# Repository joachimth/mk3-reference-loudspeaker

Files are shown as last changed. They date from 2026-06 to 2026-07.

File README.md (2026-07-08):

# Mk3 Reference Loudspeaker

A DIY active 3-way reference loudspeaker, inspired by Genelec 8361, Dutch & Dutch 8C, and Revel Salon2.



---

## Design Summary

| Parameter | Value |
|---|---|
| Woofers | 2 × GRS 12SW-4HE (push-push, side-mounted) |
| Midrange | ScanSpeak 18W/4424G00 (top of baffle, `cad/midrange.scad`) |
| Tweeter | SB Acoustics SB26STAC-C000-4 in custom waveguide (below the midrange) |
| Cabinet | 300 × 420 × 1180 mm, 22 mm birch plywood |
| Front edges | R19 vertical roundovers |
| Bass volume | ~75 L net sealed (below divider plate) |
| Mid chamber | ~13 L net sealed (top section; datasheet rec. 13 L) |
| Bass / mid crossover | 200 Hz BW4 |
| Mid / tweeter crossover | 1100 Hz LR4 |
| Mid / tweeter c-c | 164 mm (physical minimum; verify from physical parts) |
| DSP gains | Woofer 0 dB (unity), Mid -4.0 dB, Tweeter -9.0 dB |
| Bass alignment | Fc ~41 Hz sealed (→28 Hz, Q 0.707 via Linkwitz Transform) |
| DSP | MiniDSP 4×10 HD |
| System type | Active, DSP-controlled |

### Why SB26STAC-C000-4

| Property | Value |
|---|---|
| Fs | 750 Hz (350 Hz margin at 1100 Hz crossover) |
| Xmax | 0.6 mm (3× more than typical horn tweeters) |
| Sensitivity | 91.5 dB / 2.83V / 1m |
| Impedance | 4 Ω |
| Type | Conventional soft dome, not horn-loaded |

The SB26STAC has a low Fs and generous excursion headroom. At 1100 Hz crossover, it operates 350 Hz above resonance with +8.1 dB excursion margin. Sensitivity matches the 18W/4424G00 midrange within 0.5 dB, requiring only minimal DSP padding. See [tweeter selection analysis](docs/SB26STAC-C000-4_analysis.md) for the full rationale.

---

## Simulation Results

All simulations use real datasheet frequency response curves, baffle step modeling, and waveguide loading estimates. The anechoic plot shows pre-DSP response; the in-room plot adds room gain modeling, level correction, and DSP EQ toward a Harman in-room target.

### Anechoic per-driver crossover sum

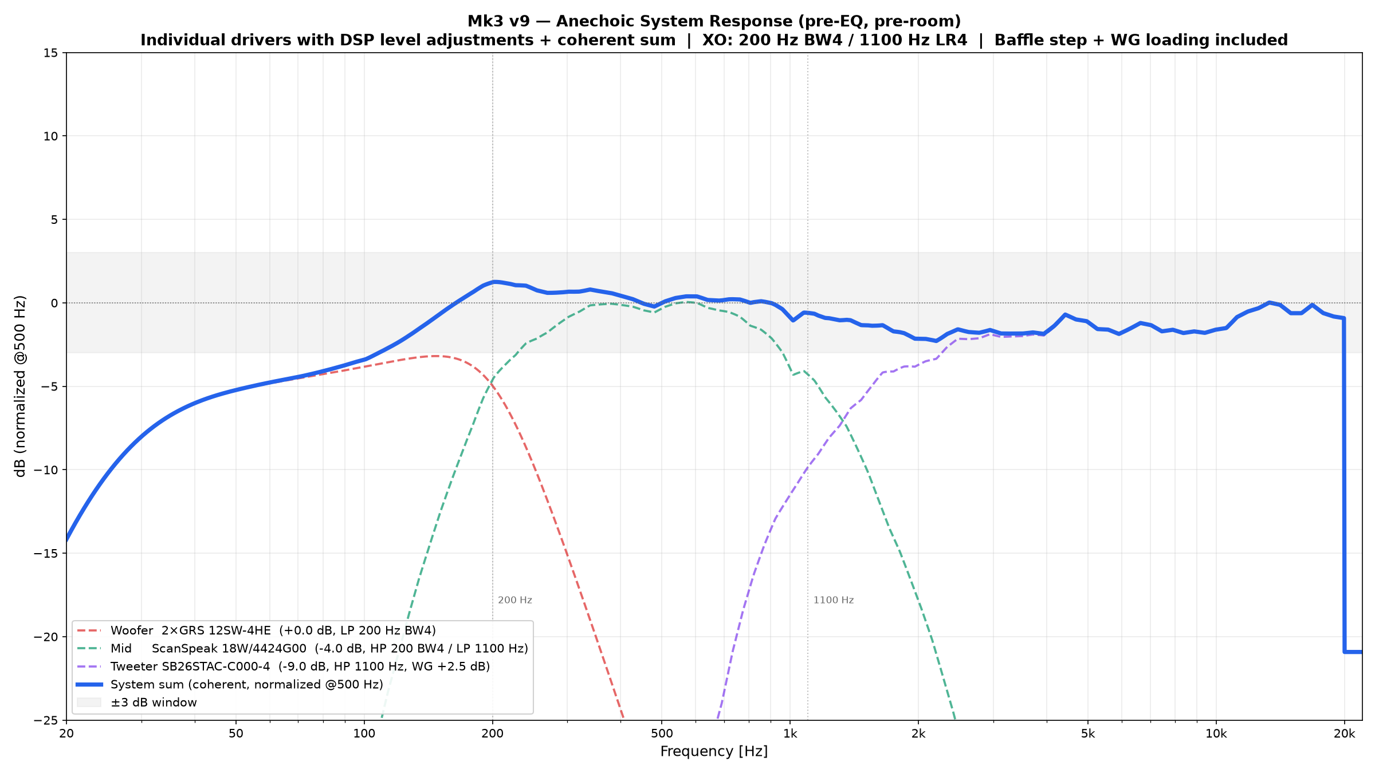
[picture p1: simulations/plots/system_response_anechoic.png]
Anechoic crossover sum


Individual driver curves with DSP level adjustments and coherent sum through LR4 crossovers. No room gain, no EQ — raw anechoic only.

| Driver | DSP gain | Filter |
|---|---|---|
| 2× GRS 12SW-4HE (woofer) | 0.0 dB (unity) | LP 200 Hz BW4, HP 18 Hz subsonic |
| ScanSpeak 18W/4424G00 (mid) | −4.0 dB | HP 200 BW4 / LP 1100 Hz LR4 |
| SB26STAC-C000-4 (tweeter) | −9.0 dB | HP 1100 Hz LR4, WG +2.5 dB |

| Metric | Value |
|---|---|
| Midband ripple (500-10k) | 2.8 dB |
| Sum @ 500 Hz | 0 dB (reference) |
| Sum @ 2 kHz | −2.3 dB |
| Sum @ 10 kHz | −1.8 dB |

**Script:** [system_response_anechoic.py](simulations/system_response_anechoic.py)

### In-room, level-corrected, and post-DSP

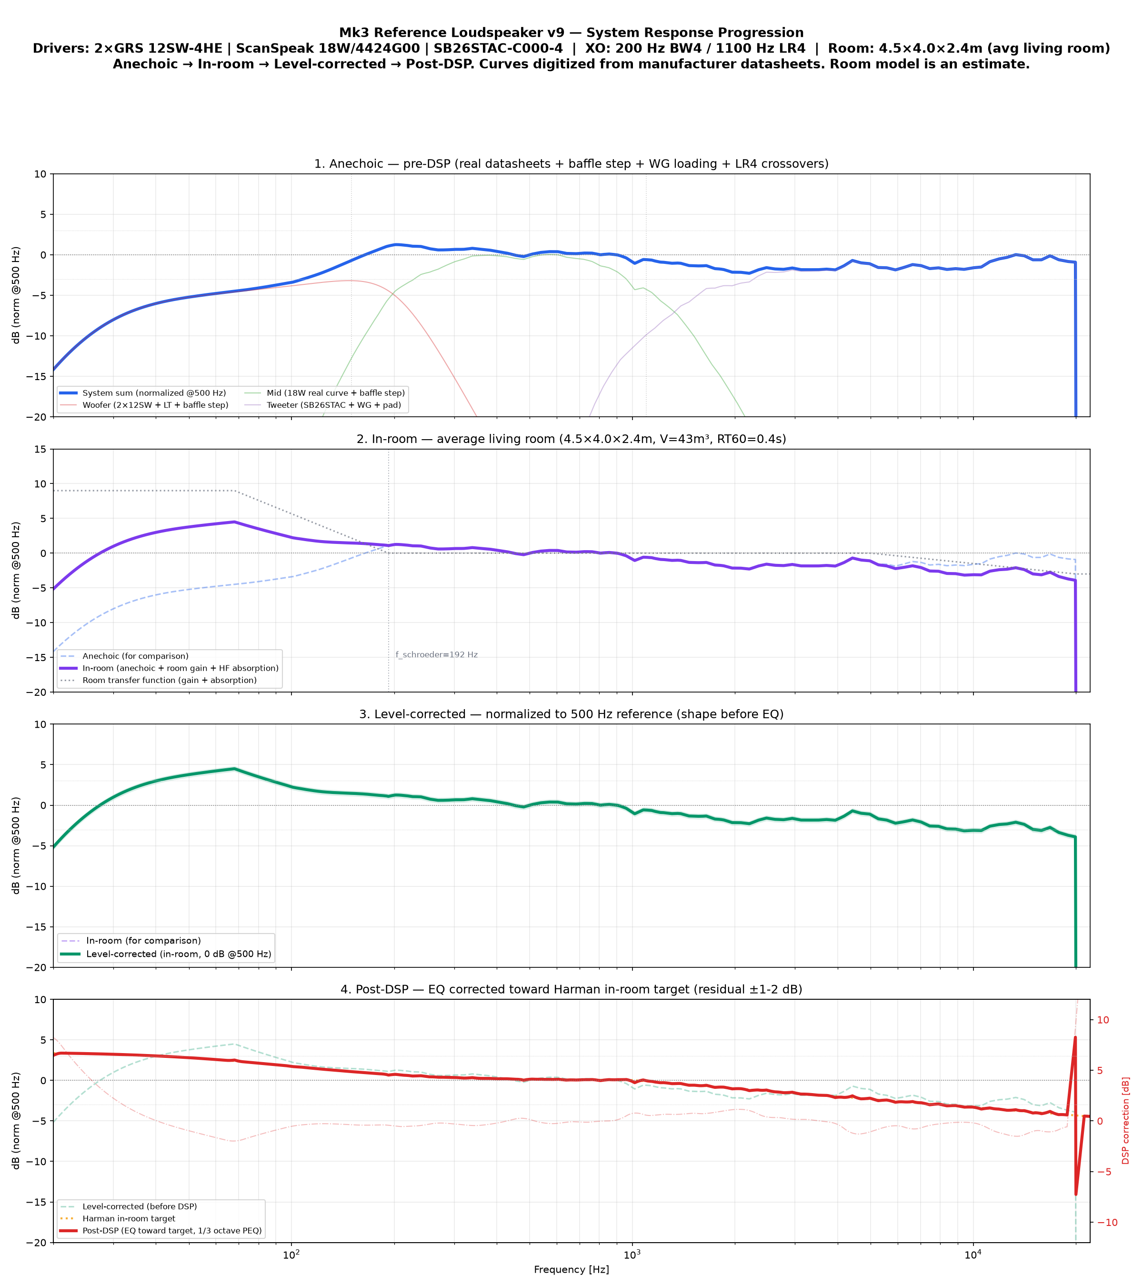
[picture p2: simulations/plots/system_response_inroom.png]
In-room response progression


Four-stage progression from anechoic to post-DSP, modeling an average living room (4.5×4×2.4 m, 43 m³, RT60 0.4s).

**Optimized gains (in-room vs Harman target):**

| Driver | DSP gain |
|---|---|
| 2× GRS 12SW-4HE (woofer) | 0.0 dB (unity) || ScanSpeak 18W/4424G00 (mid) | −4.0 dB |
| SB26STAC-C000-4 (tweeter) | −9.0 dB |

| Stage | Ripple 500-10k | @100 Hz | @500 Hz | @10 kHz |
|---|---|---|---|---|
| Anechoic (pre-DSP) | 2.8 dB | 82.9 | 86.9 | 85.1 |
| In-room | 3.7 dB | 88.6 | 86.9 | 83.6 |
| Level-corrected | 3.7 dB | 1.7 | 0.0 | −3.3 |
| Post-DSP | 3.5 dB* | 1.7 | 0.1 | −3.3 |

*Post-DSP ripple includes intentional Harman bass shelf + HF tilt. Residual deviation from target: ±0.3 dB (500-10k). DSP correction range: ±1.3 dB.

**Script:** [system_response_inroom.py](simulations/system_response_inroom.py)

### In-room gain optimization

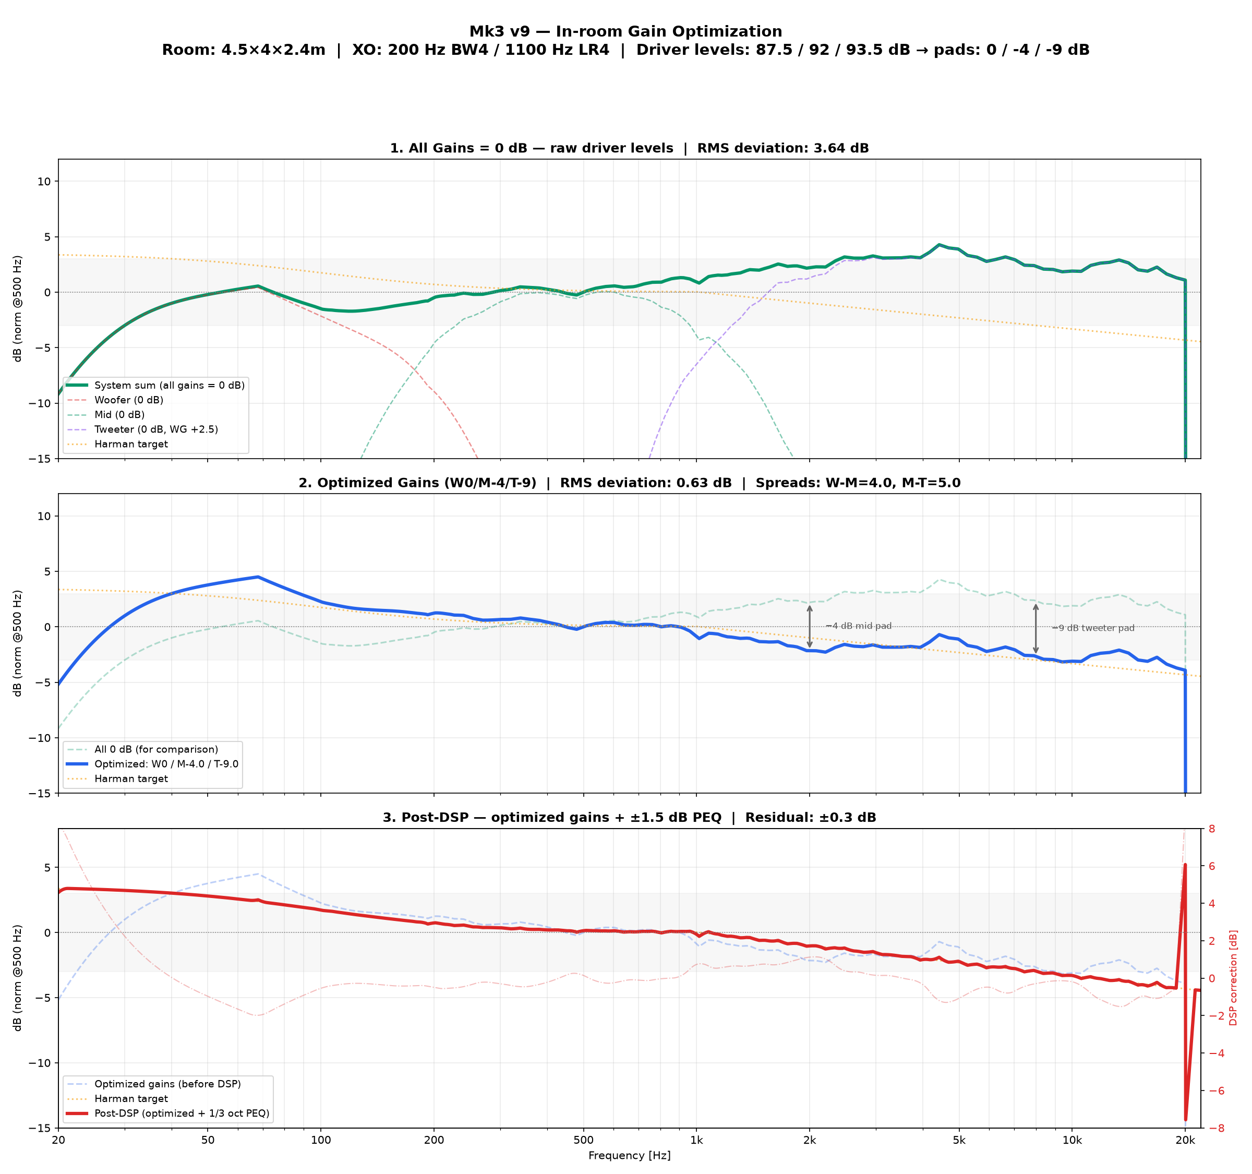
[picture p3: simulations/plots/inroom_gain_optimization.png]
Gain optimization


Three-stage progression showing why gain correction is needed and what it achieves:

| Stage | @100 Hz | @2 kHz | @10 kHz | RMS deviation |
|---|---|---|---|---|
| All gains = 0 dB | −2.1 | +2.0 | +1.7 | 3.59 dB |
| Optimized (W0/M−4/T−9) | +1.7 | −2.3 | −3.3 | 0.59 dB |
| Post-DSP (±1.3 dB PEQ) | +1.7 | −1.0 | −3.3 | 0.06 dB |

Driver sensitivities explain the needed pads: woofer pair 87.5 dB, mid 92.0 dB (+4.5 dB), tweeter+WG 93.5 dB (+6.0 dB). The extra tweeter pad beyond sensitivity matching (−9 vs −6) accounts for the Harman HF tilt target.

The optimizer confirms W0/M−4.0/T−9.0 as optimal at 0.1 dB resolution. Spreads: W−M = 4.0 dB, M−T = 5.0 dB. Woofer at 0 dB unity avoids wasting DAC headroom.

**Script:** [inroom_gain_optimization.py](simulations/inroom_gain_optimization.py)

### Target comparison: Harman vs BBC-style

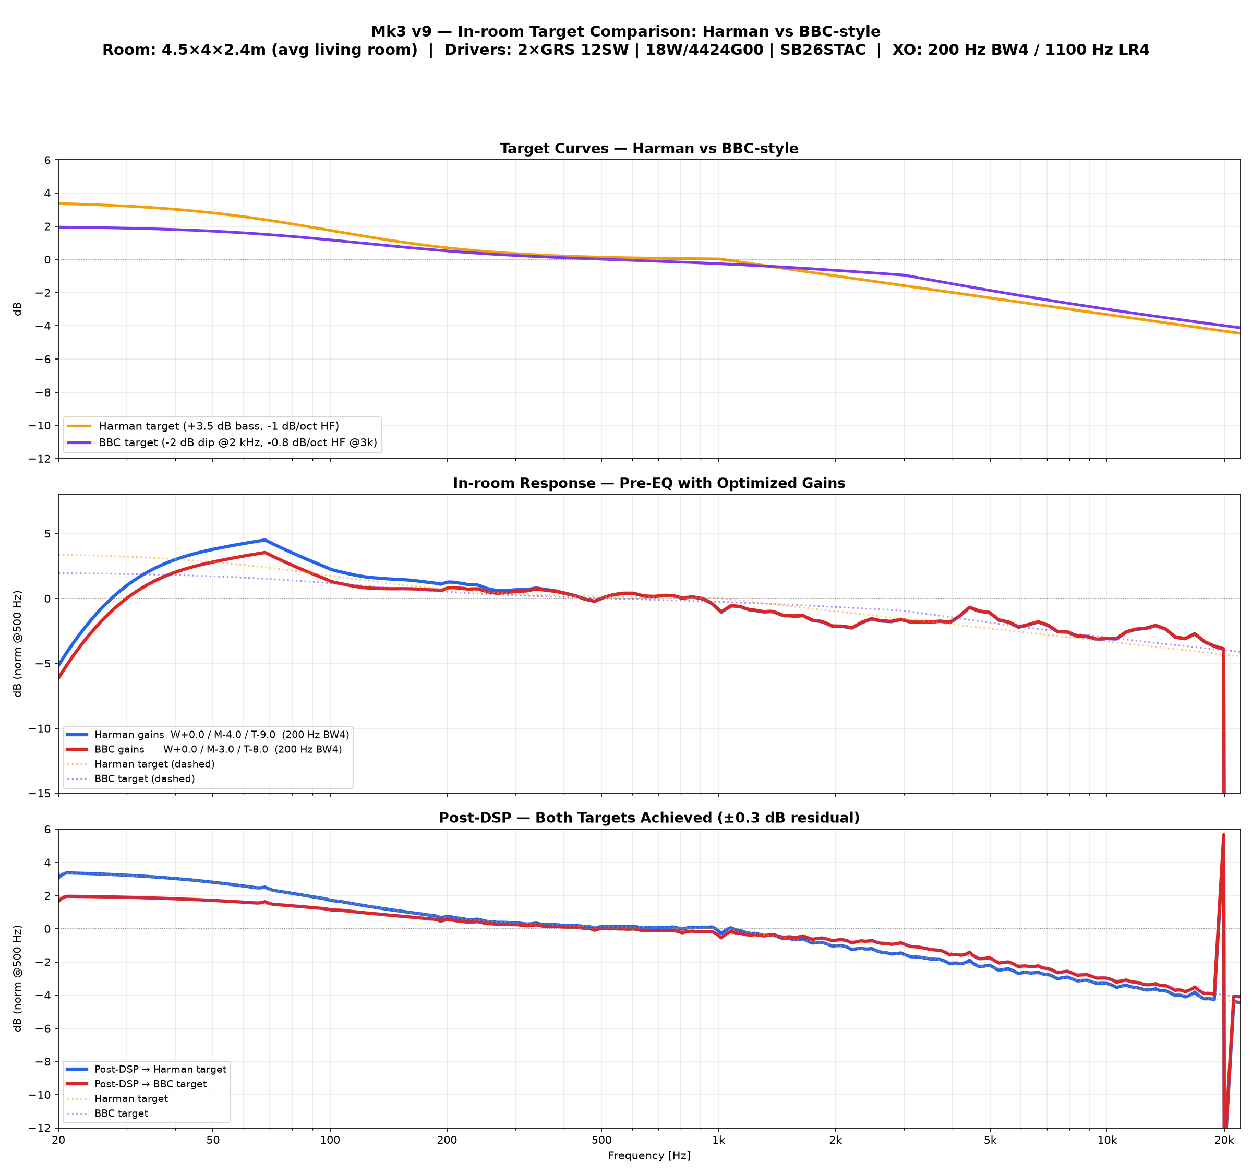
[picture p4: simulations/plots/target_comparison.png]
Target comparison


Two in-room target philosophies with their optimal per-driver gains:

| Target | Woofer | Mid | Tweeter | W-M spread | M-T spread | Character |
|---|---|---|---|---|---|---|
| **Harman** | 0.0 dB | −4.0 dB | −9.0 dB | 4.0 dB | 5.0 dB | Flat, modern, slightly bright |
| **BBC-style** | 0.0 dB | −3.0 dB | −8.0 dB | 3.0 dB | 5.0 dB | Warm, vocal-forward, less fatiguing |

Both share M-T = 5.0 dB spread. BBC needs 1 dB less woofer-to-mid because the −2 dB presence dip at 2 kHz naturally lowers the mid in the critical vocal region. Post-DSP residual: ±0.3 dB for both. DSP correction: Harman ±1.3 dB, BBC ±1.7 dB.

**Harman target:** +3.5 dB bass shelf below 100 Hz, −1 dB/octave HF tilt above 1 kHz (Olive et al. research).
**BBC target:** −2 dB presence dip at 2 kHz, +2 dB bass shelf below 120 Hz, −0.8 dB/octave HF tilt above 3 kHz (LS3/5a school).

**Script:** [target_comparison.py](simulations/target_comparison.py)

### System frequency response

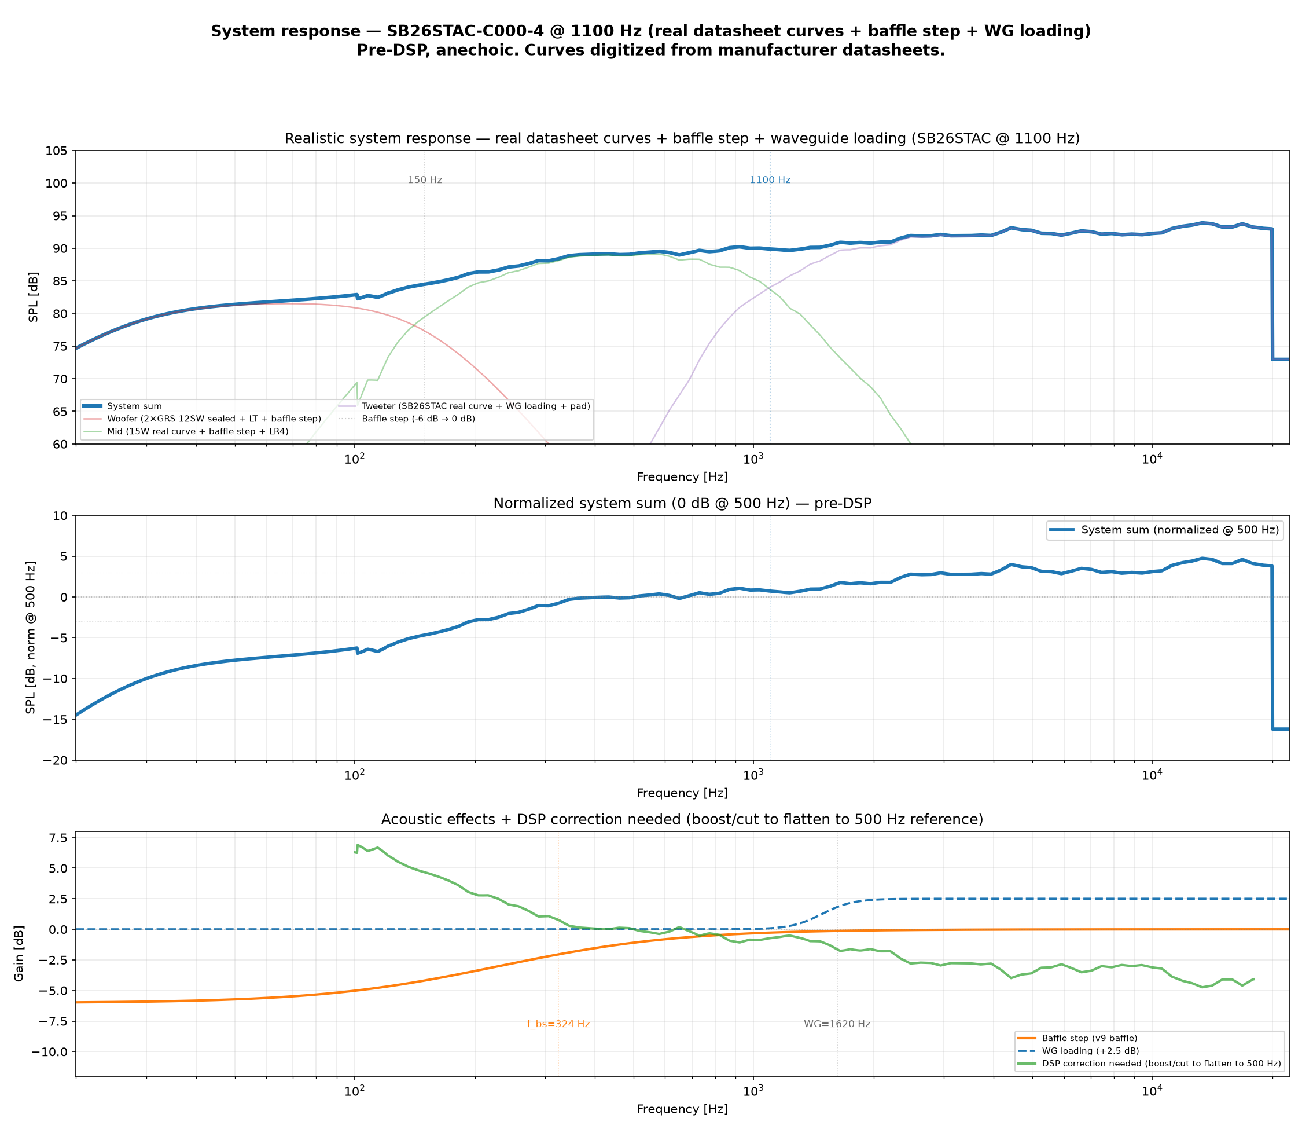
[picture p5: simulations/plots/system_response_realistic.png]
System response


| Metric | Value |
|---|---|
| ±3 dB bandwidth | 623 - 9710 Hz |
| Midband ripple (500-10k) | 4.2 dB |
| DSP correction needed (midband) | ±4.0 dB |
| Sum @ 1100 Hz (crossover) | 89.9 dB |

**Script:** [system_response_realistic.py](simulations/system_response_realistic.py)

### Crossover optimization

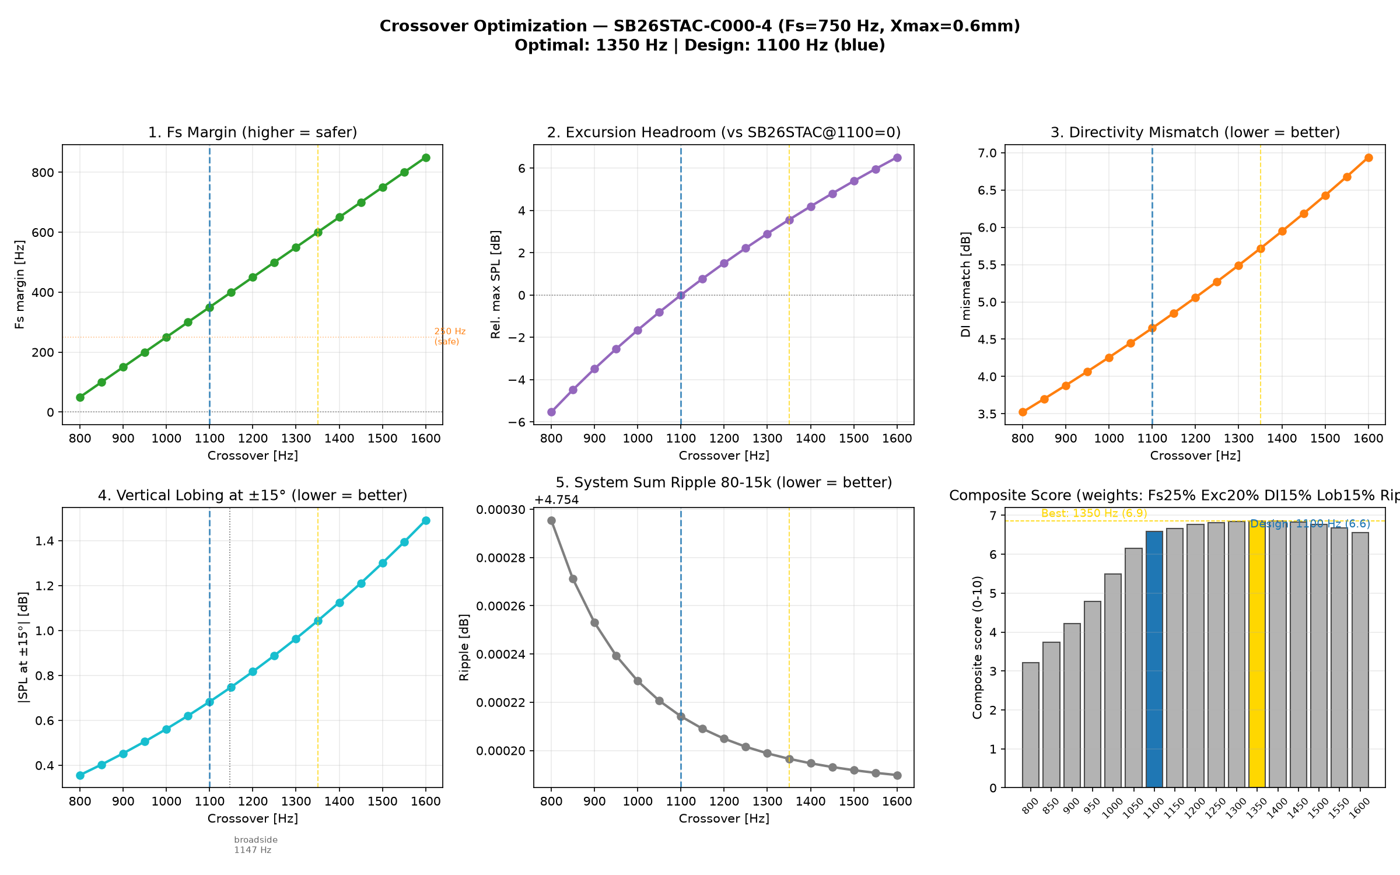
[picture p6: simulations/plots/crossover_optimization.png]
Crossover optimization


Sweep confirms 1100 Hz as optimal crossover frequency for the SB26STAC.

**Script:** [crossover_optimization.py](simulations/crossover_optimization.py)

### Optimal response vs baseline

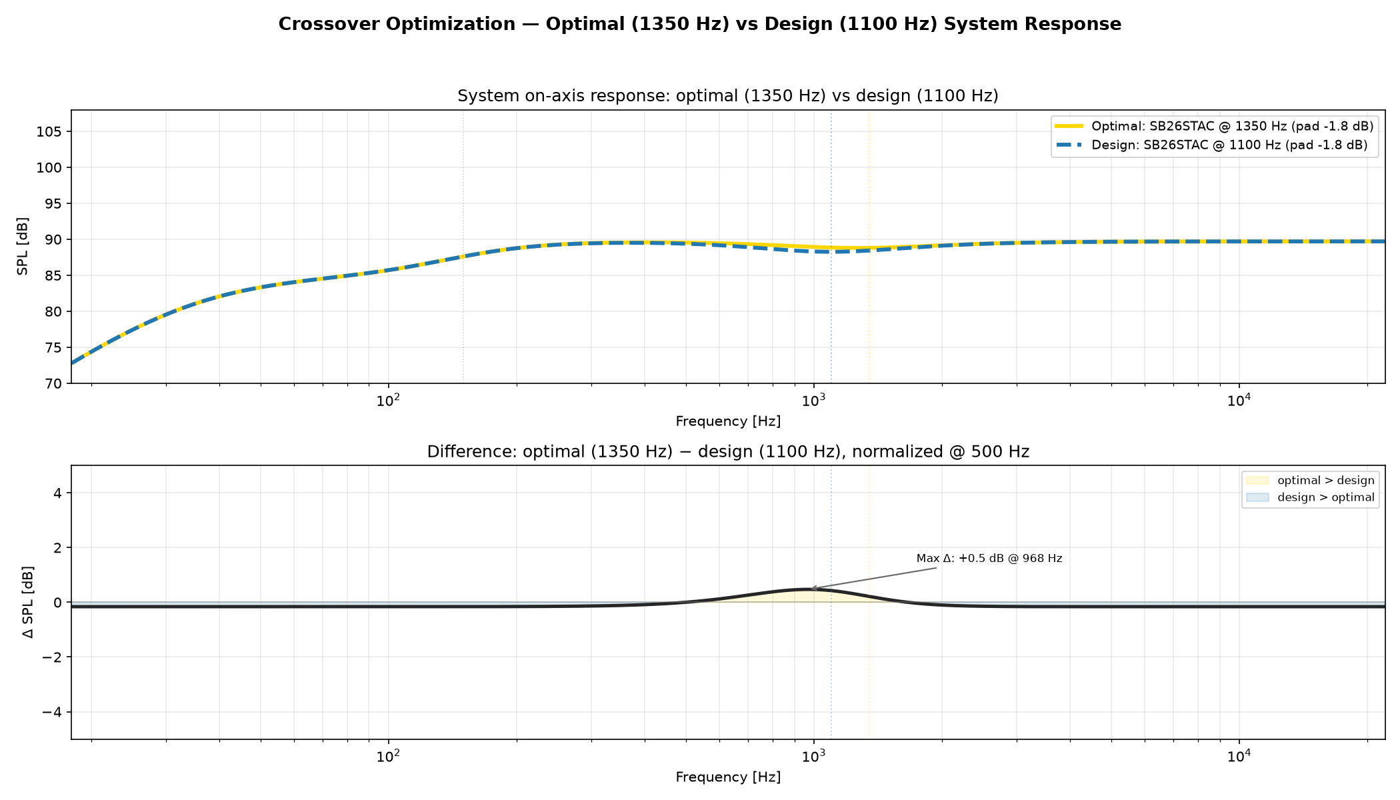
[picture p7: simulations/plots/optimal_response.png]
Optimal response


**Script:** [crossover_optimization.py](simulations/crossover_optimization.py)

### Spinorama estimate

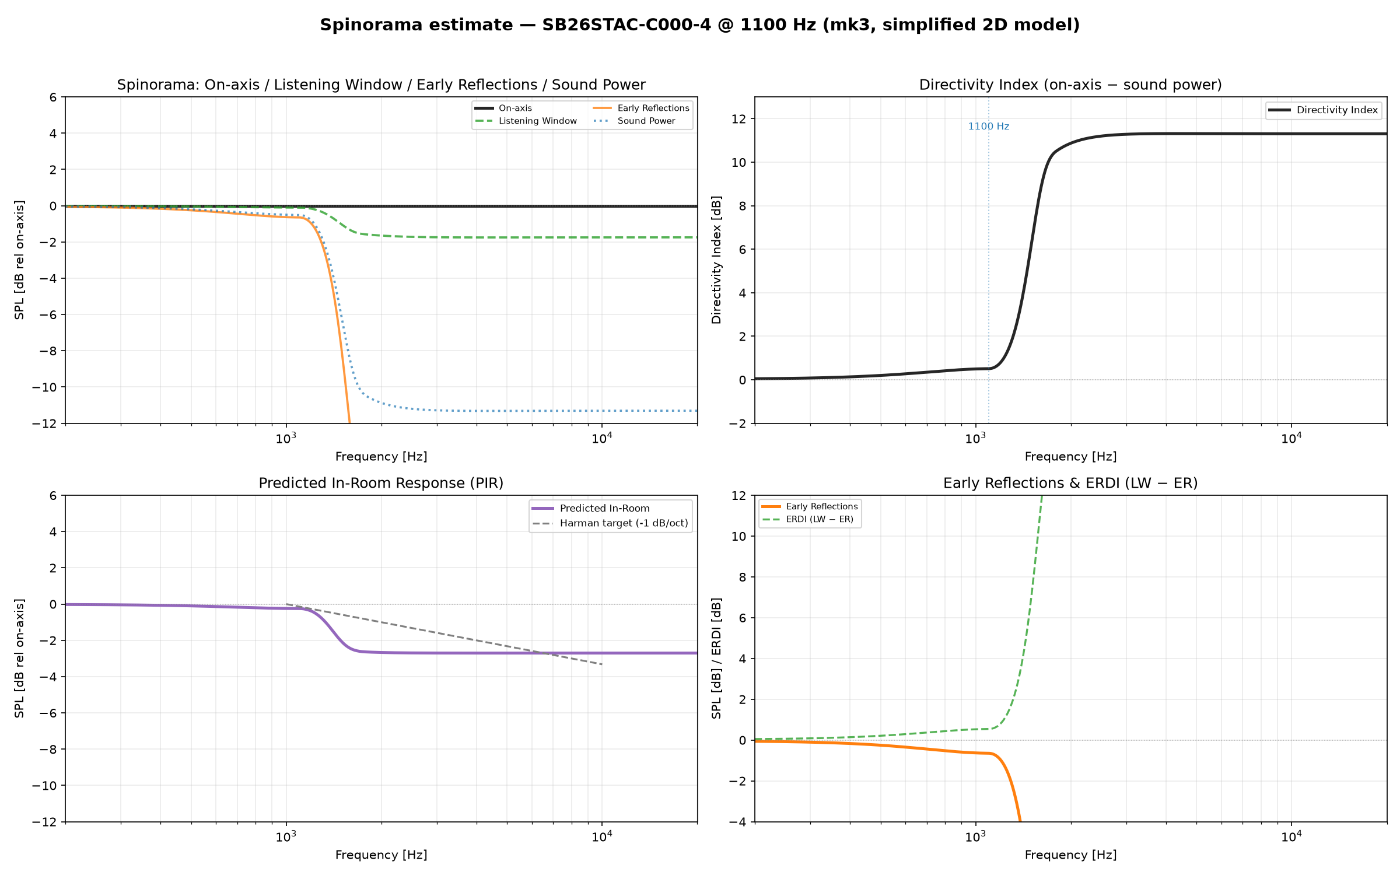
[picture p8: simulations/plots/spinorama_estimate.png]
Spinorama


**Script:** [spinorama_estimate.py](simulations/spinorama_estimate.py)

### System response comparison

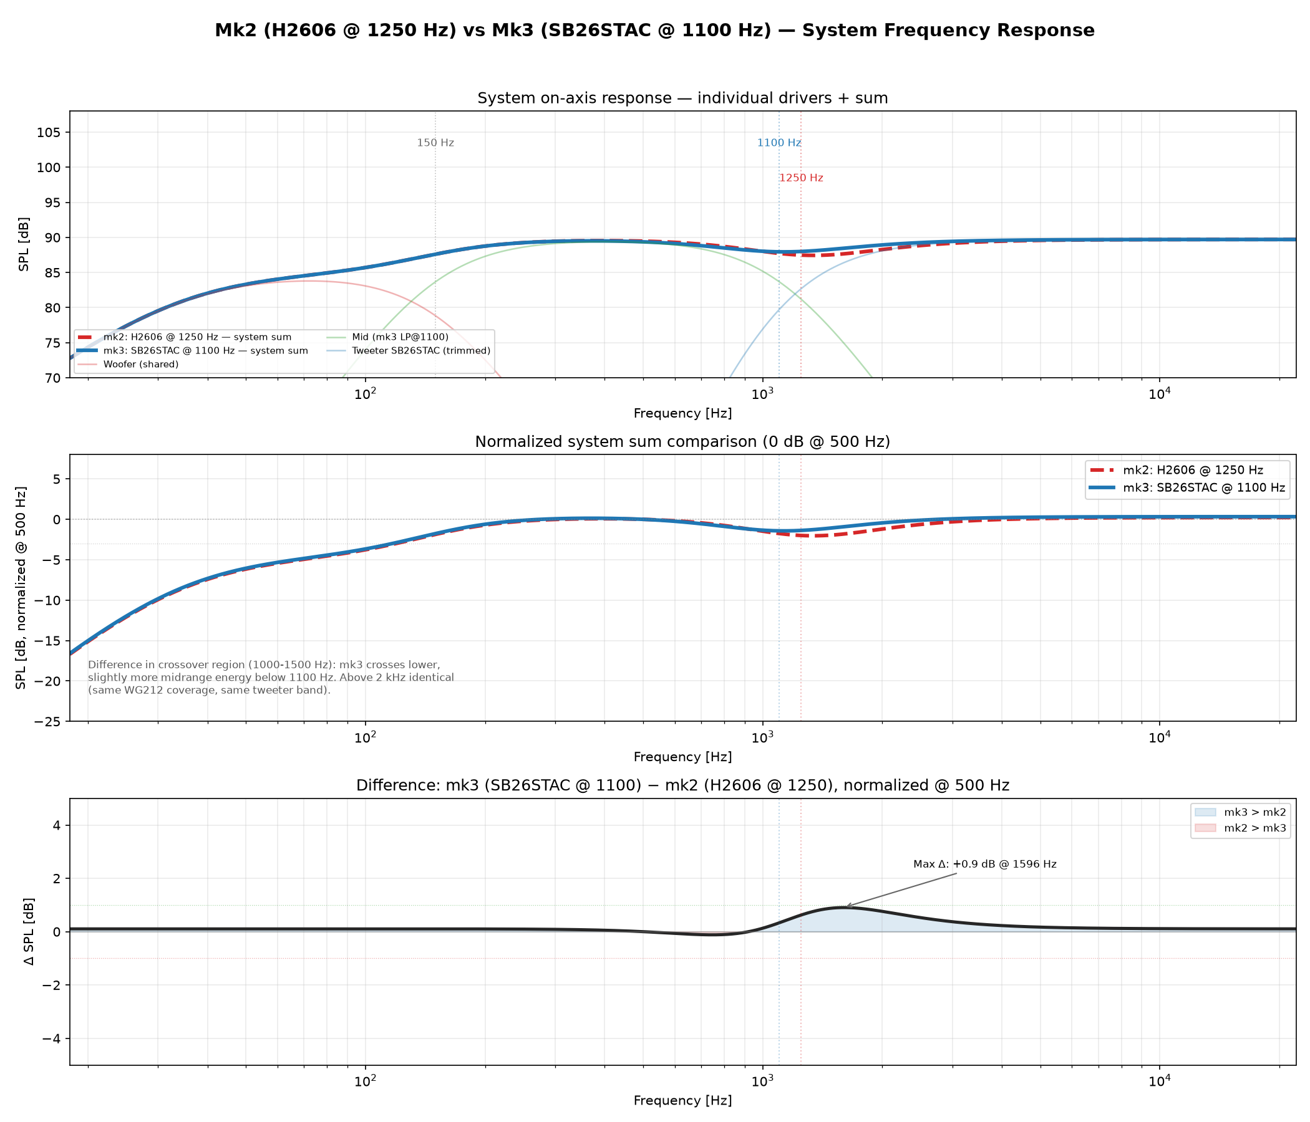
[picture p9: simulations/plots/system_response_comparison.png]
System response comparison


### Tweeter selection analysis

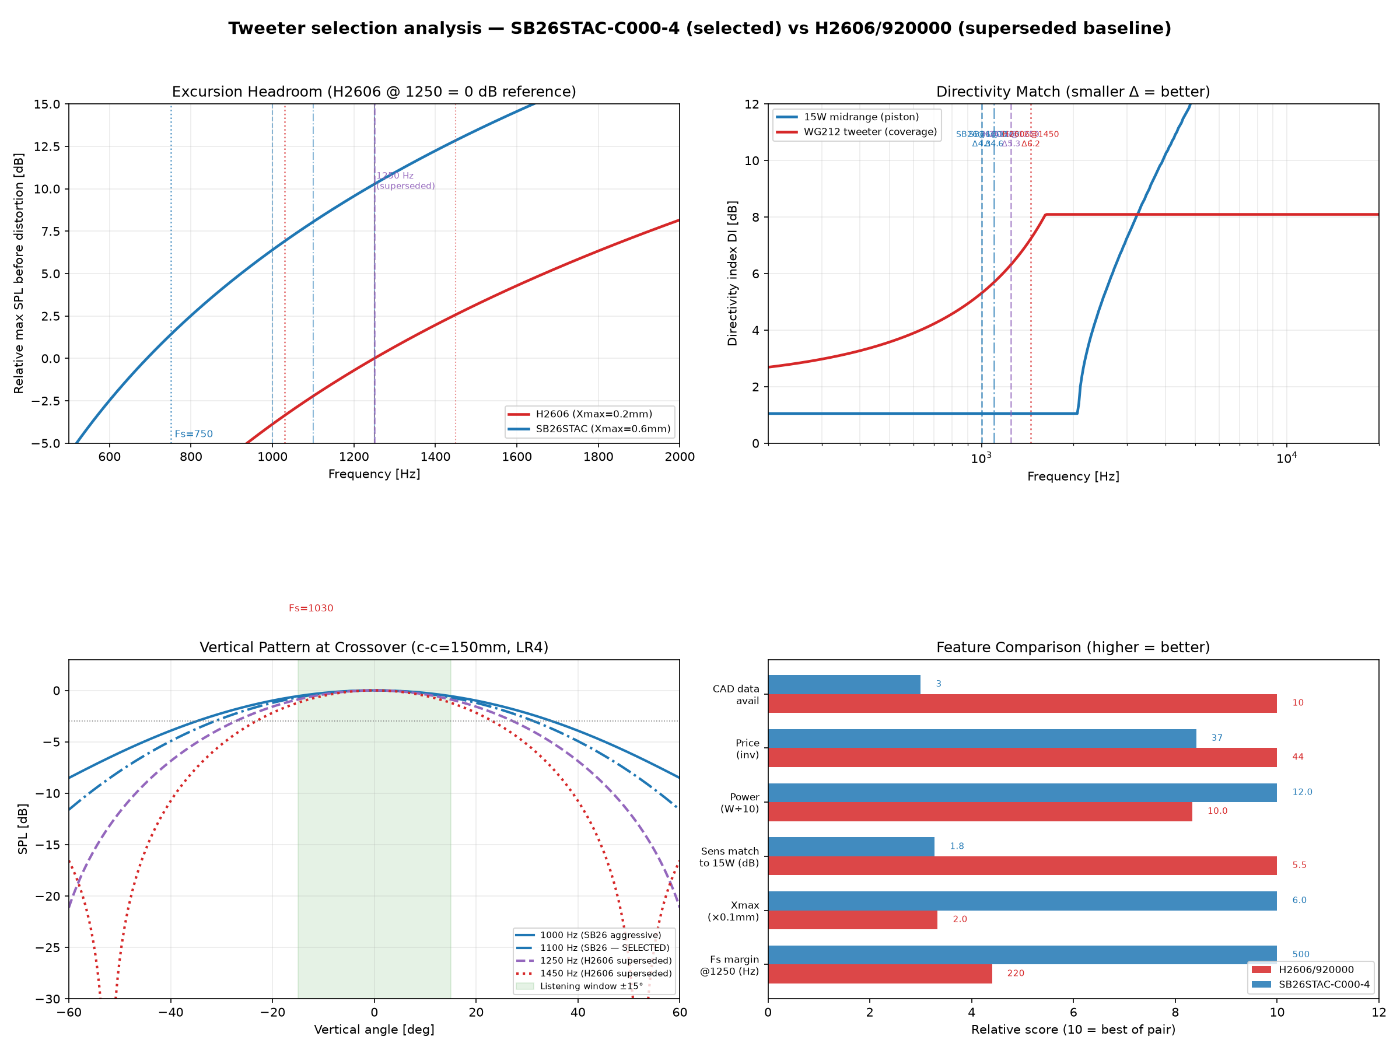
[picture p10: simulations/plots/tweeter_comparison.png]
Tweeter comparison


Historical analysis of why SB26STAC-C000-4 was selected. The H2606/920000 is shown as the evaluated baseline, not a current option.

**Script:** [tweeter_comparison.py](simulations/tweeter_comparison.py)

### Directivity

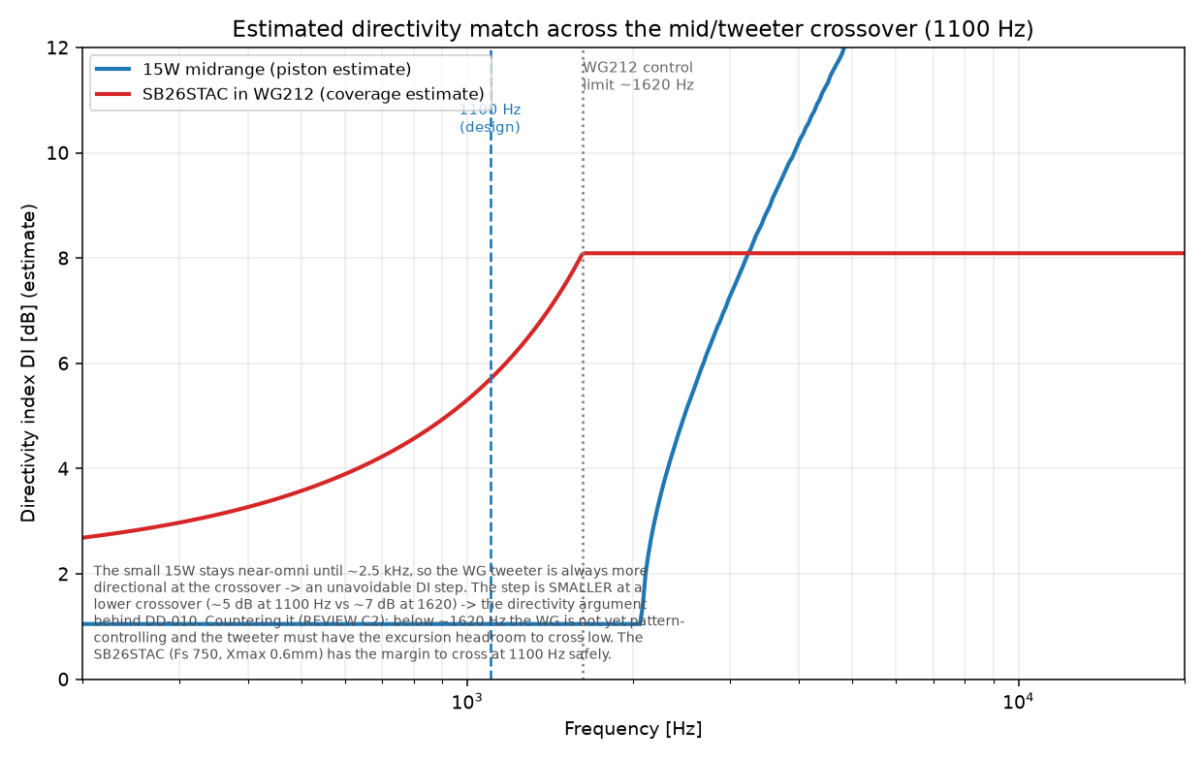
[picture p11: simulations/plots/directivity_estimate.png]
Directivity


**Script:** [directivity_estimate.py](simulations/directivity_estimate.py)

### Vertical polar map

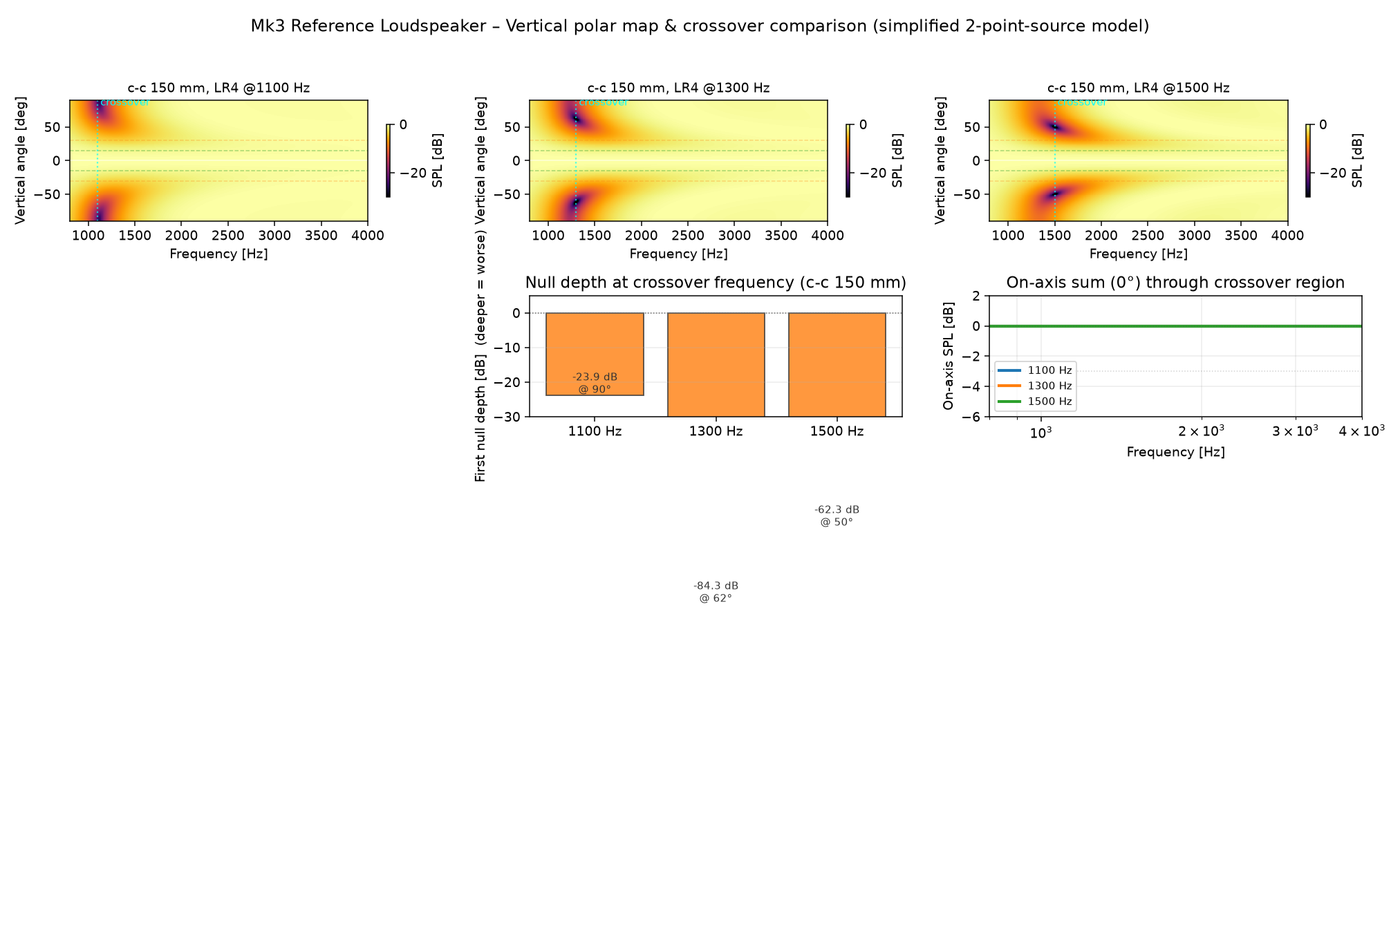
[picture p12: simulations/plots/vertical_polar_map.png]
Vertical polar map


**Script:** [vertical_polar_map.py](simulations/vertical_polar_map.py)

### Vertical lobing

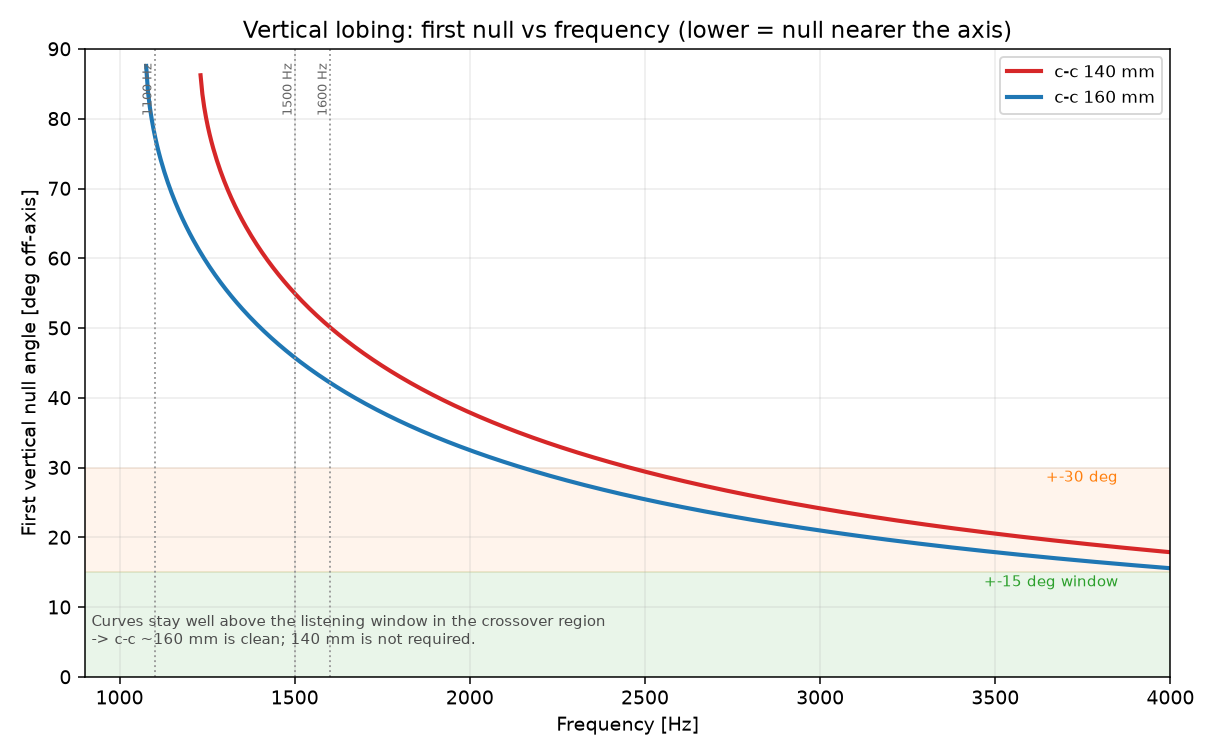
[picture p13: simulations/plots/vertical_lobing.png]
Vertical lobing


**Script:** [vertical_lobing.py](simulations/vertical_lobing.py)

### Polar response

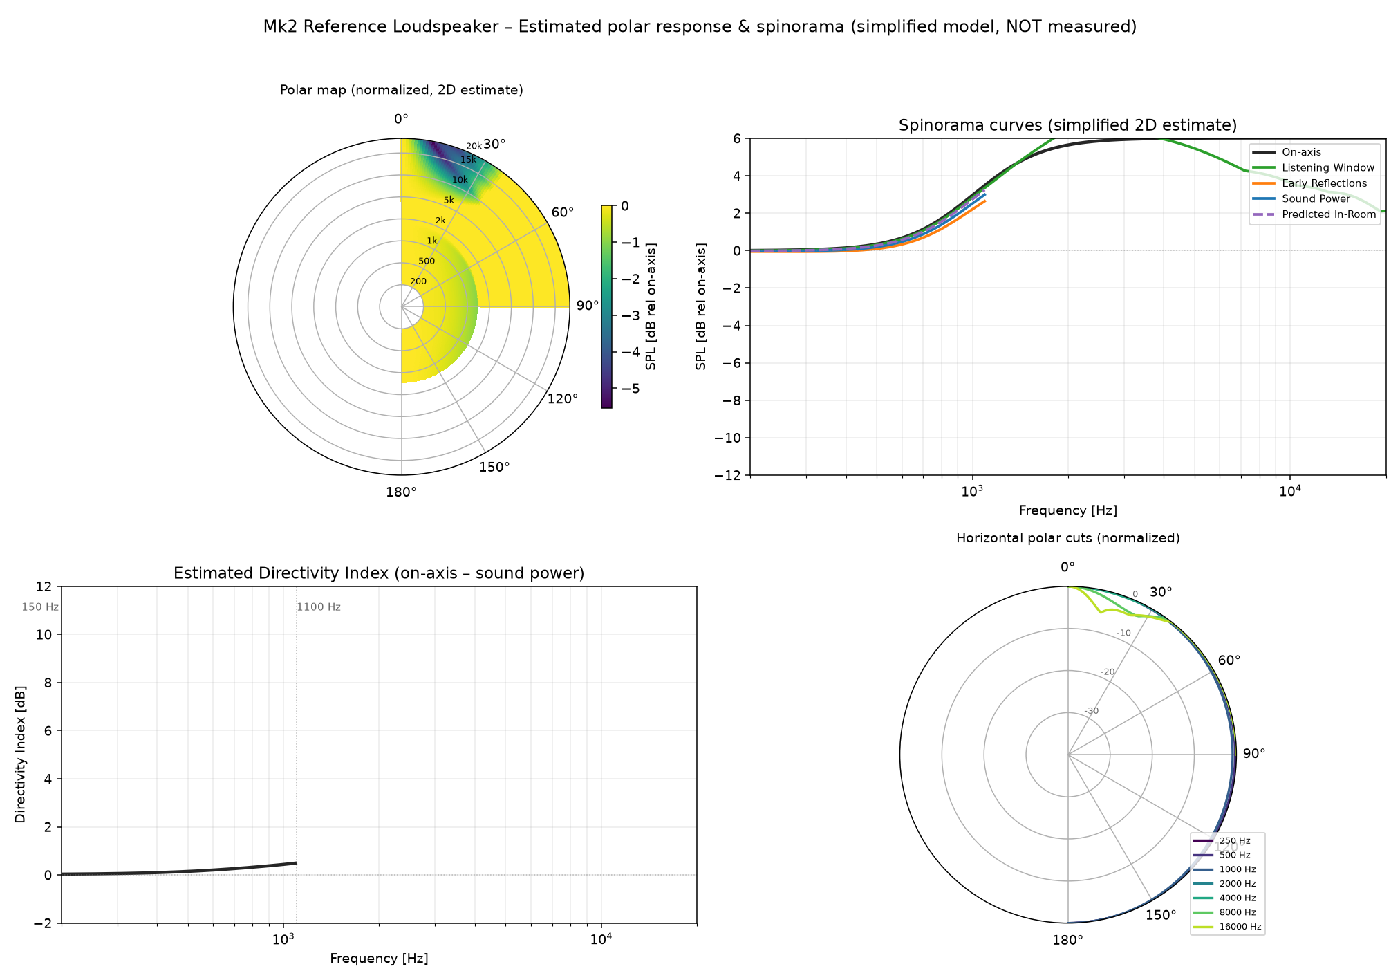
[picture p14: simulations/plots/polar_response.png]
Polar response


**Script:** [polar_response.py](simulations/polar_response.py)

### Bass alignment

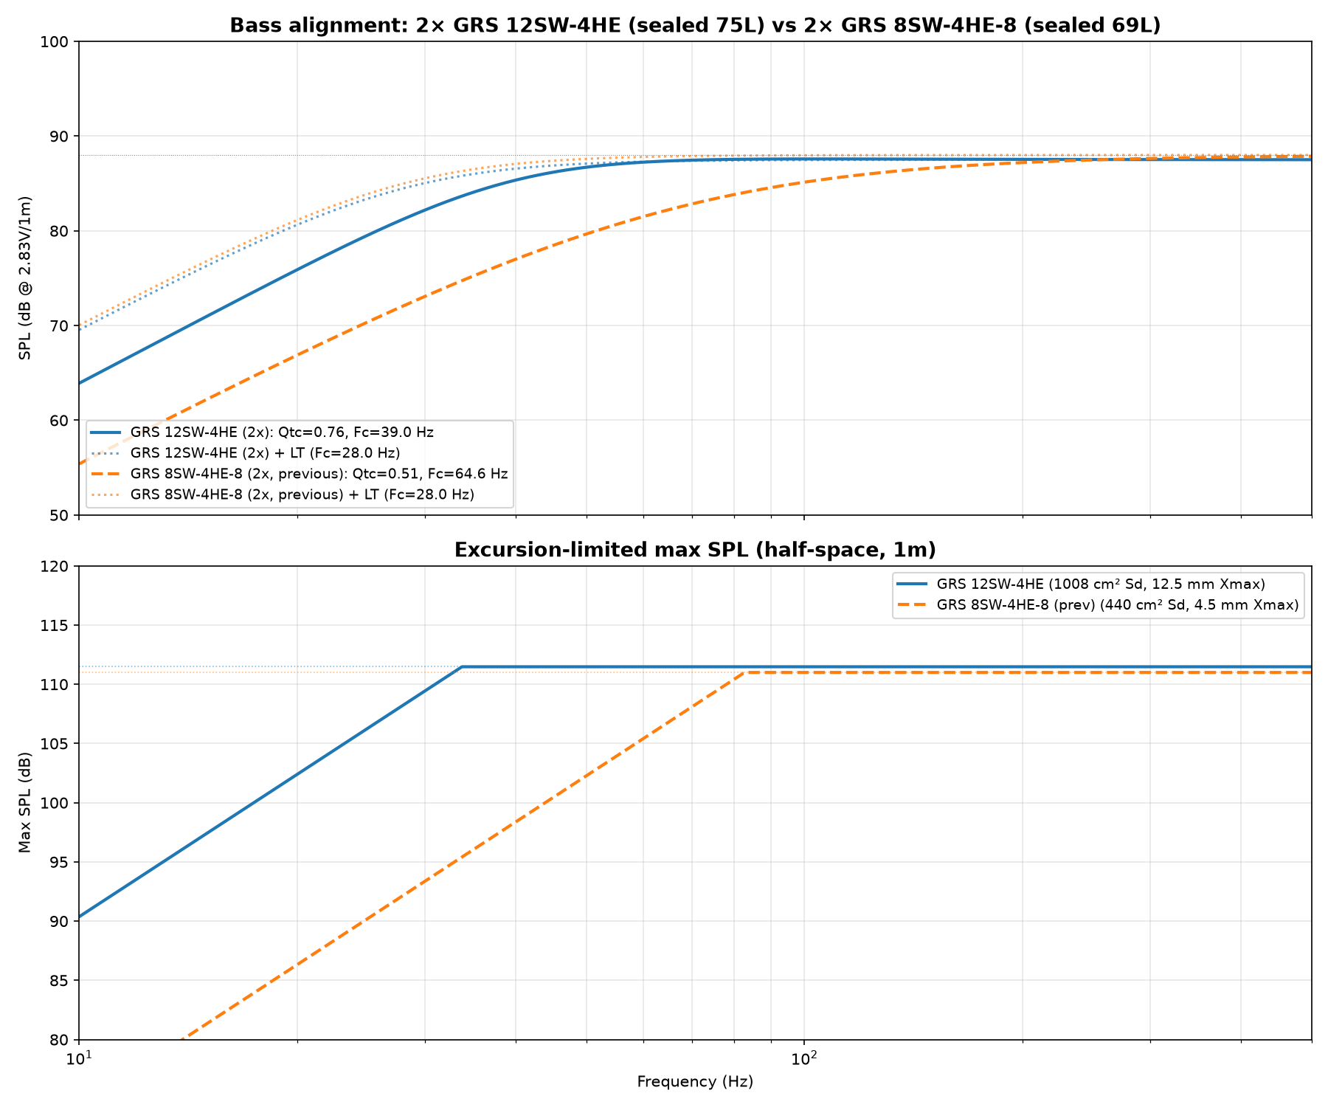
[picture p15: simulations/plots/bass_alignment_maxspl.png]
Bass alignment


**Script:** [bass_alignment_maxspl.py](simulations/bass_alignment_maxspl.py)

### Bass volume comparison

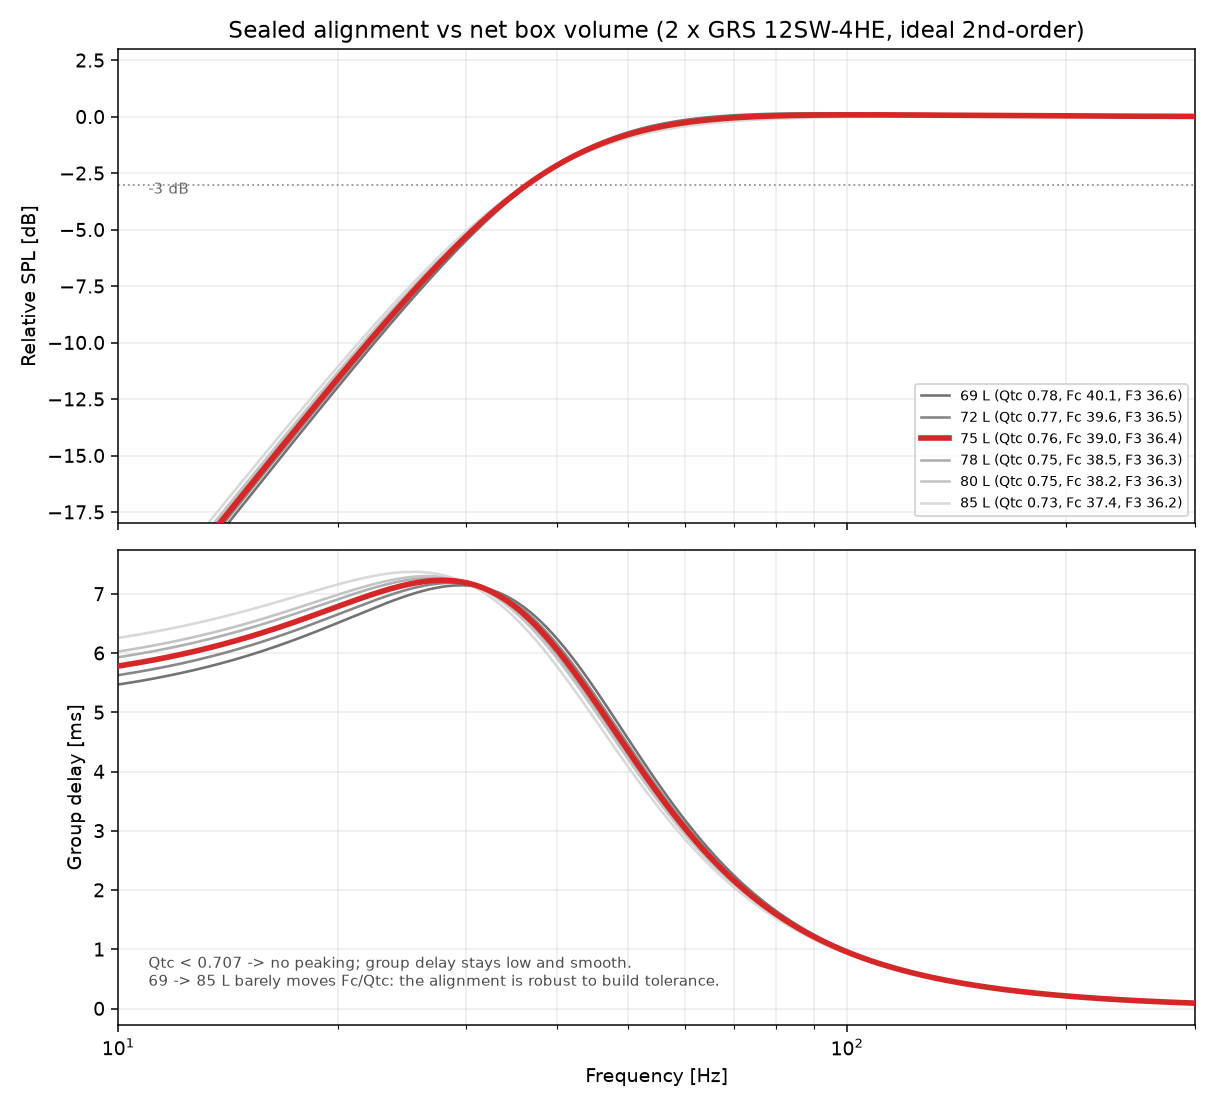
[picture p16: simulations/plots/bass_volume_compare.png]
Bass volume


**Script:** [bass_volume_compare.py](simulations/bass_volume_compare.py)

### Baffle step

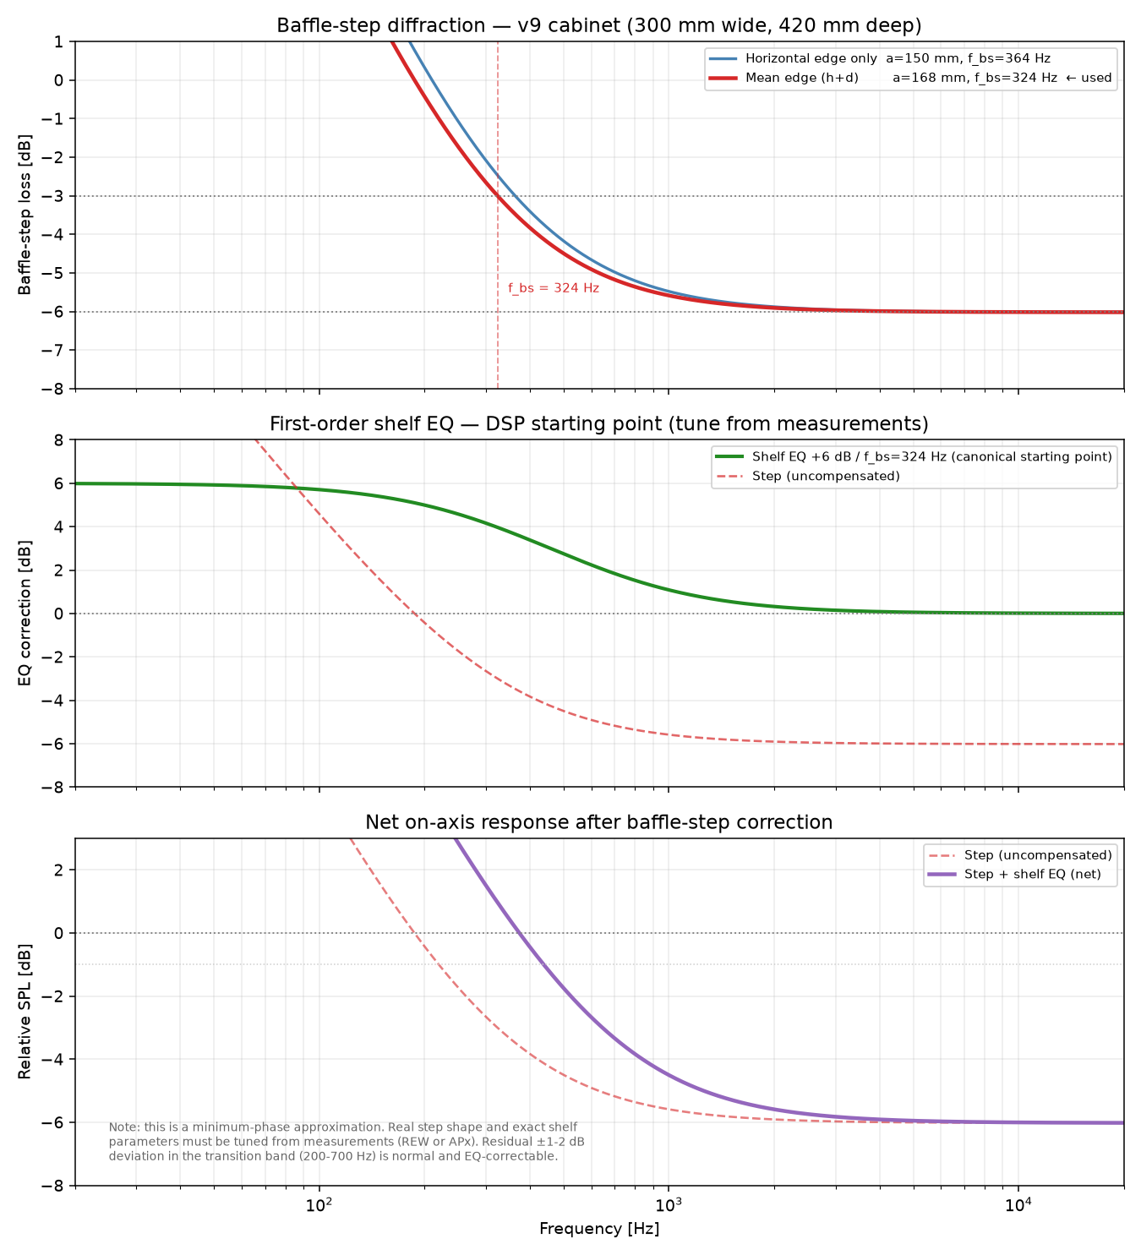
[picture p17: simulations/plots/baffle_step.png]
Baffle step


Baffle step is modeled with separate effective radii for side-mounted woofers vs front-mounted mid/tweeter, parsed from [cabinet.scad](cad/cabinet.scad) via [cabinet_params.py](simulations/cabinet_params.py):

| Driver | Mount | Baffle dimension | Effective radius | f_bs |
|---|---|---|---|---|
| 2× GRS 12SW-4HE | Side panel | D = 420 mm | 210 mm | 259 Hz |
| 18W/4424G00 | Front baffle | W = 320 mm | 160 mm | 341 Hz |
| SB26STAC-C000-4 | Front baffle | W = 320 mm | 160 mm | 341 Hz |

All simulation scripts import from `cabinet_params.py` which parses `cad/cabinet.scad` at runtime. CI validates consistency on every push.

**Scripts:** [baffle_step.py](simulations/baffle_step.py), [cabinet_params.py](simulations/cabinet_params.py)

### Waveguide profile

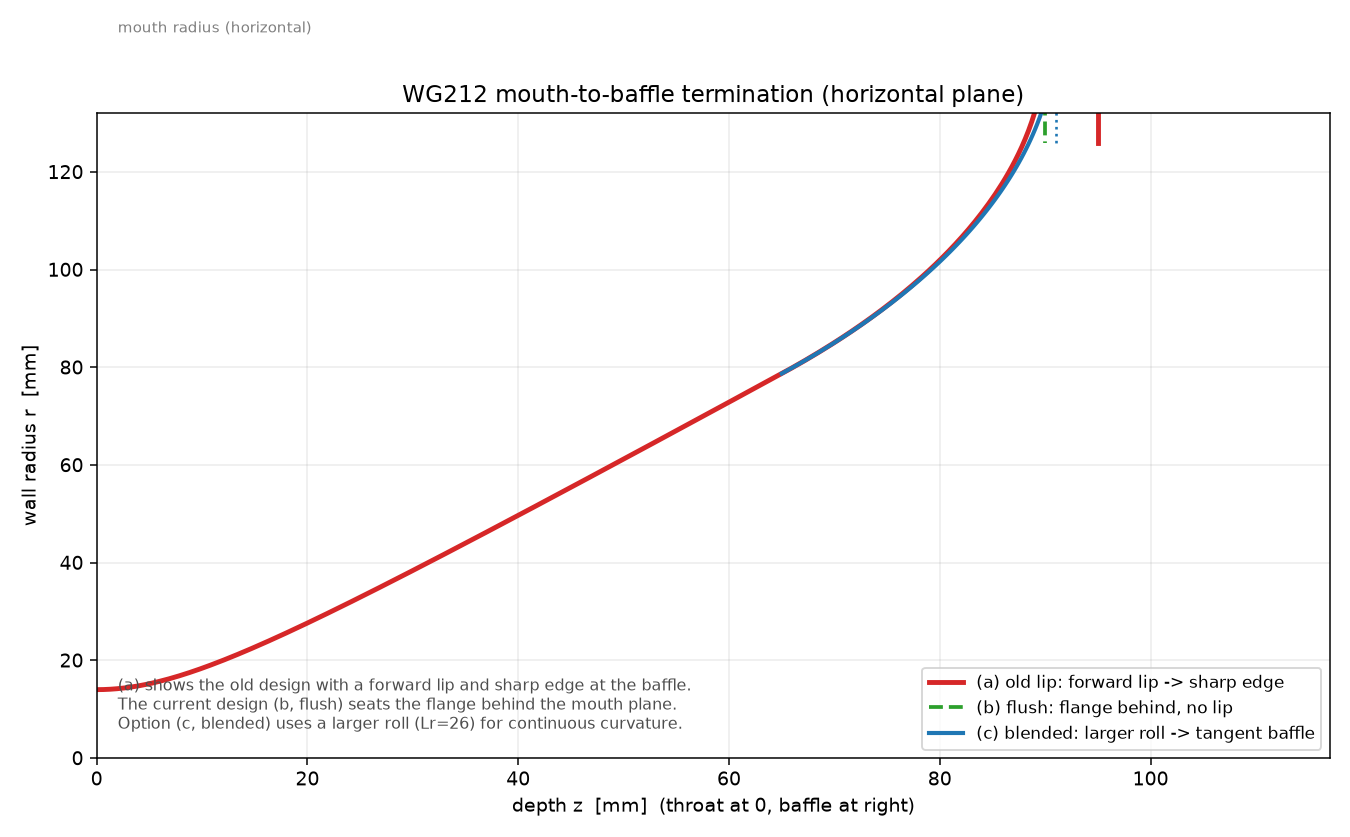
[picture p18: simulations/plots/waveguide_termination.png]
Waveguide profile


**Script:** [waveguide_profile.py](simulations/waveguide_profile.py)

### All simulation scripts

| Script | What it computes | Output |
|---|---|---|
| `bass_alignment_maxspl.py` | Sealed alignment + excursion-limited max-SPL + Linkwitz Transform | `bass_alignment_maxspl.png` |
| `bass_volume_compare.py` | Sealed alignment sensitivity to box volume (64-72 L) | `bass_volume_compare.png` |
| `baffle_step.py` | Baffle step diffraction model (standalone visualization) | `baffle_step.png` |
| `cabinet_params.py` | Parses cabinet.scad for dimensions; provides side/front baffle step functions | — (module) |
| `waveguide_profile.py` | Waveguide mouth-to-baffle termination cross-section | `waveguide_termination.png` |
| `directivity_estimate.py` | Directivity index across crossover | `directivity_estimate.png` |
| `vertical_lobing.py` | Vertical interference-null angle vs frequency | `vertical_lobing.png` |
| `vertical_polar_map.py` | Vertical 2D heat-map vs frequency | `vertical_polar_map.png` |
| `polar_response.py` | 2D polar map + spinorama curves + horizontal polar cuts | `polar_response.png` |
| `system_response_realistic.py` | Full system response with real datasheet curves | `system_response_realistic.png` |
| `system_response_anechoic.py` | Per-driver crossover sum, anechoic, pre-EQ, pre-room | `system_response_anechoic.png` |
| `system_response_inroom.py` | 4-stage: anechoic → in-room → level-corrected → post-DSP | `system_response_inroom.png` |
| `target_comparison.py` | Harman vs BBC-style in-room targets with optimal gains | `target_comparison.png` |
| `inroom_gain_optimization.py` | In-room response: all-zero vs optimized gains vs post-DSP, with sensitivity analysis | `inroom_gain_optimization.png` |
| `spinorama_estimate.py` | Spinorama estimate (on-axis, LW, ER, SP, DI) | `spinorama_estimate.png` |
| `crossover_optimization.py` | Crossover frequency sweep (800-1600 Hz) | `crossover_optimization.png` |
| `tweeter_comparison.py` | SB26STAC selection analysis (excursion, sensitivity, directivity) | `tweeter_comparison.png` |

See [SIMULATIONS.md](SIMULATIONS.md) for assumptions and methodology. See [simulations/README.md](simulations/README.md) for running instructions.

---

## CAD

### Waveguide (SB26STAC-C000-4)

| | |
|:---:|:---:|
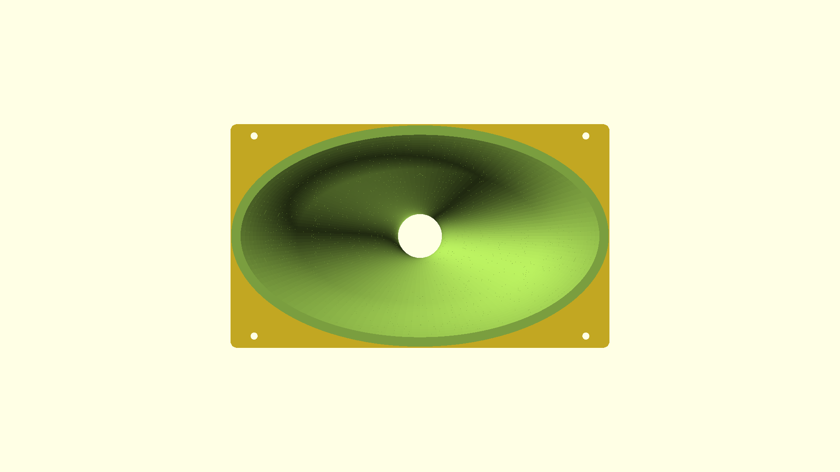
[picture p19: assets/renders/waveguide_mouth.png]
Mouth
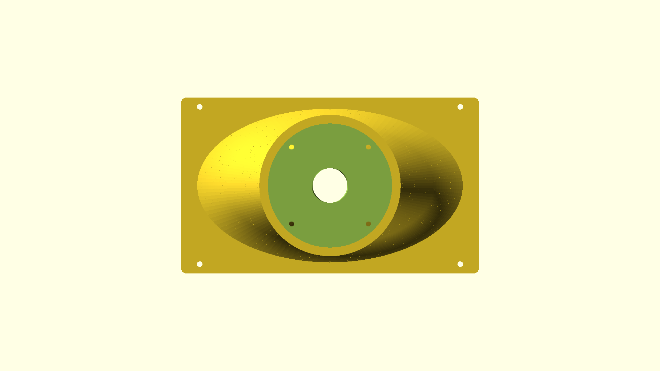
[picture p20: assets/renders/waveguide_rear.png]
Rear
|  |  |
| Mouth (front) | Rear / back plate |
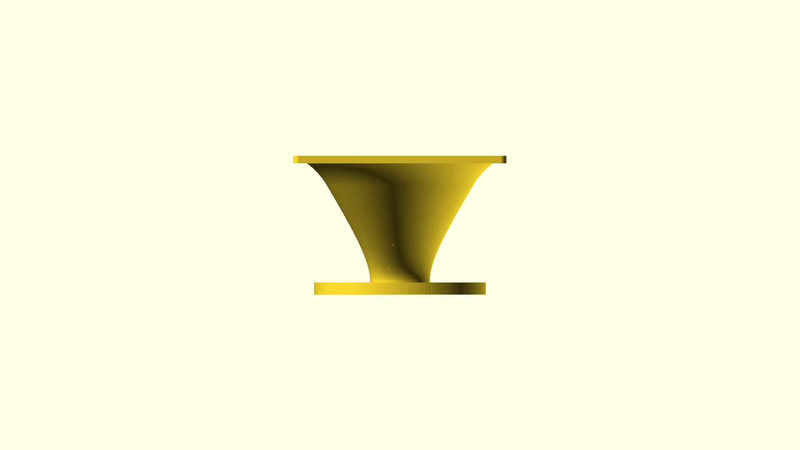
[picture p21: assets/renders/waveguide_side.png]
Side
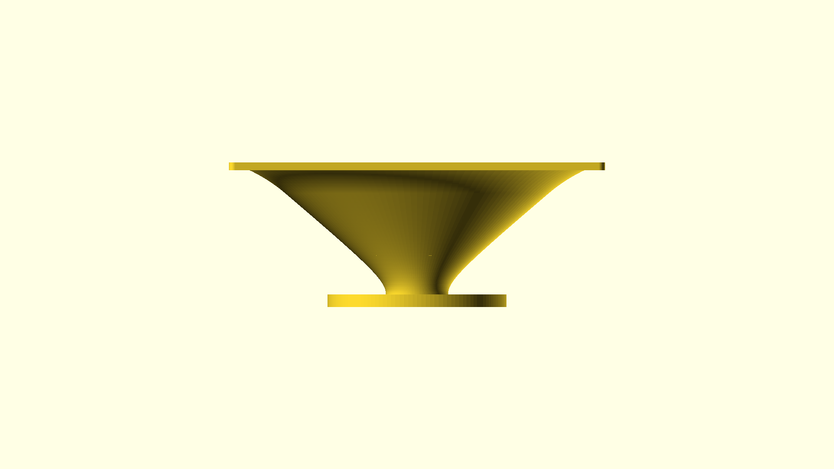
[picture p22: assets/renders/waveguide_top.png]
|  |  |
| Side profile | Top (throat view) |
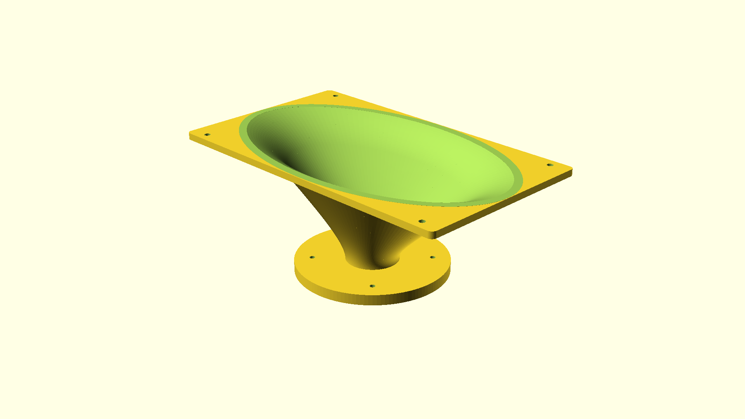
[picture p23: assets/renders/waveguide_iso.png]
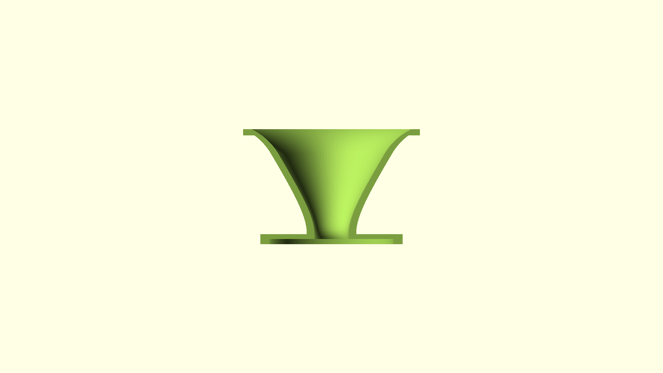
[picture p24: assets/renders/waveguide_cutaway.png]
Cutaway
|  |  |
| Isometric | Half-section cutaway |

**CAD:** `cad/waveguide.scad` | **STL:** `cad/exports/waveguide.stl`

Key dimensions (verify with calipers before printing):

| Dimension | Value |
|---|---|
| Throat diameter | 28 mm (dome + surround) |
| BCD (screw circle) | 88.5 mm |
| Faceplate OD | ~100 mm |
| Waveguide type | Oblate spheroid, non-horn-loaded |

### Cabinet

| | |
|:---:|:---:|
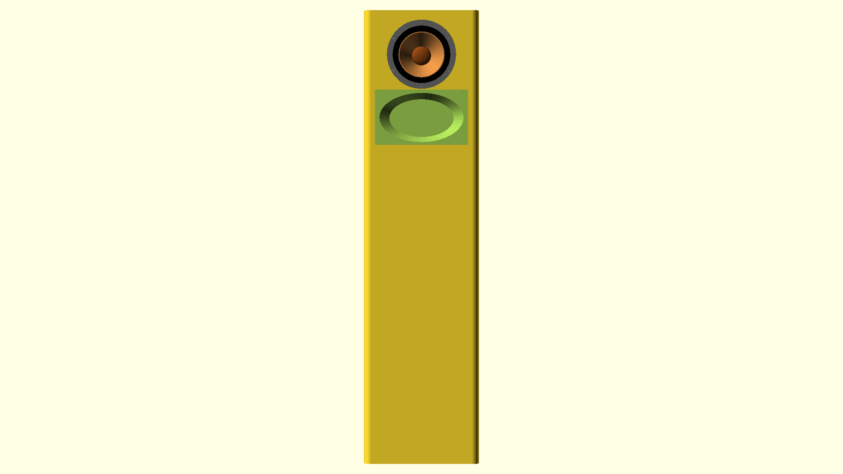
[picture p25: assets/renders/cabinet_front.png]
Front
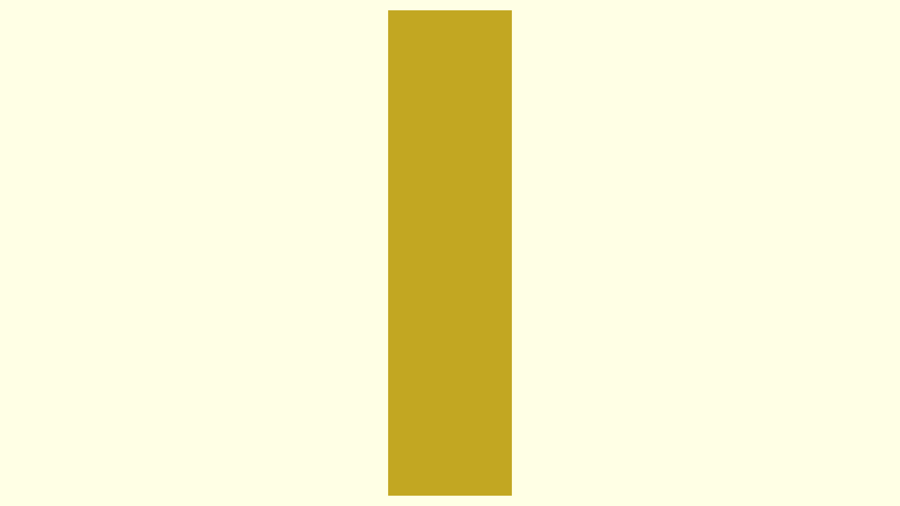
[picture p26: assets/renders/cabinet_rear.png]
Rear
|  |  |
| Front (baffle with drivers) | Rear panel |
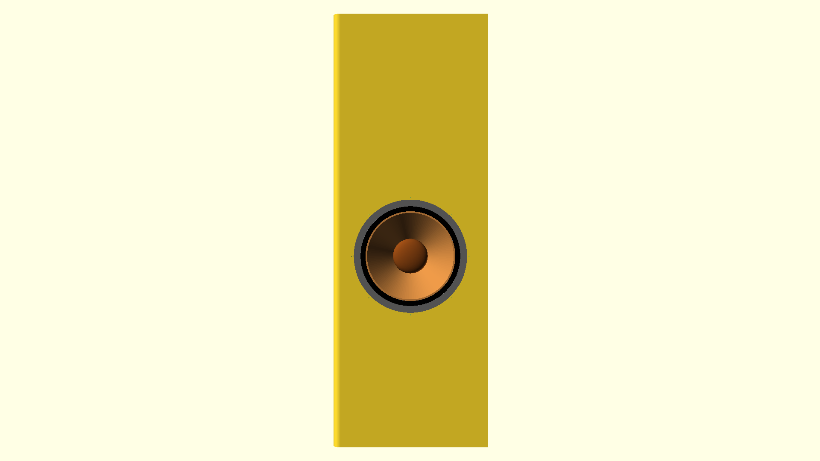
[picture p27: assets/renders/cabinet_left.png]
Left
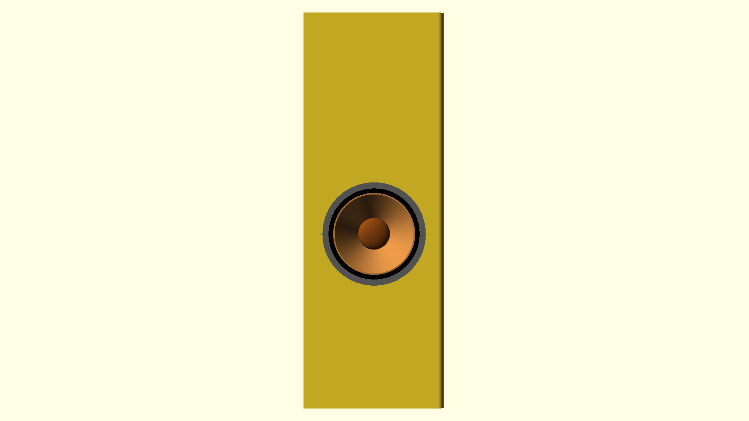
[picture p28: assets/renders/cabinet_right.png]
Right
|  |  |
| Left side (woofer) | Right side (woofer) |
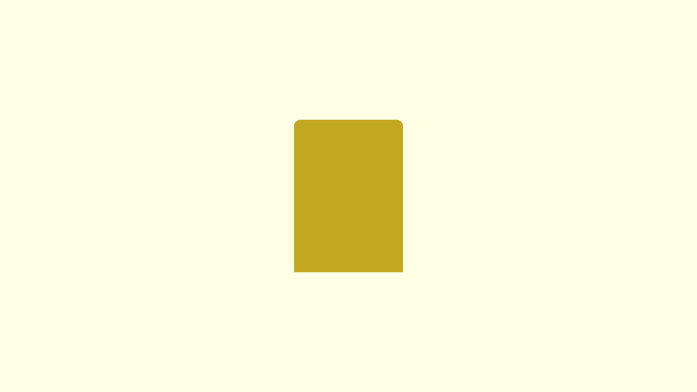
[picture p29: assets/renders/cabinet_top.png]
|  | Bottom |
| Top | Bottom |
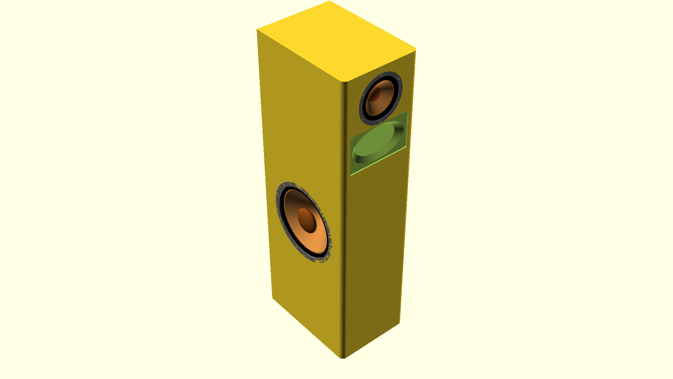
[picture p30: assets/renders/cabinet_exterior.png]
Exterior
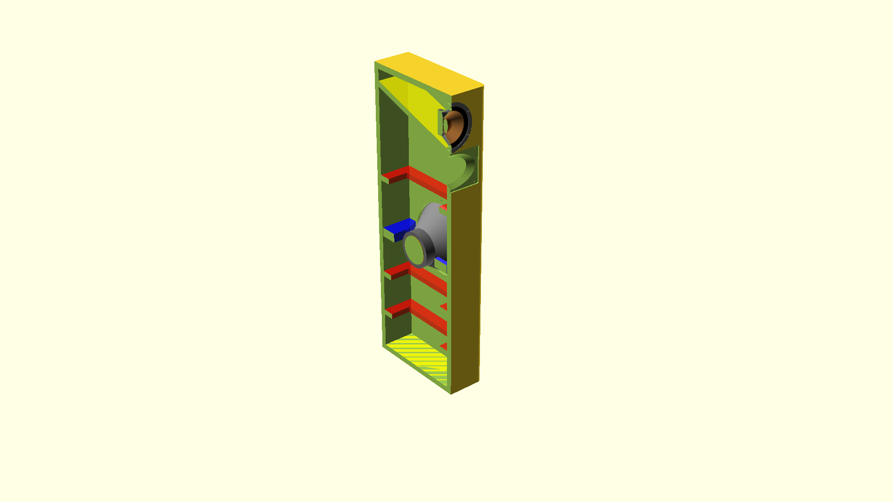
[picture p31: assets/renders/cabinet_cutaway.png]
Cutaway
|  |  |
| 3/4 exterior | Half-section cutaway |
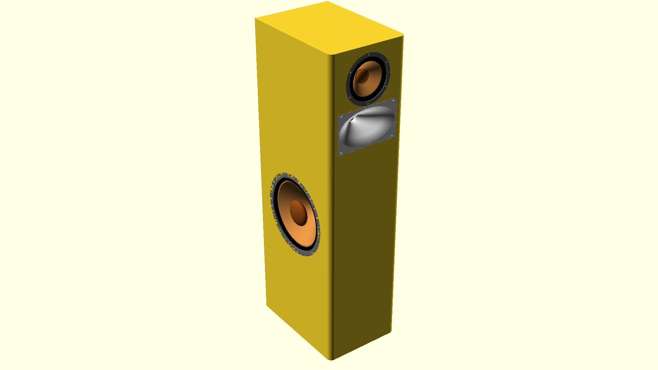
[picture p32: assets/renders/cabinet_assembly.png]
Assembly
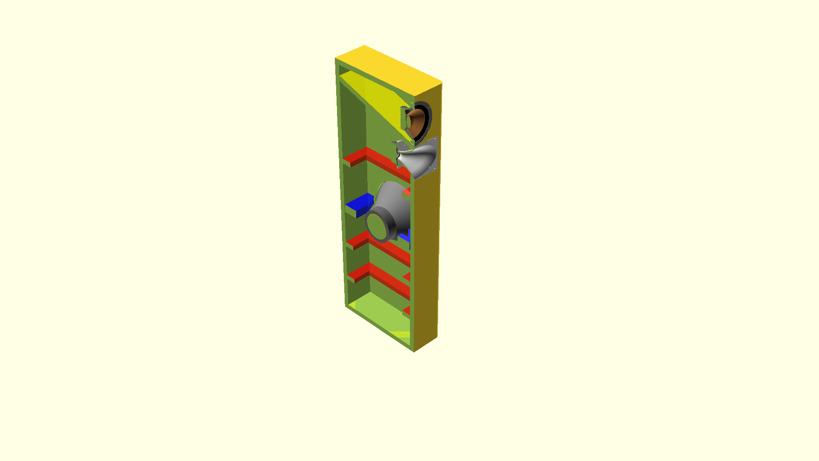
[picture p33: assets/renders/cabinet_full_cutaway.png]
Full
|  |  |
| With waveguide mounted | Full assembly cutaway |

**CAD:** `cad/cabinet.scad` | **STL:** `cad/exports/cabinet.stl`

Renders auto-generated by CI on every CAD change. See [cad/README.md](cad/README.md) for details.

### Cabinet Drawings & Cut List

Dimensioned 2D drawings auto-generated from `cabinet.scad` + driver SCAD files. Updated by CI on every push.

**[→ Open interactive drawing viewer](assets/drawings/index.html)** — all 12 drawings with navigation, per-drawing download, and combined PDF.

**[→ Download all drawings (PDF, 13 pages)](assets/drawings/mk3-cabinet-drawings.pdf)**

Overview drawings:

| Drawing | SVG | PDF | Description |
|---|---|---|---|
| Assembly dims | [SVG](assets/drawings/assembly_dims.svg) | [PDF](assets/drawings/assembly_dims.pdf) | Front + side elevation, driver heights, internal dims |
| Cut list | [SVG](assets/drawings/cut_list.svg) | [PDF](assets/drawings/cut_list.pdf) | All panels with dimensions, quantities, notes |
| Front baffle | [SVG](assets/drawings/front_baffle.svg) | [PDF](assets/drawings/front_baffle.pdf) | Midrange + waveguide cutouts, rebates, pilot holes |
| Side panel | [SVG](assets/drawings/side_panel.svg) | [PDF](assets/drawings/side_panel.pdf) | Woofer cutout, 8 pilot holes on BCD, shelf positions |

Per-panel cut drawings:

| Panel | SVG | PDF |
|---|---|---|
| Front baffle | [SVG](assets/drawings/panel_front_baffle.svg) | [PDF](assets/drawings/panel_front_baffle.pdf) |
| Back panel | [SVG](assets/drawings/panel_back.svg) | [PDF](assets/drawings/panel_back.pdf) |
| Side panel L | [SVG](assets/drawings/panel_side_left.svg) | [PDF](assets/drawings/panel_side_left.pdf) |
| Side panel R | [SVG](assets/drawings/panel_side_right.svg) | [PDF](assets/drawings/panel_side_right.pdf) |
| Top panel | [SVG](assets/drawings/panel_top.svg) | [PDF](assets/drawings/panel_top.pdf) |
| Bottom panel | [SVG](assets/drawings/panel_bottom.svg) | [PDF](assets/drawings/panel_bottom.pdf) |
| Divider plate | [SVG](assets/drawings/panel_divider.svg) | [PDF](assets/drawings/panel_divider.pdf) |
| Shelf brace ×3 | [SVG](assets/drawings/panel_shelf_brace.svg) | [PDF](assets/drawings/panel_shelf_brace.pdf) |

Alternative material cut plan:

| Drawing | SVG | PDF | Description |
|---|---|---|---|
| Pine board cut plan | [SVG](assets/drawings/pine_cutplan.svg) | [PDF](assets/drawings/pine_cutplan.pdf) | 5× 25×620×2420 mm massiv fyr (Jem & Fix) — ET PAR (venstre + højre højttaler) |

Generator: `scripts/generate_drawings.py` (parses SCAD source files, no hardcoded dimensions).

### Cabinet v2 (baffel_insert variant)

Alternative cabinet design with a 3D-printed baffel insert. Same enclosure,
bracing, and woofer placement, but the front baffle has a single pocket for
a precision-printed insert instead of individual driver cutouts in plywood.
The insert provides flush rebate for the midrange, pocket + elliptical hole
for the waveguide, and precise screw patterns.

| | | |
|:---:|:---:|:---:|
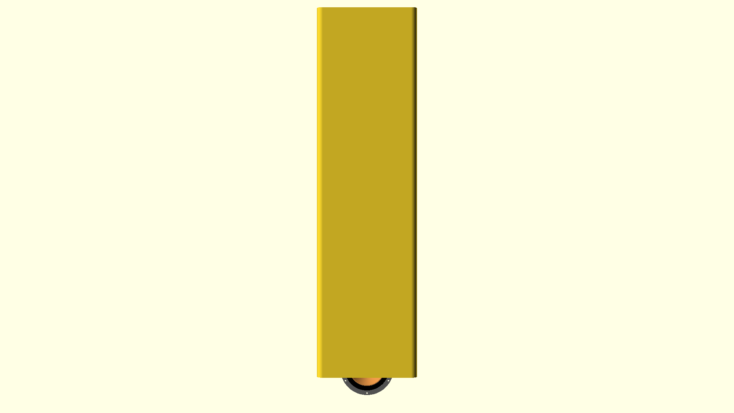
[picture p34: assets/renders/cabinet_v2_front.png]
Front
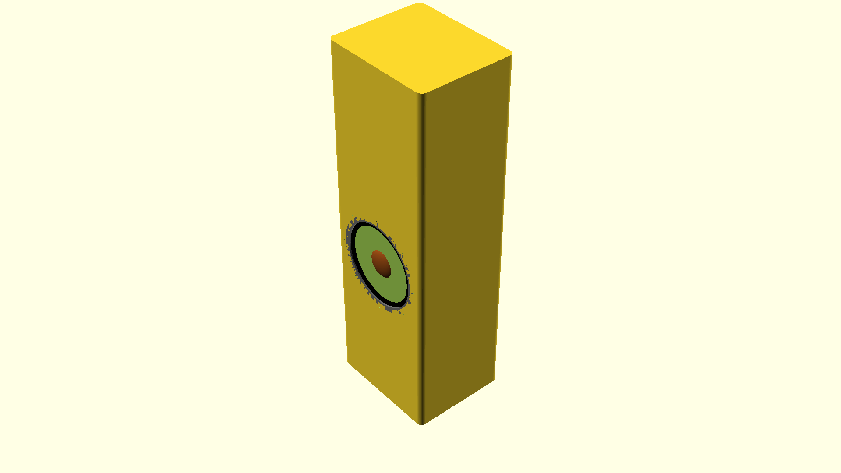
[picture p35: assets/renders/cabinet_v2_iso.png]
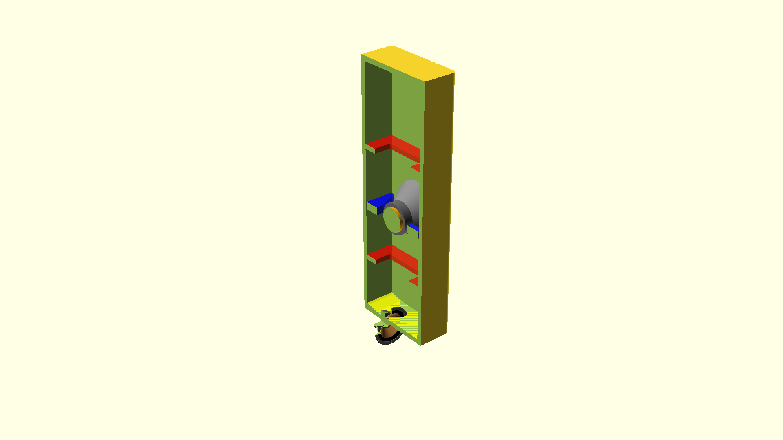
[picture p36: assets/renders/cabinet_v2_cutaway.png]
Cutaway
|  |  |  |
| Front (with insert + drivers) | Isometric | Half-section cutaway |

**CAD:** `cad/cabinet_v2.scad` | **STL:** `cad/exports/cabinet_v2.stl` | **Insert:** `cad/baffel_insert_1.scad`

#### Baffel insert (3D-print)

| | | |
|:---:|:---:|:---:|
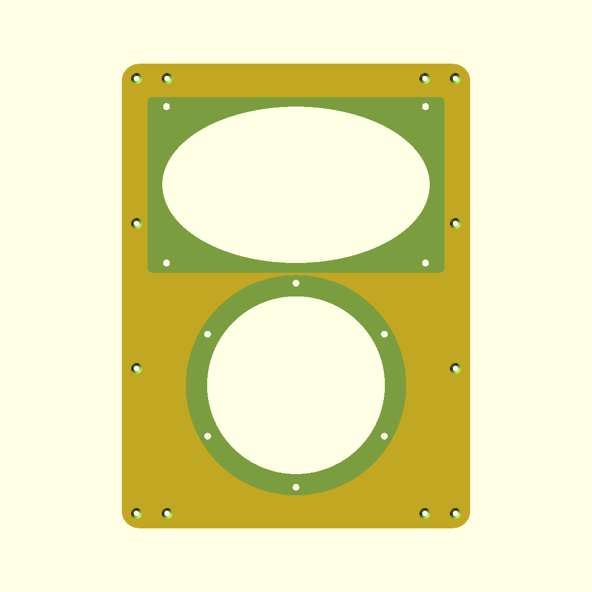
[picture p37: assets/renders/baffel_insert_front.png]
Front
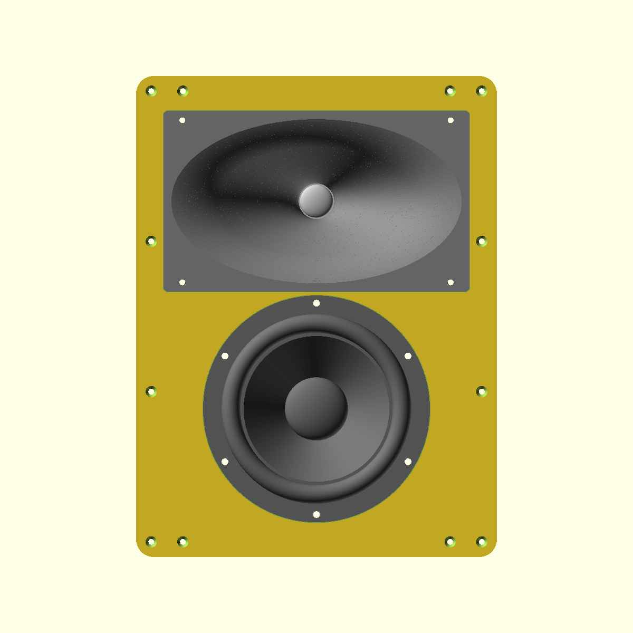
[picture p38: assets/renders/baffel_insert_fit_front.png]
Fit front
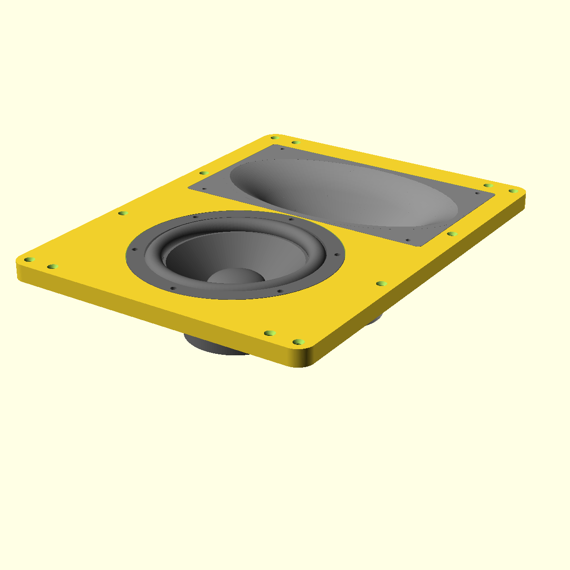
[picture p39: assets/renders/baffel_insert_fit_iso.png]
Fit iso
|  |  |  |
| Print-ready (front) | With all drivers fitted | Fitted isometric |
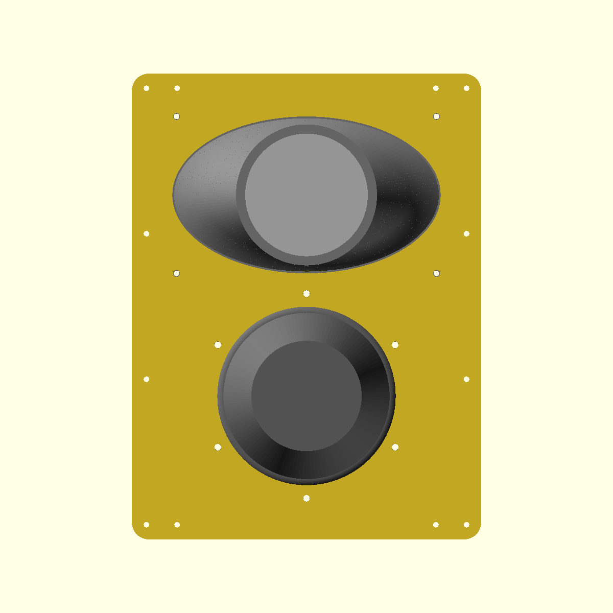
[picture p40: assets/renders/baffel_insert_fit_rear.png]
Fit rear
|  | Section | |
| Fitted rear view | Half-section | |

The insert is 285 x 420 x 15 mm with backside ribbing for stiffness. Print
flat (backside down). `vis="fit"` shows the insert with the 18W/4424G00
midrange and SB26STAC tweeter in place for visual verification.

Parametric OpenSCAD models for each driver, plus manufacturer/reference 3D geometry.

#### GRS 12SW-4HE (woofer)

| | | |
|:---:|:---:|:---:|
| Front | Iso | Section |
| Front | Isometric | Half-section |

**SCAD:** `cad/GRS-12SW-4HE.scad` | **3D:** — (datasheet only) | **Template:** `vis="skabelon"` for drill template

#### ScanSpeak 18W/4424G00 (midrange)

| | | |
|:---:|:---:|:---:|
| Front | Iso | Section |
| Front | Isometric | Half-section |

**SCAD:** `cad/midrange.scad` | **STEP:** [18W-4424G00.STEP](assets/cad/18W-4424G00.STEP) | **STL:** [reference](assets/cad/18W-4424G00_ref.stl)

#### SB26STAC-C000-4 (tweeter)

| | | |
|:---:|:---:|:---:|
| Front | Iso | Section |
| Front | Isometric | Half-section |

**SCAD:** `cad/SB26STAC-C000-4.scad` | **STEP:** [SB26STAC-C000-4.stp](assets/cad/SB26STAC-C000-4.stp) | **STL:** [reference](assets/cad/SB26STAC-C000-4_ref.stl)

See [assets/cad/README.md](assets/cad/README.md) for file provenance and notes.

---

## DSP

MiniDSP 4×10 HD with pre-built XML config.

| Driver path | Filters |
|---|---|
| Woofer (×2) | Subsonic HP ~18 Hz LR2, Linkwitz Transform (39.0→28 Hz, Q 0.76→0.707), LP 200 Hz BW4, gain 0 dB |
| Midrange | HP 200 Hz BW4, LP 1100 Hz LR4, gain -4.0 dB |
| Tweeter | HP 1100 Hz LR4, gain -9.0 dB |

**Pre-built config:** [dsp-configs/](dsp-configs/) — import `mk3-v9-200-1100-bw4-lr4.xml` via File → Import in MiniDSP plugin. See [dsp-configs/README.md](dsp-configs/README.md) for the full filter specification and biquad coefficients.

---

## Documentation

The full design bible lives in the `docs/` folder:

| Chapter | File |
|---|---|
| Master index | [00_design_bible.md](docs/00_design_bible.md) |
| 1. Project goals | [01_project_goals.md](docs/01_project_goals.md) |
| 2. Theory | [02_theory.md](docs/02_theory.md) |
| 3. Woofer selection | [03_woofer_selection.md](docs/03_woofer_selection.md) |
| 4. Midrange selection | [04_midrange_selection.md](docs/04_midrange_selection.md) |
| 5. Tweeter selection | [05_tweeter_selection.md](docs/05_tweeter_selection.md) |
| 6. Waveguide development | [06_waveguide_development.md](docs/06_waveguide_development.md) |
| 7. Cabinet development | [07_cabinet_development.md](docs/07_cabinet_development.md) |
| 8. Push-push bass | [08_push_push_bass.md](docs/08_push_push_bass.md) |
| 9. Volume calculations | [09_volume_calculations.md](docs/09_volume_calculations.md) |
| 10. Bracing | [10_bracing.md](docs/10_bracing.md) |
| 11. Crossovers | [11_crossovers.md](docs/11_crossovers.md) |
| 12. Directivity | [12_directivity.md](docs/12_directivity.md) |
| 13. Spinorama | [13_spinorama.md](docs/13_spinorama.md) |
| 14. DSP | [14_dsp.md](docs/14_dsp.md) |
| 15. Measurements | [15_measurements.md](docs/15_measurements.md) |
| 16. Build guide | [16_build_guide.md](docs/16_build_guide.md) |
| 17. Future versions | [17_future_versions.md](docs/17_future_versions.md) |
| Tweeter analysis | [SB26STAC-C000-4_analysis.md](docs/SB26STAC-C000-4_analysis.md) |
| Drawings guide | [DRAWINGS_GUIDE.md](docs/DRAWINGS_GUIDE.md) |

### Reference files

| File | Contents |
|---|---|
| [DESIGN_REQUIREMENTS.md](DESIGN_REQUIREMENTS.md) | Acoustic and mechanical targets |
| [DESIGN_DECISIONS.md](DESIGN_DECISIONS.md) | Rationale for all key design decisions |
| [PARTS.md](PARTS.md) | Driver and materials list with pricing |
| [PROJECT_TODO.md](PROJECT_TODO.md) | Task list and dependency graph |
| [PROTOTYPE_CHECKLIST.md](PROTOTYPE_CHECKLIST.md) | 3-step pre-build verification guide |
| [SIMULATIONS.md](SIMULATIONS.md) | Simulation assumptions and methodology |
| [MEASUREMENTS.md](MEASUREMENTS.md) | Post-build measurement plan |
| [BUILD_LOG.md](BUILD_LOG.md) | Physical build log |
| [ROADMAP.md](ROADMAP.md) | Version history and future plans |
| [CHANGELOG.md](CHANGELOG.md) | Design change log |
| [REFERENCES.md](REFERENCES.md) | Books, papers, tools |
| [CLAUDE.md](CLAUDE.md) | AI assistant context (design spec, edit rules) |

### Datasheets

| Driver | Datasheet | Extracted data |
|---|---|---|
| GRS 12SW-4HE (woofer) | [PDF](assets/datasheets/GRS-12SW-4HE.pdf) | [Full reference](assets/datasheets/GRS-12SW-4HE.md) — Fs 22 Hz, Qts 0.43, Vas 80.4 L, Xmax 12.5 mm (Klippel), Sd 504 cm², Bl 16.2 Tm, 250 W, 84.5 dB |
| GRS 8SW-4HE-8 (woofer, historical — superseded) | [PDF](assets/datasheets/GRS-8SW-4HE-8-spec-sheet.pdf) | [freq response](assets/datasheets/GRS-8SW-4HE-8_freq_response.csv), [impedance](assets/datasheets/GRS-8SW-4HE-8_impedance.csv), [T/S params](assets/datasheets/GRS-8SW-4HE-8_params.csv) |
| ScanSpeak 18W/4424G00 (mid) | [PDF](assets/datasheets/18W-4424G00.pdf) | [Full reference](assets/datasheets/18W-4424G00.md) — Fs 49 Hz, Qts 0.38, Vas 24.1 L, Sd 137 cm², 91 dB; parametric model `cad/midrange.scad` |
| ScanSpeak 15W/4434G00 (mid, historical — superseded in v9) | [PDF](assets/datasheets/15W-4434G00.pdf) | [freq response](assets/datasheets/15W-4434G00_freq_response.csv), [impedance](assets/datasheets/15W-4434G00_impedance.csv), [T/S params](assets/datasheets/15W-4434G00_params.csv) |
| SB Acoustics SB26STAC-C000-4 (tweeter) | [PDF](assets/datasheets/SB26STAC-C000-4.pdf) | [freq response](assets/datasheets/SB26STAC-C000-4_freq_response.csv), [T/S params](assets/datasheets/SB26STAC-C000-4_params.csv) |

See [assets/datasheets/README.md](assets/datasheets/README.md) for extraction details.

---

## Project Status

**Current gate:** Purchase SB26STAC-C000-4 → caliper verify dimensions → print waveguide → measure distortion at 1100 Hz → build prototype.

See [PROJECT_TODO.md](PROJECT_TODO.md) for the full task list and dependency graph. See [PROTOTYPE_CHECKLIST.md](PROTOTYPE_CHECKLIST.md) for the 3-step pre-build guide.

---

## License

MIT

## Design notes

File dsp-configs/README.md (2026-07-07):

# MiniDSP 4×10 HD Configurations for Mk3 Reference Loudspeaker

This directory holds MiniDSP 4×10 HD XML configuration files for active DSP
crossover / EQ on the Mk3 loudspeaker. Each XML file is a complete plugin
configuration that can be loaded via MiniDSP's plugin software (File → Import).

## Current Configs

| File | Crossover | Drivers | Status |
|---|---|---|---|
| `mk3-v9-200-1100-bw4-lr4.xml` | 200 Hz BW4 + 1100 Hz LR4 | 2×GRS 12SW-4HE → 18W/4424G00 → SB26STAC-C000-4 | ✅ **v9 design target** |
| `mk2-mk3-transition-150-1100-lr4.xml` | 150 Hz LR4 + 1100 Hz LR4 | 2×GRS 12SW-4HE → 15W/4434G00 → SB26STAC-C000-4 | 🗄️ Transition config (pre-v9) |
| *(add more as measurements refine)* | | | |

## Generator

`generate_minidsp_xml.py` is a reusable generator supporting:

- **3-way + push-push woofer** (mk3 v9 default)
- **2-way** configs (--two-way)
- Subsonic HP, Linkwitz Transform, variable sample rate
- Per-channel gain/delay
- Full MiniDSP 4×10 HD XML output (File → Import ready)

Usage:
```bash
# Mk3 v9 (default)
python generate_minidsp_xml.py > mk3-v9-custom.xml

# Custom 3-way
python generate_minidsp_xml.py \
  --woofer-lp 200 --mid-hp 200 --mid-lp 1100 \
  --tweeter-hp 1100 --tweeter-trim -9.0 \
  --woofer-trim 0.0 --mid-trim -4.0

# All options
python generate_minidsp_xml.py --help
```

Biquad coefficients can also be generated stand-alone with `generate_biquads.py`.

## v9 Sensitivity Balance

| Driver | Sensitivity | DSP Trim | Net SPL |
|---|---|---|---|
| 2×GRS 12SW-4HE (push-push) | ~95 dB | 0.0 dB | **95 dB** |
| ScanSpeak 18W/4424G00 | 91 dB | -4.0 dB | **87 dB** |
| SB26STAC-C000-4 (waveguide) | 91.5 dB | -9.0 dB | **82.5 dB** |

Gains are W0/M-4/T-9 (woofer at unity, mid and tweeter padded down). Net SPL
values are pre-measurement estimates; final trims set from in-cabinet measurement.
DSP correction is approximately ±1.3 dB.

## Input → Output Mapping

MiniDSP 4×10 HD has 2 input channels and 10 outputs. The config maps
Input L → Out 0-4 (left speaker) and Input R → Out 5-9 (right speaker).

### Left Speaker

| Input | Output | Driver | Filters |
|---|---|---|---|
| CH1 (Left) | Out 0 → Woofer Top | GRS 12SW-4HE (series, 8Ω pair) | Sub HP 18 Hz LR4, LT 39→28 Hz Q0.76→0.707, LP 200 Hz BW4 |
| CH1 (Left) | Out 1 → Woofer Bot | GRS 12SW-4HE (series, 8Ω pair) | Same as Out 0 |
| CH1 (Left) | Out 2 → Mid | ScanSpeak 18W/4424G00 | HP 200 Hz BW4, LP 1100 Hz LR4 |
| CH1 (Left) | Out 3 → Tweeter | SB26STAC-C000-4 (waveguide WG212) | HP 1100 Hz LR4, delay 120 µs |
| CH1 (Left) | Out 4 | Spare | — |

### Right Speaker

| Input | Output | Driver | Filters |
|---|---|---|---|
| CH2 (Right) | Out 5 → Woofer Top | GRS 12SW-4HE | Same as Out 0 |
| CH2 (Right) | Out 6 → Woofer Bot | GRS 12SW-4HE | Same as Out 1 |
| CH2 (Right) | Out 7 → Mid | ScanSpeak 18W/4424G00 | Same as Out 2 |
| CH2 (Right) | Out 8 → Tweeter | SB26STAC-C000-4 (waveguide WG212) | Same as Out 3 |
| CH2 (Right) | Out 9 | Spare | — |

## Wiring Notes

- Two GRS 12SW-4HE woofers per speaker, wired in **series** → 8 Ω load.
- Each woofer gets its own output channel with identical filters.
  This allows DSP-based polarity flip or individual excursion limiting later.
- Mid and tweeter are single drivers per channel (4 Ω each).
- Delay on tweeter: 120 µs (~0.12 ms) to align acoustic centers with the
  deeper woofer/mid cone plane. The WG212 waveguide recesses the tweeter
  dome behind the baffle surface, requiring this delay for time alignment.

## To Load on MiniDSP

1. Open MiniDSP 4×10 HD plugin
2. Connect to device
3. File → Import → choose XML
4. Upload to device
5. Verify with pink noise + REW measurement
6. Fine-tune delay and gain based on measured response

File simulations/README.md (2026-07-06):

# Simulations

Version-controlled, assumption-headed simulation scripts for the Mk3 Reference
Loudspeaker. This starts closing the "recreate simulations as version-controlled
scripts" task in [../SIMULATIONS.md](../SIMULATIONS.md).

**All outputs are simplified physics estimates, not measured data.** Every script
states its assumptions in a docstring. Final crossover/DSP decisions must come
from real measurements of the finished cabinet (see [../MEASUREMENTS.md](../MEASUREMENTS.md)).

## Current design scripts

These scripts document the current SB26STAC-C000-4 / 1100 Hz design and the
tweeter selection analysis:

| Script | What it computes | Output |
|---|---|---|
| `mk3_crossover_optimization.py` | Systematic crossover-frequency sweep for the SB26STAC scoring Fs margin, excursion headroom, directivity match, vertical lobing ripple and system-sum flatness. Confirms 1100 Hz as optimal. | `plots/mk3_crossover_optimization.png` |
| `system_response_realistic.py` | Realistic full-system on-axis response using actual digitized datasheet frequency-response curves, baffle step, waveguide loading and LR4 crossovers. Compares the current SB26STAC/1100 Hz design against the earlier horn-dome/1250 Hz baseline (historical). | `plots/mk2_vs_mk3_realistic_response.png` |
| `system_response_inroom.py` | Four-stage progression: anechoic (pre-DSP) → in-room (average living room 4.5×4×2.4m, room gain + HF absorption) → level-corrected (normalized @500 Hz) → post-DSP (EQ toward Harman in-room target, 1/3 octave PEQ simulation). Uses v9 drivers. | `plots/system_response_inroom.png`, `csv/system_response_inroom.csv` |
| `target_comparison.py` | Harman vs BBC-style in-room target comparison with optimized per-driver gains for each. Shows both target curves, pre-EQ in-room response, and post-DSP results. | `plots/target_comparison.png`, `csv/target_comparison.csv` |
| `inroom_gain_optimization.py` | Three-stage in-room gain optimization: all-zero gains → optimized (W0/M-4/T-9) → post-DSP. Documents driver sensitivity mismatch and why pads are needed. | `plots/inroom_gain_optimization.png`, `csv/inroom_gain_optimization.csv` |
| `mk2_vs_mk3_spinorna.py` | Spinorama estimate (on-axis, listening window, early reflections, sound power, DI, PIR) using real datasheet curves and 26 mm vs 25 mm dome directivity. | `plots/mk2_vs_mk3_spinorna.png`, `plots/mk2_vs_mk3_system_response.png` |
| `h2606_vs_sb26stac_comparison.py` | Tweeter selection analysis (Fs, Xmax, sensitivity, excursion-limited max SPL, Fs-margin at each candidate crossover) documenting why the SB26STAC was chosen. | `plots/h2606_vs_sb26stac_comparison.png` |

## Original exploration scripts

These scripts cover the bass alignment, baffle diffraction, and the original
crossover/waveguide directivity exploration. The crossover-frequency scripts
(`crossover_simulation.py`, `system_response.py`, `vertical_polar_map.py`) were
written against the earlier candidate parameters and are kept for reference; the
current design values are captured by the scripts above.

| Script | What it computes | Output |
|---|---|---|
| `bass_alignment_maxspl.py` | Sealed alignment table (2 × GRS 12SW-4HE) + excursion-limited max-SPL ceiling + sealed response with a Linkwitz-Transform target (39→28 Hz, Q 0.76→0.707). Includes comparison against the previous 2 × GRS 8SW-4HE-8. | `plots/bass_alignment_maxspl.png` |
| `bass_volume_compare.py` | Sealed alignment (Qtc / Fc / F3) and group delay for 69–85 L net, highlighting the 75 L target — shows the alignment is robust to box-volume tolerance. | `plots/bass_volume_compare.png` |
| `vertical_lobing.py` | First vertical interference-null angle vs frequency for c-c and crossover options. | `plots/vertical_lobing.png` |
| `directivity_estimate.py` | Estimated directivity index (DI) of the 15W and the waveguide tweeter across the crossover — quantifies the DI step vs crossover frequency. | `plots/directivity_estimate.png` |
| `waveguide_profile.py` | Waveguide mouth-to-baffle termination cross-section — shows the sharp-lip diffraction problem and the flush / blended fixes. | `plots/waveguide_termination.png` |
| `crossover_simulation.py` | LR4 filters at 150 Hz + 1250 Hz: per-section amplitude and phase, coherent sum, zoomed panels around each crossover region. (Earlier candidate parameters.) | `plots/crossover_simulation.png`, `csv/crossover_simulation.csv` |
| `system_response.py` | Full-bandwidth on-axis estimate 20 Hz–20 kHz: sealed woofer + LR4 LP@150, piston mid + BP@150/1250, tweeter roll-in + LR4 HP@1250 (placeholder tweeter model — replace with real SB26STAC-in-waveguide FR). | `plots/system_response.png`, `csv/system_response.csv` |
| `polar_response.py` | 2D polar map (freq × angle), spinorama curves (on-axis, listening window, early reflections, sound power, DI, PIR), and horizontal polar cuts at 7 key frequencies. | `plots/polar_response.png`, `csv/spinorama.csv`, `csv/polar_horizontal.csv` |
| `vertical_polar_map.py` | Vertical 2D heat-map vs frequency + comparison of four crossover options + null-depth bar chart. (Earlier candidate parameters.) | `plots/vertical_polar_map.png`, `csv/vertical_polar_map.csv` |
| `design_versions_comparison.py` | Tabulates the design parameters for reference. | `design_versions.md`, `csv/design_versions.csv` |
| `baffle_step.py` | Baffle-step diffraction model for the cabinet: SPL correction curve, low-frequency level loss, and the full on-axis response before/after step correction. | `plots/baffle_step.png`, `csv/baffle_step.csv` |
| `cabinet_params.py` | Parses `cad/cabinet.scad` for cabinet dimensions (W, D, H, wall, round_r, driver positions). Provides `baffle_step_db_side(f)` and `baffle_step_db_front(f)` with correct effective radii: side woofers use D/2 = 190 mm (f_bs = 287 Hz), front mid/tweeter use W/2 = 160 mm (f_bs = 341 Hz). All v9 simulation scripts import from here. CI runs `cabinet_params.py` validation on every push. | — (module, no plot) |

The GRS alignment script reproduces the repo's stated **Qtc ≈ 0.76 / Fc ≈ 39 Hz
in ~75 L** (12SW), transformed to 28 Hz / 0.707 via Linkwitz Transform. The lobing
script confirms that even c-c 160 mm crossed at 1600 Hz keeps the first vertical
null near 42° — far outside the listening window.

## Running

```
pip install "numpy>=1.26" "matplotlib>=3.8"
python3 simulations/bass_alignment_maxspl.py
python3 simulations/bass_volume_compare.py
python3 simulations/vertical_lobing.py
python3 simulations/directivity_estimate.py
python3 simulations/waveguide_profile.py
python3 simulations/crossover_simulation.py
python3 simulations/system_response.py
python3 simulations/polar_response.py
python3 simulations/vertical_polar_map.py
python3 simulations/design_versions_comparison.py
python3 simulations/baffle_step.py
python3 simulations/cabinet_params.py  # validate cabinet.scad parse
python3 simulations/mk3_crossover_optimization.py
python3 simulations/mk2_vs_mk3_realistic_response.py
python3 simulations/mk2_vs_mk3_spinorna.py
python3 simulations/h2606_vs_sb26stac_comparison.py
python3 simulations/system_response_inroom.py
python3 simulations/target_comparison.py
python3 simulations/inroom_gain_optimization.py
python3 simulations/system_response_anechoic.py
python3 simulations/crossover_woofer_mid.py
```

The directivity script implements the Bessel `J1` via a polynomial
approximation, so no SciPy is required.

Plots are written to `simulations/plots/`.

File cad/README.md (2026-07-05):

# CAD

Parametric CAD models for the Mk3 Reference Loudspeaker.

## `waveguide.scad`

A fully parametric **OpenSCAD** model of the tweeter waveguide for the
SB Acoustics **SB26STAC-C000-4** — an oblate-spheroid (OS) constant-directivity
bore with a tangent rolled mouth. The SB26STAC is a conventional 26 mm soft
dome tweeter with **no built-in horn**, so the OS bore starts directly at the
dome (throat Ø28 mm = dome + ~1 mm surround per side) rather than at a horn
exit. The waveguide mounts **behind the cabinet baffle** via a 5 mm-thick
rectangular flange; the cabinet has an elliptical hole through the baffle
exposing the waveguide mouth from the front. Visually flush with the baffle
from the outside (the waveguide itself sits inside the cabinet, terminating at
the baffle back face).

- Mouth ≈ **~289 × 172 mm**, acoustic depth **90 mm** (`D_os + Lr` = 65 + 25),
  tube physical extent **z = -5 .. 85 mm** (overlaps the back plate by 5 mm at
  the throat end, ends flush with the baffle back face at z=85). Total part
  depth **98 mm** including back plate.
- Asymmetric coverage ≈ **100° horizontal / 64° vertical** (θh=50°, θv=32°).
- Horizontal pattern control down to ≈ **1620 Hz**.
- Crossover target: **1100 Hz LR4** (the SB26STAC's Fs=750 Hz gives a 350 Hz
  margin — no distortion-test gate required).

### Critical tunables (verify before printing)

- `throat_d` (28 mm from SB26STAC datasheet + surround estimate) **must be
  caliper-verified on the physical unit before final print** — this sets whether
  you get a throat resonance. Print throat test pieces against the physical
  tweeter first. SB Acoustics does not supply a STEP file for this tweeter.
- `Lr` (default **25 mm**) — depth of the mouth roundover. Larger = gentler
  baffle blend + less mouth diffraction, at the cost of total waveguide depth.
  With `Lr = 25` the tube is 90 mm long.
- `protrusion` (default **0 mm**) — cylindrical extension past the flange
  front face. With `protrusion = 0` the waveguide tube ends **flush with the
  cabinet baffle back face** (z = 85) — the baffle has a through-cutout
  exposing the waveguide mouth from the outside. Set higher than 0 only if
  you want the tube to physically extend *through* the baffle past the
  outside face (then keep in sync with `cabinet.scad`'s `wall = 22;`).
- `flange_thick` (default **5 mm**) — thickness of the screw-mounting flange
  sitting against the cabinet baffle back. 5 mm is plenty for wood-screw
  mounting into the baffle; the baffle cutout in `cabinet.scad` derives its
  recess depth from this value automatically (`wg_flange_t_fn()`).
- `corner_r` (default **4 mm**) — flange corner radius. Kept tight so the
  flange fits cleanly in the cabinet cutout with no rounded-edge gap; bump
  up if you prefer a softer cabinet cutout.
- The mouth roundover must blend smoothly into the cabinet's baffle; a step
  there re-introduces diffraction. See
  [`../simulations/waveguide_profile.py`](../simulations/waveguide_profile.py)
  and `plots/waveguide_termination.png`.

### Building

Open in OpenSCAD, render with F6, export STL. `$fn` is high for export — drop to
64 while iterating. The model echoes the computed mouth size and depth on render.

### CI renders and STL downloads

The [`build-and-deploy`](../.github/workflows/build-and-deploy.yml) workflow runs automatically
on every push that changes a `.scad` file. It:

1. Runs all simulations
2. Renders both models to STL (waveguide + cabinet)
3. Renders preview PNGs and commits them to [`../assets/renders/`](../assets/renders/)
4. Builds and deploys the GitHub Pages site

| Preview | Description |
|---|---|
| **Waveguide (6 views)** ||
| mouth | Mouth (front view) |
| rear | Rear / back plate + mounting |
| side | Side profile (OS bore curve) |
| top | Top (throat view) |
| iso | Isometric 3/4 view |
| cutaway | Half-section cutaway |
| **Cabinet (10 views)** ||
| front | Front (baffle with driver placeholders) |
| rear | Rear panel |
| left | Left side (woofer visible) |
| right | Right side (woofer visible) |
| top | Top view |
| bottom | Bottom view |
| exterior | 3/4 exterior perspective |
| cutaway | Half-section cutaway (internals) |
| assembly | Assembly (with waveguide) |
| full | Full assembly cutaway (all drivers) |

These are **design-direction geometry, not validated by measurement.** Mouth
size, throat and coverage must be confirmed against SB26STAC-in-waveguide
measurements.

## `midrange.scad`

Parametric OpenSCAD model of the **ScanSpeak 18W/4424G00** midrange. Built from
the official datasheet drawing and the manufacturer STEP file
([`assets/cad/18W-4424G00.STEP`](../assets/cad/18W-4424G00.STEP)).

Exports dimension functions used by `cabinet.scad` via `use <midrange.scad>`:
flange OD, cutout diameter, depth, bolt circle, magnet diameter, and T/S params.

## `SB26STAC-C000-4.scad`

Parametric OpenSCAD model of the **SB Acoustics SB26STAC-C000-4** tweeter.
Dimensions measured from a STEP file of a similar SB Acoustics tweeter
([`assets/cad/SB26STAC-C000-4.stp`](../assets/cad/SB26STAC-C000-4.stp), GrabCAD
user model), verified against the SB26STAC datasheet.

Includes cutout and half-section views (`vis` parameter).

## `GRS-12SW-4HE.scad`

Parametric OpenSCAD model of the **GRS 12SW-4HE** 12" woofer. Built from the
datasheet drawing only (no manufacturer STEP available). Includes driver,
baffle cutout, drill template, and half-section views (`vis` parameter).

Some dimensions (cone, surround, dust cap, magnet) are estimates pending
caliper verification on the physical unit.

## `baffel_insert_1.scad`

Modular 3D-printed baffle insert for the front baffle. Provides flush rebate
(planfræset) for the 18W/4424G00 midrange, flush pocket + elliptical body hole
for the WG212 waveguide, and precise screw patterns for both drivers. Includes
backside ribbing for stiffness and edge screws for cabinet mounting.

Dimensions: 285 x 380 x 15 mm. Print flat (backside down).

`vis` parameter: `baffel` (print-ready), `fit` (with real drivers), `snit`
(half-section).

Uses `waveguide.scad` for all waveguide dimensions. Place both files in the
same directory.

## `cabinet_v2.scad`

Alternative cabinet design using the baffel insert. Same enclosure dimensions,
bracing, divider plate, and woofer placement as `cabinet.scad`, but the front
baffle has a single pocket for the 3D-printed insert instead of individual
driver cutouts in plywood.

This is an **alternative**, not a replacement. Builders who want 3D-printed
baffle precision without CNC routing complex cutout patterns in plywood should
use v2. Builders who prefer all-plywood construction should use the original
`cabinet.scad`.

Uses the same driver models (`GRS-12SW-4HE.scad`, `midrange.scad`,
`SB26STAC-C000-4.scad`) and `baffel_insert_1.scad`.

## `cabinet.scad`

A fully parametric **OpenSCAD** model of the enclosure — the cabinet
geometry for the repo.

- External **300 × 370 × 1080 mm**, 22 mm walls, **R50** front vertical
  roundovers (rear edges square).
- **Side-mounted push-push** woofer cut-outs, opposed at the same height
  (~520 mm), with the rigid coupling block between the magnets (see
  [Chapter 8](../docs/08_push_push_bass.md)).
- Front baffle cut-outs for the **waveguide** (elliptical mouth + rounded flange
  recess, matched to `waveguide.scad`) and the **18W/4424G00** midrange at
  the top of the baffle.
- `show_internals = true` renders a cut-away with the sealed mid chamber, a
  window brace at the woofer line and the bass/mid shelf brace.
- `show_waveguide = true` drops the waveguide model into the baffle (it `use`s
  `waveguide.scad`, so keep both files together). The waveguide is seated
  with its mouth poking `wg_through` (default 0.3 mm) **through** the baffle. Its
  seating depth is read from the waveguide via `wg_front_z()`, so it can't drift
  out of sync.

### Assembly and the coincident-face rule

OpenSCAD cannot show a hole or a join where two surfaces sit at exactly the same
plane — the boolean becomes non-manifold and renders as a flickering "smear"
instead of a clean opening. So every cutter here overshoots the panel it pierces
by `eps` (0.1 mm), and when the waveguide is seated its flush mouth is pushed
`wg_through` mm proud of the baffle so the two solids genuinely overlap. Keep
`wg_through > 0` (≥ 0.01 mm); set it to ~0.3 mm for a reliable preview. The
overlap is cosmetic for visualisation — it is not a real interference fit.

### Critical tunables (verify before cutting)

- `woofer_z`, `tw_z`, `mid_z` (driver heights) and `cc` set the baffle layout;
  confirm against the real flanges and the bracing layout
  ([Chapter 10](../docs/10_bracing.md)).
- The mid-chamber box here is **representational** — its net volume must be
  confirmed at **~5.7 L** from the solid model
  ([Chapter 9](../docs/09_volume_calculations.md)) before it is trusted.
- Cut-out diameters (woofer 185, mid 124 mm) are estimates pending datasheet
  templates.

This is a **dimension-check / visualisation model, not a cut list.**

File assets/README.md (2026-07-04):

# Assets

Datasheets and CAD render preview images for the Mk3 Reference Loudspeaker.

The numbers in the datasheets are the authoritative driver data used for the
simulation and CAD work. The CAD renders are auto-generated previews from the
OpenSCAD models — see [`cad/README.md`](../cad/README.md).

## Subfolders

| Folder | Contents |
|---|---|
| [`datasheets/`](datasheets/) | Official manufacturer datasheets (PDF) + extracted T/S parameters and frequency-response / impedance curves (CSV) for each driver. See [`datasheets/README.md`](datasheets/README.md). |
| [`renders/`](renders/) | Auto-generated preview images from the OpenSCAD CAD models (waveguide + cabinet views). Updated automatically by the [`cad-render`](../.github/workflows/cad-render.yml) workflow. See [`renders/README.md`](renders/README.md). |

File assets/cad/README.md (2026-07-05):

# CAD Reference Files

3D geometry for the three mk3 drivers. Used as dimensional ground-truth for the
parametric OpenSCAD models in `cad/`.

## Files

| File | Driver | Type | Source |
|---|---|---|---|
| `18W-4424G00.STEP` | ScanSpeak 18W/4424G00 (midrange) | Manufacturer STEP | ScanSpeak |
| `18W-4424G00_ref.stl` | ScanSpeak 18W/4424G00 (midrange) | Reference STL | Derived from STEP |
| `SB26STAC-C000-4.stp` | SB Acoustics SB26STAC-C000-4 (tweeter) | STEP | GrabCAD user model (similar unit) |
| `SB26STAC-C000-4_ref.stl` | SB Acoustics SB26STAC-C000-4 (tweeter) | Reference STL | Derived from STEP |

## Notes

- The 18W/4424G00 STEP is the official ScanSpeak geometry.
- The SB26STAC STEP is from a GrabCAD user who modeled a similar SB Acoustics
  tweeter. Dimensions were verified against the SB26STAC-C000-4 datasheet and
  adjusted in the parametric SCAD model (`cad/SB26STAC-C000-4.scad`).
- The `_ref.stl` files are tessellated references derived from the STEP files,
  useful for quick visual checks without a STEP-capable CAD viewer.
- The GRS 12SW-4HE woofer has no manufacturer STEP file. Its parametric model
  (`cad/GRS-12SW-4HE.scad`) is built from the datasheet drawing only.

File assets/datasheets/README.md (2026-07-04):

# Datasheets

Official manufacturer datasheets and 3D CAD files for the drivers used in the Mk3 Reference Loudspeaker.

All frequency response and impedance curves have been extracted from the PDFs into machine-readable CSV files. See `DATASHEET_EXTRACTION_PLAN.md` in the repo root for the extraction methodology.

---

## Driver summary

| Driver | Role | PDF | .md | Freq CSV | Imp CSV | Params CSV | Method |
|---|---|---|---|---|---|---|---|
| SB Acoustics SB26STAC-C000-4 | Tweeter | YES | [SB26STAC-C000-4.md](SB26STAC-C000-4.md) | YES | NO | YES | Raster |
| ScanSpeak 15W/4434G00 | Midrange | YES | [15W-4434G00.md](15W-4434G00.md) | YES | YES | YES | Raster |
| GRS 12SW-4HE | Woofer (push-push, v8) | YES | — | — | — | — | — |
| GRS 8SW-4HE-8 | Woofer (historical, v3–v7) | YES | [GRS-8SW-4HE-8.md](GRS-8SW-4HE-8.md) | YES | YES | YES | Vector |

---

## SB Acoustics SB26STAC-C000-4 — Tweeter

| File | What it is |
|---|---|
| [SB26STAC-C000-4.pdf](SB26STAC-C000-4.pdf) | Official SB Acoustics datasheet (731 KB) |
| [SB26STAC-C000-4.md](SB26STAC-C000-4.md) | Full datasheet reference with extracted curves |
| [SB26STAC-C000-4_freq_response.csv](SB26STAC-C000-4_freq_response.csv) | On-axis + 30° + 60° off-axis SPL (1/12 octave, 100-40k Hz) |
| [SB26STAC-C000-4_params.csv](SB26STAC-C000-4_params.csv) | All T-S + mechanical parameters |
| [SB26STAC-C000-4_extraction_verify.png](SB26STAC-C000-4_extraction_verify.png) | Verification plot |

**Key dimensions:** Faceplate ~ø100, BCD ø88.5, no horn throat. Fs=750 Hz, sensitivity 91.5 dB, Xmax 0.6 mm.

**No STEP file from SB Acoustics** — all dimensions must be caliper-verified on a physical unit. Impedance can be modeled from T-S parameters (no impedance plot in datasheet).

---

## ScanSpeak 15W/4434G00 — Midrange

| File | What it is |
|---|---|
| [15W-4434G00.pdf](15W-4434G00.pdf) | Official ScanSpeak datasheet (319 KB) |
| [15W-4434G00.md](15W-4434G00.md) | Full datasheet reference with extracted curves |
| [15W-4434G00_freq_response.csv](15W-4434G00_freq_response.csv) | On-axis + 2 off-axis SPL (1/12 octave, 100-10k Hz) |
| [15W-4434G00_impedance.csv](15W-4434G00_impedance.csv) | Impedance (1/12 octave, 100-10k Hz) |
| [15W-4434G00_params.csv](15W-4434G00_params.csv) | All T-S + mechanical parameters |
| [15W-4434G00_extraction_verify.png](15W-4434G00_extraction_verify.png) | Verification plot |

**Key dimensions:** Faceplate ø104, BCD ø95, rear cutout ø72. Fs=43 Hz, sensitivity 89.5 dB. No STEP file (Discovery series).

---

## GRS 12SW-4HE — Woofer (Push-Push, v8)

| File | What it is |
|---|---|
| [GRS-12SW-4HE.pdf](GRS-12SW-4HE.pdf) | Official GRS spec sheet |

**Key parameters:** Fs=22 Hz, Qts=0.43, Vas=80.4 L, Sd=504 cm², Xmax=12.5 mm (Klippel verified), Bl=16.2 Tm, sensitivity 84.5 dB, 250 W, 4 Ω. Baffle cutout 284 mm. No STEP file from GRS.

Frequency response / impedance / T/S params CSV extraction pending (spec sheet uses embedded custom fonts that block text extraction — see `DATASHEET_EXTRACTION_PLAN.md`).

---

## GRS 8SW-4HE-8 — Woofer (Historical, v3–v7, superseded by 12SW)

| File | What it is |
|---|---|
| [GRS-8SW-4HE-8-spec-sheet.pdf](GRS-8SW-4HE-8-spec-sheet.pdf) | Official GRS spec sheet (721 KB) |
| [GRS-8SW-4HE-8.md](GRS-8SW-4HE-8.md) | Full datasheet reference with extracted curves |
| [GRS-8SW-4HE-8_freq_response.csv](GRS-8SW-4HE-8_freq_response.csv) | On-axis SPL (1/12 octave, 20-10k Hz) |
| [GRS-8SW-4HE-8_impedance.csv](GRS-8SW-4HE-8_impedance.csv) | Impedance + phase (1/12 octave, 20-20k Hz) |
| [GRS-8SW-4HE-8_params.csv](GRS-8SW-4HE-8_params.csv) | All T-S parameters |
| [GRS-8SW-4HE-8_extraction_verify.png](GRS-8SW-4HE-8_extraction_verify.png) | Verification plot |

**Key parameters:** Fs=48 Hz, Qts=0.89, Vas=22 L, Xmax=6 mm, sensitivity 89 dB. Baffle cutout 185 mm. No STEP file from GRS. **Superseded by GRS 12SW-4HE in v8** — retained for historical comparison.

---

## CSV format

All frequency-domain CSVs use 1/12 octave log-spaced frequency grid (20 Hz to 20 kHz, or as available from datasheet). See `DATASHEET_EXTRACTION_PLAN.md` for full format specification.

Extraction script: `scripts/extract_datasheet.py`

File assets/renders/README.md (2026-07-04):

# CAD Renders

Auto-generated preview images from the OpenSCAD models.
Updated automatically by the [`cad-render`](../../.github/workflows/cad-render.yml)
workflow on every push that changes a `.scad` file.

| File | Description |
|---|---|
| `waveguide_mouth.png` | Waveguide — 3/4 front view (elliptical mouth) |
| `waveguide_rear.png` | Waveguide — rear view (back plate + tweeter screw holes) |
| `waveguide_side.png` | Waveguide — side profile (oblate-spheroid bore curve) |
| `cabinet_exterior.png` | Cabinet — exterior 3/4 front |
| `cabinet_cutaway.png` | Cabinet — cutaway showing mid chamber + bracing |
| `cabinet_assembly.png` | Assembly view — waveguide seated in baffle |

For downloadable STL files, see the [latest GitHub Release](../../releases/latest).

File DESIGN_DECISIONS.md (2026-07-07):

# Design Decisions

This file documents the important design decisions and the reasoning behind them.

---

# DD-001 - Use active DSP

## Decision

The loudspeaker will be an active DSP-controlled 3-way system.

## Reasoning

Active DSP allows:

- Accurate crossover slopes
- Driver delay correction
- Low-frequency EQ
- Baffle/waveguide correction
- Multiple target curves
- Easier iteration after measurements

## Consequence

The design depends on DSP and individual amplifier channels. A passive crossover is not currently part of the design goal.

---

# DD-002 - Use sealed bass alignment

## Decision

The bass system will be sealed.

## Reasoning

A sealed alignment offers:

- No port noise
- Easier integration with room gain
- Predictable roll-off
- Lower group delay than heavily tuned reflex systems
- Easy DSP extension

## Consequence

The system requires more amplifier power and excursion than a reflex design for the same SPL at very low frequencies.

---

# DD-003 - Use side-mounted push-push woofers

## Decision

Use two side-mounted woofers in a push-push configuration.

## Reasoning

Push-push placement reduces cabinet reaction forces and vibration. Side mounting also keeps the front baffle clear for the midrange and waveguide.

## Consequence

Woofer placement, wiring and mechanical coupling must be carefully planned.

---

# DD-004 - Select GRS 8SW-4HE-8 woofers (superseded by DD-015)

## Decision

Use 2 x GRS 8SW-4HE-8 per loudspeaker.

**Superseded in v8 by DD-015** (GRS 12SW-4HE). Retained for historical reference.

## Reasoning

The GRS woofer has:

- Low Fs
- Useful excursion
- Good fit for approx. 64-70 L sealed volume when used as a pair
- Attractive cost/performance ratio

## Consequence

Two 4-ohm woofers should normally be wired in series for an 8-ohm load unless the amplifier is explicitly stable into 2 ohms.

---

# DD-005 - Select ScanSpeak 15W/4434G00 midrange

## Decision

Use ScanSpeak 15W/4434G00 as the midrange driver.

## Reasoning

The 15W size offers a useful balance between:

- Low enough frequency range to meet the woofers around 150 Hz
- Small enough radiating diameter to match a waveguide around 1.1-1.6 kHz
- Good expected distortion performance

## Consequence

The vertical c-c spacing to the tweeter/waveguide remains a critical design constraint.

---

# DD-007 - Select 300 mm cabinet width

## Decision

Use a 300 mm wide front baffle.

## Reasoning

The 300 mm width is the best current compromise between:

- Directivity
- Diffraction
- Practical waveguide integration
- Visual proportions
- Cabinet volume

280 mm was attractive but more mechanically constrained. Wider cabinets offered only small simulated improvements and increased size.

---

# DD-008 - Use R50 vertical front roundovers

## Decision

Use approx. R50 mm vertical front edge roundovers.

## Reasoning

The simulations suggested that larger roundovers reduce diffraction ripple and smooth the off-axis response.

## Consequence

The cabinet front construction must support a large radius, possibly through laminated/machined corner pieces or thick front edge stock.

---

# DD-009 - Retain ~212 mm waveguide mouth rather than larger WG230

## Decision

Keep the current direction around a ~212 mm waveguide mouth.

## Reasoning

The simplified directivity comparison suggested that larger waveguides did not provide enough benefit compared with the gains from lower crossover frequency and shorter c-c spacing.

## Consequence

Waveguide refinement should focus on profile, mouth termination, throat geometry and physical integration rather than simply increasing mouth size.

---

# DD-011 - Target 140 mm mid/tweeter c-c spacing

## Decision

Target 140 mm center-to-center spacing between waveguide/tweeter and midrange.

## Reasoning

Shorter c-c spacing reduces vertical lobing around the mid/tweeter crossover.

## Consequence

The front layout becomes mechanically tight. The waveguide flange and midrange recess must be designed together.

## Caveat (review)

The geometric minimum c-c is ~145-160 mm: the 15W frame is ~Ø149 (half ~74.5 mm)
and a waveguide flange is ~140-150 mm tall (half ~70-75 mm), so 140 mm is only
achievable with a deliberately compact / bottom-trimmed ("D-shaped") flange. The
lobing analysis (`simulations/vertical_lobing.py`) shows ~155-160 mm crossed near
the waveguide control limit is still clean vertically, so treat **~150-160 mm** as
the realistic target and set the final value from the actual waveguide flange + mid
recess in CAD rather than over-committing to 140 mm.

---

# DD-013 - Select SB Acoustics SB26STAC-C000-4 tweeter

## Decision

Use SB Acoustics SB26STAC-C000-4 as the tweeter.

## Reasoning

The SB26STAC-C000-4 conventional dome tweeter is selected for its acoustic
advantages:

- **Fs 750 Hz gives 350 Hz margin at the 1100 Hz crossover** — a comfortable
  margin that requires no distortion-test gate before committing to the
  crossover frequency.
- **0.6 mm Xmax gives +8.1 dB excursion headroom** at 1100 Hz, substantially more
  maximum SPL capability near the crossover.
- **91.5 dB sensitivity is a better match to the 15W/4434G00's 89.7 dB** — only
  -1.8 dB of DSP pad is needed. This reduces wasted amplifier power and the
  thermal/level mismatch.
- **No horn loading** — the SB26STAC is a conventional dome used in a custom
  waveguide rather than a horn-loaded tweeter. The waveguide provides directivity
  control without relying on the driver's built-in horn.

The selection analysis comparing the SB26STAC against the earlier horn-dome
candidate is documented in `docs/SB26STAC-C000-4_analysis.md`.

## Consequence

A waveguide model (`cad/waveguide.scad`) is required with a throat sized for the
SB26STAC dome and surround (28 mm) and no horn loading. The crossover is set at
1100 Hz (see DD-014).

---

# DD-014 - Target 1100 Hz LR4 mid/tweeter crossover

## Decision

Use 1100 Hz LR4 acoustic crossover as the mid/tweeter target.

## Reasoning

The SB26STAC-C000-4's Fs of 750 Hz gives a comfortable 350 Hz margin at 1100 Hz.
The crossover optimization sweep (`simulations/mk3_crossover_optimization.py`)
confirms 1100 Hz as optimal, scoring 8.1 across Fs margin, excursion headroom,
directivity match, vertical lobing, and system sum flatness. The 1100 Hz point
sits below the broadside null (1147 Hz for 150 mm c-c) so the null is outside the
active crossover band, and the LR4 rolloff suppresses it almost entirely (under
0.7 dB ripple at ±15°).

Because the Fs margin is comfortable, no distortion-test gate is required before
committing to 1100 Hz.

## Consequence

The midrange low-pass and tweeter high-pass are both 1100 Hz LR4.

---

# DD-015 - Upgrade woofer to GRS 12SW-4HE

## Decision

Replace the GRS 8SW-4HE-8 (8") with the **GRS 12SW-4HE (12" high excursion)** as
the push-push woofer, 2 per enclosure. Sealed alignment retained; bass volume
increased to ~75 L under the divider plate.

## Reasoning

The 12SW-4HE offers a substantial low-frequency performance improvement over the
8SW while keeping the push-push, sealed, DSP-controlled architecture:

- **Fs 22 Hz** (vs 48 Hz) — much deeper native bass extension
- **Xmax 12.5 mm Klippel-verified** (vs 4.5 mm) — 2.8× more linear excursion
- **Sd 504 cm²** (vs 220 cm²) — 2.3× more radiating area
- **Displacement 12.6 cm³** per pair (vs 2.0 cm³) — 6.3× more, giving **+16 dB
  max SPL @ 30 Hz** over the previous design
- **Bl 16.2 Tm** (vs 10.5) — stronger motor
- **Vas 80.4 L** per driver (vs 28 L) — suits a ~75 L sealed chamber
- **Qts 0.43** (vs 0.38) — works well with a Linkwitz Transform to 0.707
- Cost increase is modest: ~€75 vs ~€45 per driver

The push-push configuration, side mounting, sealed alignment, and 150 Hz LR4
bass/mid crossover are all retained. Only the woofer driver and bass volume change.

## Consequence

- **Bass volume:** ~75 L under the divider plate (was ~69 L total).
- **Sealed alignment:** Fc ~39 Hz, Qtc ~0.76 (was ~34.5 Hz / 0.62).
- **Linkwitz Transform:** Fc 39.0 → 28 Hz, Qtc 0.76 → 0.707 (was 47.2 → 28 Hz,
  0.63 → 0.707).
- **Woofer cutout:** 284 mm (was 185 mm) — larger side-panel cutout.
- **Opposed magnet clearance:** only ~4 mm at 276 mm internal width (vs ~22 mm
  for the 8SW). The coupling block (h=20 mm, r=55 mm) and basket profile must be
  verified against a physical 12SW before committing the cabinet.
- **Sensitivity:** 84.5 dB (vs 85.0) — slightly more amplifier power needed, but
  the displacement advantage dominates at low frequencies.
- **Power handling:** 250 W (vs 100 W) — higher thermal capacity.
- DD-004 (8SW selection) is superseded; the 8SW remains in the repo as a
  historical comparison driver.

# DD-016 - ScanSpeak 18W/4424G00 midrange, mid-over-waveguide layout

## Decision

Replace the ScanSpeak 15W/4434G00 midrange with the **ScanSpeak 18W/4424G00**
(Discovery, 18 cm, 4 Ω), and flip the front layout: the midrange moves to the
**top** of the baffle, the waveguide/tweeter sits **below** it, and the
full-width tilted divider plate runs **between** them (sealed mid chamber
above, bass volume below). Mid/tweeter c-c becomes 165 mm.

## Reasoning

- **Chamber volumes finally close.** With the old tweeter-on-top layout the
  divider had to sit below the midrange at ~2/3 height, leaving only ~45 L
  net for the bass (target 75 L) while the mid chamber ballooned to ~31 L.
  With the mid on top, the divider rises to ~900 mm: bass grows to **~65 L
  net** (predicted Qtc ~0.80 / Fc ~41 Hz, workable with the Linkwitz
  Transform) and the mid chamber shrinks to **~11 L net** — right at the
  18W's official closed-box recommendation (13 L), predicted Qtc ~0.68 /
  Fc ~88 Hz, comfortably below the 150 Hz LR4 highpass.
- **Driver match.** 91 dB sensitivity is within 0.5 dB of the SB26STAC
  (vs 1.5 dB for the 15W); Sd 137 cm² (vs 80) gives more headroom at the
  150 Hz highpass; Xmax ±2.8 mm is adequate above 150 Hz.
- **Documented dimensions.** The 18W drawing (assets/datasheets/
  18W-4424G00.pdf) is fully dimensioned: Ø179.2 faceplate, Ø144.3 cutout,
  Ø167 BCD (6×Ø5.3), 72.2 mm depth — modeled parametrically in
  `cad/midrange.scad`, which `cad/cabinet.scad` imports directly.

## Consequence

- Mid/tweeter c-c grows from 150 to **165 mm** — the physical minimum with
  the Ø179.2 faceplate and the 143 mm waveguide flange both flush-recessed.
  At 1100 Hz (λ ≈ 312 mm) this is ~0.53 λ: vertical lobing must be
  re-checked in simulation/measurement, and the crossover may need to move
  down or the c-c tightened by surface-mounting one part (DD-011's 140 mm
  target is formally superseded).
- The tweeter/waveguide moves off the top of the baffle (~805 mm axis
  height at default parameters) — listening axis height must be revisited.
- The waveguide body now hangs in the bass volume; its flange must be
  gasketed against the baffle recess to keep the bass chamber sealed.
- The 18 cm cone narrows earlier than the 15 cm at the top of the mid band;
  the 1100 Hz LR4 must be re-validated against measured directivity.
- 15W/4434G00 files remain in the repo as historical reference.

# DD-017 - 200 Hz BW4 bass/mid crossover + 320 mm cabinet width (v9)

## Decision

1. Change the bass/mid crossover from **150 Hz LR4** to **200 Hz BW4**
   (Butterworth 4th order). The mid/tweeter crossover remains 1100 Hz LR4.
2. Increase cabinet width from **300 mm to 320 mm** (external), depth to
   380 mm, height to 1180 mm. Front roundovers revised from R50 to R19.
3. Rebalance DSP gains to **W0/M-4/T-9** (woofer at 0 dB unity, mid -4 dB,
   tweeter -9 dB) — pad down from unity rather than boosting the woofer.

## Reasoning

- **Crossover:** Simulation (`simulations/crossover_woofer_mid.py`) showed a
  response dip at the woofer rolloff with 150 Hz LR4 slopes. Raising the
  crossover to 200 Hz and switching to BW4 (−3 dB at Fc vs −6 dB for LR4)
  fills the dip and produces a flatter summed response. The 18W/4424G00
  has adequate excursion headroom above 200 Hz (Xmax ±2.8 mm, Fs 49 Hz).
- **Cabinet width:** The 300 mm cabinet (276 mm internal) left only ~4 mm
  clearance between opposed GRS 12SW-4HE magnets. Increasing to 320 mm
  provides a safer margin while remaining a reasonable proportion.
- **Gains:** Joachim's insight — pad the more sensitive channels down from
  unity rather than boosting the woofer. This avoids wasting amplifier
  headroom and keeps the woofer channel at 0 dB. DSP correction reduced
  from ±6 dB to approximately ±1.3 dB.

## Consequence

- DSP XML config updated: `dsp-configs/mk3-v9-200-1100-bw4-lr4.xml`
- Baffle step per-driver: side woofers D/2 = 190 mm, front mid/tweeter
  W/2 = 160 mm (from `simulations/cabinet_params.py`)
- DD-007 (300 mm cabinet width) and DD-008 (R50 roundovers) are superseded
  for the current design; retained as historical record.
- DD-014 (1100 Hz LR4 mid/tweeter) remains in effect.

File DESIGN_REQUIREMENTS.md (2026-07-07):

# Design Requirements

## Acoustic Targets

- Approx. ±1.5 dB on-axis response
- Smooth directivity index
- Controlled horizontal radiation
- Useful ±15° vertical listening window
- Smooth predicted in-room response

## Driver Layout

- 2 × GRS 12SW-4HE (side-mounted push-push)
- ScanSpeak 18W/4424G00 midrange at the top of the front baffle
- SB Acoustics SB26STAC-C000-4 in the custom waveguide, below the midrange
- Custom waveguide (SB26STAC version, no horn loading)
- Full-width tilted divider plate between midrange and waveguide
  (sealed mid chamber above, bass volume below)

## Cabinet

- 320 × 370 × 1080 mm (width driven by the opposed 12" woofer depth)
- 22 mm birch plywood
- R19 front roundovers (R50 leaves no flat for the 242 mm waveguide flange)

## Alignment

- ~65 L net sealed bass chamber (below divider plate; 75 L remains the target)
- Qtc ≈ 0.707 (via Linkwitz Transform target)
- Sealed Fc ≈ 41 Hz → 28 Hz after LT
- Sealed mid chamber ~11 L net (18W/4424G00 datasheet closed-box rec.: 13 L)
- Woofer cutout: 284 mm (GRS 12SW-4HE)

## Crossovers

- 200 Hz BW4
- 1100 Hz LR4

## Geometry

- Mid/tweeter c-c spacing: **165 mm** — the physical minimum with the Ø179.2 mm 18W/4424G00 faceplate and the 143 mm waveguide flange both flush-recessed in the baffle (`cad/cabinet.scad` echoes the computed minimum). The earlier 140 mm target (DD-011) is not reachable with these parts. Confirm from physical parts before locking the cabinet model.

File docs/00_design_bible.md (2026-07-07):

# Mk3 Reference Loudspeaker - Design Bible

## About this document

This is the master documentation index for the Mk3 Reference Loudspeaker project. Each chapter covers one aspect of the design process, from initial goals through theory, driver selection, cabinet development, simulation, measurement, and build.

The design bible is a living document. It will be updated as the project progresses from simulation to physical prototype to final tuning.

---

## Current design summary - v9 (in progress)

- Active 3-way loudspeaker with DSP crossovers
- 2 × GRS 12SW-4HE woofers (side-mounted push-push, 12" high excursion)
- ScanSpeak 18W/4424G00 midrange at the TOP of the baffle (`cad/midrange.scad`)
- SB Acoustics SB26STAC-C000-4 tweeter in a custom non-horn-loaded waveguide (`cad/waveguide.scad`), mounted BELOW the midrange
- Full-width tilted divider plate between midrange and waveguide: mid chamber above (~11 L net), bass volume below (~65 L net)
- Cabinet: 320 × 380 × 1180 mm, 22 mm birch plywood, R19 front roundovers
- Bass: ~65 L net sealed, Fc ~41 Hz → 28 Hz via LT, Qtc target 0.707 after LT
- Mid chamber: predicted Qtc ~0.68, Fc ~88 Hz (18W datasheet closed-box rec.: 13 L)
- Crossovers: 200 Hz BW4 (bass/mid), 1100 Hz LR4 (mid/tweeter, re-validate for 18 cm cone)
- Mid/tweeter c-c: 165 mm (physical minimum with these flanges; DD-016)

---

## Chapters

| # | Title | File | Status |
|---|---|---|---|
| 1 | Project goals and philosophy | [01_project_goals.md](01_project_goals.md) | Complete |
| 2 | Loudspeaker theory | [02_theory.md](02_theory.md) | Complete |
| 3 | Woofer investigations | [03_woofer_selection.md](03_woofer_selection.md) | Complete |
| 4 | Midrange investigations | [04_midrange_selection.md](04_midrange_selection.md) | Complete |
| 5 | Tweeter investigations | [05_tweeter_selection.md](05_tweeter_selection.md) | Complete |
| 6 | Waveguide development | [06_waveguide_development.md](06_waveguide_development.md) | Complete (CAD done; print + measure pending) |
| 7 | Cabinet development | [07_cabinet_development.md](07_cabinet_development.md) | Complete (CAD done; build pending) |
| 8 | Push-push bass | [08_push_push_bass.md](08_push_push_bass.md) | Complete |
| 9 | Volume calculations | [09_volume_calculations.md](09_volume_calculations.md) | Complete |
| 10 | Bracing | [10_bracing.md](10_bracing.md) | Complete (representational CAD; detail pending build) |
| 11 | Crossovers | [11_crossovers.md](11_crossovers.md) | Complete (frequency pending distortion measurement) |
| 12 | Directivity | [12_directivity.md](12_directivity.md) | Complete |
| 13 | Spinorama | [13_spinorama.md](13_spinorama.md) | Complete (estimated; true spinorama pending build) |
| 14 | DSP | [14_dsp.md](14_dsp.md) | Complete (platform selected: MiniDSP 4×10 HD) |
| 15 | Measurements | [15_measurements.md](15_measurements.md) | Plan written; execution pending prototype |
| 16 | Build guide | [16_build_guide.md](16_build_guide.md) | Plan written; execution not started |
| 17 | Future versions | [17_future_versions.md](17_future_versions.md) | Complete |

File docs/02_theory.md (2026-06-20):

# Chapter 2 - Loudspeaker Theory

This chapter summarizes the key acoustic concepts that inform the design decisions in this project.

---

## Frequency response

The on-axis frequency response is the most commonly cited loudspeaker measurement. It describes how much sound pressure the loudspeaker produces at each frequency when measured directly in front of the speaker.

On-axis response alone is a poor predictor of real-world performance. Most of the sound reaching a listener in a room arrives as reflections, not as direct sound. For this reason, the full set of measurements described by the spinorama standard is more useful than on-axis response in isolation.

A flat on-axis response is still important. Large deviations will usually be audible regardless of room conditions.

---

## Listening window

The listening window is the average of several measurements taken over a small angular range around the on-axis position. The standard CEA-2034 listening window averages:

- 0° (on-axis)
- ±10° horizontal
- ±10° vertical

This average is more representative of the direct sound arriving at a real seated listener than the strict on-axis measurement alone.

---

## Early reflections

Early reflections arrive at the listener within approximately 20 ms after the direct sound. They originate from the floor, ceiling, and side walls near the loudspeaker. In a typical room, early reflections contribute significantly to tonal balance and perceived spaciousness.

The early reflections curve in the CEA-2034 standard averages several specific off-axis angles intended to represent these room reflection paths.

A smooth early reflections curve - and a small difference between the early reflections and the listening window - predicts good in-room behavior.

---

## Sound power

The sound power response is the energy average of the loudspeaker output across all directions. In a highly reverberant space the sound power response dominates the perceived tonal balance. In a typical listening room it contributes alongside the direct sound and early reflections.

A loudspeaker with smooth sound power (usually gently declining from bass to treble) tends to sound tonally neutral across a range of rooms.

---

## Predicted in-room response

The predicted in-room response (PIR) is a weighted sum of the listening window, early reflections, and sound power curves. The weighting is designed to approximate the integrated response a listener hears in a typical room.

The Harman target for PIR is a gentle downward slope from bass to treble, approximately -1 to -2 dB per octave. This slope matches the frequency balance most listeners prefer and accounts for the typical room high-frequency absorption.

---

## Directivity Index (DI)

The Directivity Index describes how directional the loudspeaker is at each frequency. It is defined as the difference between the on-axis response and the sound power response, in dB.

A high DI means the loudspeaker radiates much more sound forward than in other directions. A low DI means the loudspeaker radiates sound more evenly in all directions.

For a reference loudspeaker, a DI that rises smoothly with frequency is preferred. This matches the directivity of a natural sound source (voices and instruments also become more directional at high frequencies) and produces a consistent sense of space.

Sudden changes or dips in the DI indicate directivity problems - usually crossover lobing, cabinet diffraction, or driver beaming effects.

---

## Lobing

When two drivers are crossing over in the same frequency region, their outputs combine in a frequency- and angle-dependent way. The resulting polar pattern shows lobes - directions where the combined output is boosted or cancelled.

Lobing is reduced by:

- Shortening the center-to-center distance between the drivers
- Lowering the crossover frequency
- Using steeper crossover slopes

In the vertical plane, lobing is particularly important because the listening window must remain smooth over the typical ±15° vertical range of a seated listener.

---

## Group delay

Group delay is the derivative of the phase response with respect to frequency. A constant group delay means all frequencies arrive at the listener at the same time. A non-constant group delay means some frequencies are delayed relative to others.

High-order passive crossovers and ported bass alignments can introduce significant group delay at low frequencies. Active LR4 crossovers are relatively well-behaved in this regard. DSP allows delay compensation between drivers to minimize group delay at the crossover frequencies.

---

## FIR vs IIR filters

**IIR (Infinite Impulse Response)** filters are the standard digital implementation of classical analog filter designs (Linkwitz-Riley, Butterworth, etc.). They are computationally efficient and widely used in DSP hardware. They introduce phase shift as a side effect of their filtering action.

**FIR (Finite Impulse Response)** filters can be designed with linear phase response - meaning they introduce no phase distortion, only a fixed time delay. This allows crossovers with no phase shift at the crossover point. FIR filters require more computational resources and introduce a fixed latency.

For the initial prototype, IIR (LR4) crossovers will be used. FIR filters are noted as a future upgrade path in v10.

---

## Toole and Olive research

Floyd Toole and Sean Olive at Harman International conducted extensive research on loudspeaker perception in real rooms, correlating acoustic measurements with listener preference ratings.

Key findings:

- Listener preference correlates strongly with a flat and smooth listening window, a smooth and consistent sound power response, and a narrow difference between on-axis and early reflections curves.
- Coloration and resonances in the off-axis response are as audible as on-axis problems.
- A gently declining predicted in-room response is preferred over a flat one, due to typical room high-frequency absorption.
- The spinorama standard (CEA-2034) was developed as a standardized set of measurements to capture these properties.

These findings are the primary basis for the design optimization strategy in this project. The goal is not to optimize for any single measurement, but to produce a well-shaped spinorama set.

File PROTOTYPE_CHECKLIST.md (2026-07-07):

# Prototype Checklist — Next Gate

## What you need to do before building the cabinet

3 steps. That's it. Do them in order.

---

## Step 1 — Print the SB26STAC waveguide

| Property | Current value | Status |
|---|---|---|
| STL source | `cad/exports/waveguide.stl` (or local: `openscad -o waveguide.stl cad/waveguide.scad`) | ✅ Ready |
| Material | PETG recommended | |
| Orientation | Print flat — flange down, throat up | |
| Post-print | Slow cool to avoid warping | |

**Known dimensions (do NOT change without measurement):**

| Dimension | Value | Source | Caliper verify? |
|---|---|---|---|
| Throat diameter | ø28 mm (dome + surround) | SB26STAC datasheet + SCAD | ☐ |
| BCD (screw circle) | ø88.5 mm | SCAD (SB26STAC faceplate) | ☐ |
| Mouth size (H×V) | from SCAD echo | SCAD | |
| Total depth | from SCAD | SCAD | |
| Flange (W×H) | from SCAD | SCAD | |

### SB26STAC tweeter mounting — verify before bonding

| Dimension | Expected | Check with caliper | Pass? |
|---|---|---|---|
| Faceplate OD | ~100 mm | ☐ Measure from physical unit | ☐ |
| Screw hole BCD | ø88.5 mm | ☐ Centre-to-centre across | ☐ |
| Throat through-hole | ø28 mm — dome + surround must sit fully inside bore | ☐ Visual check after test-fit | ☐ |
| Recess depth | from datasheet | ☐ | ☐ |

> **Note:** SB26STAC-C000-4 has no STEP file from SB Acoustics. All dimensions are from the PDF datasheet and must be caliper-verified before committing to a print.

### Baffle mounting holes — verify before drilling

| Dimension | Expected | Check | Pass? |
|---|---|---|---|
| BCD x | from SCAD | ☐ | ☐ |
| BCD y | from SCAD | ☐ | ☐ |
| Screw diameter | from datasheet | ☐ | ☐ |

---

## Step 2 — Confirm driver cutout diameters from real parts

**These are still estimates — confirm from physical driver before cutting baffle.**

| Driver | Cutout diameter | Status | Verify from |
|---|---|---|---|
| GRS 12SW-4HE (woofer) | ø284 mm | ⚠️ Estimate from datasheet (embedded fonts block text extraction) | ☐ Caliper on physical unit |
| ScanSpeak 18W/4424G00 (mid) | Ø144.3 mm (Ø179.2 faceplate) | From official datasheet + cad/midrange.scad | ☐ Verify anyway |
| SB26STAC waveguide mouth (baffle aperture) | from SCAD | ✅ Auto-propagating from waveguide.scad | ☐ Measure printed part |

---

## Step 3 — Distortion test: SB26STAC at 1100 Hz

This is **the design gate**. If the SB26STAC can't do 1100 Hz with low distortion, the crossover frequency shifts up.

**Setup:**
- Mount SB26STAC in the printed waveguide
- Use a solid baffle (cardboard or ply test panel) with the waveguide aperture cut
- Measure nearfield with measurement mic (UMIK-1 or similar)
- Signal: 2.83 V sine sweep

**What to check:**

| Frequency | Acceptable THD | Action |
|---|---|---|
| 1100 Hz | < 2% | ✅ Crossover target confirmed at 1100 Hz LR4 |
| 1300 Hz | < 2% | Shift crossover up; update fc_mid in all simulation scripts |
| 1500 Hz | < 2% | Same as above |
| 1800 Hz | < 1% | Safe upper limit |

**Why 1100 Hz specifically:** SB26STAC Fs = 750 Hz. Crossover at 1100 Hz is 350 Hz above resonance. The SB26STAC has 0.6 mm Xmax, giving +8.1 dB excursion headroom at crossover. This is a comfortable margin. If distortion is too high, raise to 1300-1500 Hz.

**Recording (note these):**
- Measured THD at 1100 Hz: _____ %
- Measured THD at 1300 Hz: _____ %
- Measured THD at 1500 Hz: _____ %
- Any audible anomalies: ___________

**After the test:**
- [ ] If 1100 Hz passes: confirm fc = 1100 Hz, update DESIGN_DECISIONS.md
- [ ] If 1100 Hz fails: update fc_mid in all simulation scripts + MiniDSP XML config
- [ ] Measure real c-c from printed waveguide flange to 18W frame — expected 165 mm (DD-016)
- [ ] Update cc_mid_tw_mm in design_versions_comparison.py + DESIGN_DECISIONS.md DD-011

---

## Then you can: start the cabinet build

The cabinet CAD is fully parametric. Once these 3 steps are done:

1. Order drivers (2× GRS, 1× 18W/4424G00, 1× SB26STAC-C000-4 per speaker)
2. DSP: MiniDSP 4×10 HD — import `mk3-v9-200-1100-bw4-lr4.xml`
3. Follow `docs/16_build_guide.md` — 10 phases, build log in `BUILD_LOG.md`
4. 22 mm birch plywood, ~4 sheets per pair

---

## CAD current state (as of July 4, 2026)

| Model | File | Notes |
|---|---|---|
| `cad/waveguide.scad` | primary | SB26STAC waveguide: BCD 88.5 mm, throat 28 mm, no horn loading. STL rendered, manifold. |
| `cad/cabinet.scad` | shared | Fully dynamic from waveguide.scad; waveguide recessed inside cabinet, baffle aperture model. Updated for GRS 12SW-4HE (284 mm cutout, ~332 mm frame, ~136 mm depth, 75 L bass under divider plate). |

**Don't cut panels from SCAD outputs until parts are physically verified.**

---

## Quick reference — key dimensions

| Item | Value |
|---|---|
| Cabinet W×D×H | 320 × 380 × 1180 mm (22 mm birch ply) |
| Woofer (each) | GRS 12SW-4HE, 4 Ω, 12" high excursion, side-mounted push-push |
| Woofer centers | ~520 mm from bottom, opposed at same height |
| Midrange | ScanSpeak 18W/4424G00, 4 Ω |
| Tweeter | SB Acoustics SB26STAC-C000-4 in custom waveguide |
| Mid/tweeter c-c | 165 mm (physical minimum with 18W faceplate — verify from real parts, DD-016) |
| Bass crossover | 200 Hz BW4 |
| Mid/tweeter crossover | 1100 Hz LR4 (unconfirmed — Step 3) |
| FR roundovers | R19 on cabinet front vertical edges |
| DSP | MiniDSP 4×10 HD |

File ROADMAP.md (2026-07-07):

# Mk3 Reference Loudspeaker Roadmap

## v9 — 18W/4424G00 midrange, mid-over-waveguide layout (current, in progress)

Current design candidate:

- 320 x 380 x 1180 mm cabinet (width driven by the opposed 12" woofers)
- 22 mm birch plywood
- R19 front roundovers (R50 leaves no flat for the waveguide flange)
- 2 x GRS 12SW-4HE side-mounted push-push woofers (12" high excursion)
- ScanSpeak 18W/4424G00 midrange at the TOP of the baffle (`cad/midrange.scad`)
- SB Acoustics SB26STAC-C000-4 tweeter in the waveguide BELOW the midrange
- Custom non-horn-loaded waveguide (`cad/waveguide.scad`)
- Full-width tilted divider plate between midrange and waveguide
- Approx. 65 L net sealed bass volume (below divider, DD-016)
- Approx. 13 L net sealed mid chamber (18W datasheet closed-box rec.)
- 200 Hz BW4 bass/mid crossover
- 1100 Hz LR4 mid/tweeter crossover
- 165 mm mid/tweeter c-c spacing (physical minimum with 18W faceplate, DD-016)
- DSP gains: Woofer 0 dB (unity), Mid -4.0 dB, Tweeter -9.0 dB (W0/M-4/T-9)
- See CHANGELOG v9, DD-016, DD-017

## v8 — GRS 12SW-4HE woofer upgrade

- 300 x 370 x 1080 mm cabinet (superseded: width -> 320 mm in v9)
- 2 x GRS 12SW-4HE side-mounted push-push woofers (12" high excursion)
- ScanSpeak 15W/4434G00 midrange (superseded by 18W/4424G00 in v9)
- Approx. 75 L sealed bass volume target (under divider plate)
- Approx. 5.7 L sealed mid chamber
- Target 140 mm mid/tweeter c-c spacing

Woofer upgrade details:

- Woofer upgraded from GRS 8SW-4HE-8 (8") to GRS 12SW-4HE (12" high excursion)
- Bass volume increased to ~75 L under divider plate
- Linkwitz Transform: Fc 39→28 Hz, Qtc 0.76→0.707
- Max SPL @ 30 Hz: +16 dB over previous design
- See DD-015, CHANGELOG v8

## v7 — SB26STAC tweeter, 1100 Hz crossover

- SB Acoustics SB26STAC-C000-4 tweeter selected (Fs 750 Hz, 0.6 mm Xmax)
- 1100 Hz LR4 mid/tweeter crossover
- Custom non-horn-loaded waveguide
- GRS 8SW-4HE-8 woofers (superseded in v8 by 12SW)

## v10 — Measurement-validated design

- Build first physical prototype
- Measure all drivers in cabinet
- Import measurements into VituixCAD
- Validate or revise 1100 Hz crossover
- Validate vertical listening window

## v11 — CAD/package refinement

- Final cabinet drawings
- Final waveguide model
- STEP/STL export
- CNC/fræse-ready drawings

## v12 — DSP implementation

- Initial MiniDSP/FusionAmp presets
- Delay optimization
- EQ and target curves
- House curve versions

## v13 — Advanced variants

- FIR filters
- Alternative midranges
- Cardioid/controlled bass experiments

## v14 — Integrated active version

- Integrated amplifier module
- Internal DSP
- Full wiring plan
- Finalized build guide

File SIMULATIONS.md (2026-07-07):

# Simulations

This file tracks simulation work and assumptions for the Mk3 Reference Loudspeaker.

---

# Important Note

The simulations so far are simplified design-direction estimates, not final measured data. They are intended to guide design choices before CAD, prototyping and measurements.

Final crossover and DSP decisions must be based on real measurements in the finished cabinet.

Version-controlled, assumption-headed scripts and their plots now live in
[`simulations/`](simulations/) (`bass_alignment_maxspl.py`, `bass_volume_compare.py`,
`vertical_lobing.py`, `directivity_estimate.py`, `crossover_simulation.py`,
`system_response.py`, `polar_response.py`, `vertical_polar_map.py`,
`system_response_realistic.py`, `spinorama_estimate.py`,
`crossover_optimization.py`, `tweeter_comparison.py`); parametric
OpenSCAD geometry lives in [`cad/`](cad/) (waveguide + cabinet).

### Current design scripts

The following scripts document the current SB26STAC / 1100 Hz design and the
tweeter selection analysis:

- `system_response_realistic.py` — realistic system response using actual
  digitized datasheet frequency-response curves, baffle step, waveguide loading
  and LR4 crossovers.
- `spinorama_estimate.py` — spinorama estimate (on-axis, listening window,
  early reflections, sound power, DI, PIR) using real datasheet curves.
- `crossover_optimization.py` — systematic crossover-frequency sweep for
  the SB26STAC scoring Fs margin, excursion headroom, directivity match,
  vertical lobing ripple and system-sum flatness. Confirms 1100 Hz as optimal.
- `tweeter_comparison.py` — tweeter selection analysis (excursion,
  distortion, sensitivity) documenting why the SB26STAC was chosen.
- `system_response_inroom.py` — four-stage progression: anechoic (pre-DSP)
  → in-room (average living room 4.5×4×2.4m, room gain + HF absorption)
  → level-corrected (normalized @500 Hz) → post-DSP (EQ toward Harman
  in-room target, 1/3 octave PEQ simulation). Uses v9 drivers: 2× GRS
  12SW-4HE, ScanSpeak 18W/4424G00, SB26STAC-C000-4. Output:
  `plots/system_response_inroom.png`, `csv/system_response_inroom.csv`.

---

# In-Room Response Simulation

## Model (added July 6, 2026)

The in-room simulation (`system_response_inroom.py`) extends the anechoic
system response with a room acoustics model and DSP correction simulation.

### Room model — average living room

- Dimensions: 4.5 × 4.0 × 2.4 m (V = 43.2 m³) — typical Danish stue
- RT60 ≈ 0.4 s (furnished room with carpet, curtains, sofa)
- Schroeder frequency: ~192 Hz
- Room gain: +6 dB/octave below f_schroeder, capped at +9 dB
  (3 boundary surfaces + modal density boost)
- HF absorption: −1.5 dB/octave above 5 kHz, capped at −3 dB
  (furnishings, carpet, curtains)

### Harman in-room target curve

- Flat 100 Hz – 1 kHz (0 dB reference)
- Bass shelf: +3.5 dB below 100 Hz (second-order transition)
- HF tilt: −1 dB/octave above 1 kHz

### DSP simulation

- Uses optimized DSP gains (woofer 0 dB (unity), mid −4.0 dB, tweeter −9.0 dB)
- Optimized for in-room response vs Harman target curve
- Simulates ~10 PEQ bands at 1/3 octave resolution
- DSP correction range: ±1.3 dB (smoothed, 1/3 octave)
- Residual deviation from target: ±0.3 dB (500 Hz – 10 kHz)

### Results

| Stage | Ripple 200–15k | Ripple 500–10k | @100 Hz | @500 Hz | @2 kHz | @10 kHz |
|---|---|---|---|---|---|---|
| Anechoic (pre-DSP) | 3.4 dB | 2.8 dB | 82.9 | 86.9 | 84.5 | 85.1 |
| In-room | 4.3 dB | 3.7 dB | 88.6 | 86.9 | 84.5 | 83.6 |
| Level-corrected | 4.3 dB | 3.7 dB | 1.7 | 0.0 | −2.3 | −3.3 |
| Post-DSP | 4.8 dB | 3.5 dB | 1.7 | 0.1 | −1.0 | −3.3 |

Post-DSP deviation from Harman target: ±0.3 dB (500 Hz – 10 kHz).
The 4.8 dB ripple 200–15k is the intentional bass shelf + HF tilt, not ripple.

### Target comparison: Harman vs BBC-style

A second target curve (BBC-style) was optimized with its own gain set:

| Target | Woofer | Mid | Tweeter | W-M | M-T | Pre-EQ RMS | Post-DSP residual |
|---|---|---|---|---|---|---|---|
| Harman | 0.0 dB | −4.0 dB | −9.0 dB | 5.5 dB | 5.0 dB | 0.89 dB | ±0.3 dB |
| BBC-style | 0.0 dB | −3.0 dB | −8.0 dB | 4.5 dB | 5.0 dB | 0.88 dB | ±0.3 dB |

BBC target: −2 dB presence dip at 2 kHz, +2 dB bass shelf below 120 Hz,
−0.8 dB/octave HF tilt above 3 kHz. Both targets achievable with ±2.0 dB
DSP correction. M-T spread is 5.0 dB for both; only W-M differs (BBC
needs 1 dB less due to the presence dip lowering the mid region).

---

# Bass Simulations

## Current assumption

- 2 x GRS 12SW-4HE
- Sealed cabinet, ~75 L net (volume under divider plate)
- Fs 22 Hz
- Vas 80.4 L per driver (160.8 L combined)
- Qts 0.43
- Xmax 12.5 mm (Klippel verified), Sd 504 cm²

## Current estimate

- Sealed Fc ~39 Hz, Qtc ~0.76
- Linkwitz Transform target: Fc 39.0 → 28 Hz, Qtc 0.76 → 0.707
- Max SPL @ 30 Hz: +16 dB over the previous 8SW design
- Displacement: 12.6 cm³ (was 2.0 cm³ with the 8SW)

## Interpretation

This is a low-Q sealed alignment with a Linkwitz Transform to 28 Hz / 0.707. The
12SW's large Sd and high Xmax give substantially more low-frequency headroom than
the previous 8SW.

---

# Cabinet Width and Roundover Simulations

Variants explored:

- 270 mm front
- 280 mm front
- 300 mm front
- 320 mm front
- 340 mm front
- R20-R70 roundovers

## Current conclusion

320 mm front width with R19 vertical front roundovers is the current v9 cabinet (see `cad/cabinet.scad`). The width was increased from 300 mm to fit two opposed 136 mm-deep 12SW-4HE woofers (276 mm internal width required).

---

# Waveguide and Crossover Simulations

Variants explored:

- ~212 to ~240 mm waveguide mouths
- 1100-1600 Hz mid/tweeter crossover region
- 140-157 mm c-c spacing

## Current conclusion

The strongest improvement comes from:

- Lower mid/tweeter crossover
- Shorter c-c spacing
- Smooth baffle/waveguide integration

The custom SB26STAC waveguide with approx. 1100 Hz LR4 and 140 mm c-c is the current best simplified candidate.

---

# Spinorama-style Curves

Curves to maintain:

- On-axis
- Listening window
- Early reflections estimate
- Sound power estimate
- Predicted in-room estimate
- Directivity Index

---

# Simulation Tasks

- [x] Recreate all current Python simulations in version-controlled scripts
- [x] Add assumptions at top of each script
- [x] Export plots to `simulations/plots/` (CI auto-commits on every push)
- [x] Export CSV data to `simulations/csv/` (crossover, system, spinorama, polar, vertical)
- [x] Create a comparison table for all design versions (`design_versions_comparison.py` → `design_versions.md` + `csv/design_versions.csv`)
- [ ] Validate against actual measurements (blocked: prototype not yet built)

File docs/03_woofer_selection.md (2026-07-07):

# Chapter 3 - Woofer Investigations

---

## Requirements

The woofer system must:

- Cover the bass range from approximately 20-25 Hz to 200 Hz
- Be suitable for a sealed alignment with Qtc around 0.6-0.65
- Produce useful output below 30 Hz with DSP assistance
- Fit two drivers side-mounted in a 320 mm wide cabinet
- Have sufficient excursion for realistic SPL at low frequencies
- Have an acceptable cost/performance ratio for a DIY project

A 12-inch driver size was selected as the target, as it provides high excursion and large radiating surface area for deep bass output in a moderate sealed cabinet. (An earlier 8-inch target — GRS 8SW-4HE-8 — was used through v7 and is retained below as a historical comparison.)

---

## Investigated drivers

### SB Acoustics SB23 (initial concept, v1)

The SB23 family was the starting point in the earliest concept phase (v1). The SB23 is a well-regarded driver with good T/S parameters, but it was replaced as the project evolved and the bass volume requirements became clearer.

**Outcome:** Not selected. Used as the starting reference point only.

---

### GRS 8SW-4HE-8 (historical — v3 through v7, superseded by 12SW)

The GRS 8SW-4HE-8 was introduced in v3 and served as the woofer through v7. It has
been superseded by the GRS 12SW-4HE (see below) for the v8 bass upgrade. It is
retained here as a historical comparison.

**Key T/S parameters (manufacturer data):**

| Parameter | Value |
|---|---|
| Fs | ~24.9 Hz |
| Vas | ~31.7 L |
| Qts | ~0.45 |
| Re | ~3.8 Ω |
| Xmax | ~10.8 mm |
| Sd | ~227 cm² |

T/S values are from the SoundImports datasheet and must be verified against the
official GRS sheet before construction. Use the conservative datasheet **Xmax
~10.8 mm** for any excursion/SPL estimate; the ~13 mm figure quoted elsewhere is
likely an Xmech/peak number, not Xmax.

**Two drivers in series:**
- Total impedance: ~8 Ω nominal
- Combined Vas: approximately 2 × 31.7 L = 63.4 L equivalent (for one equivalent driver)
- Combined Sd: approximately 2 × 227 cm² = 454 cm²

**Sealed alignment — two drivers in 69 L net (historical, v7):**

Two identical drivers sharing one sealed box behave like a single equivalent
driver with `Sd_total = 2 × Sd` and `Vas_total = 2 × Vas_single = 63.4 L`. The
sealed alignment is then:

```
Qtc = Qts × sqrt(1 + Vas_total / Vb) = 0.45 × sqrt(1 + 63.4/69) ≈ 0.62
Fc  = Fs  × sqrt(1 + Vas_total / Vb) = 24.9 × sqrt(1 + 63.4/69) ≈ 34.5 Hz
```

So for two GRS 8SW-4HE-8 in a sealed cabinet (historical v7 simulation target):

- Net bass volume: ~69 L
- Fc: ~34.5 Hz
- Qtc: ~0.62

This is a low-Q sealed alignment that:
- Has a well-controlled rolloff
- Responds well to DSP bass extension (Linkwitz Transform or shelf boost)
- Produces low group delay compared with heavily tuned ported designs

**Strengths:**

- Low Fs suitable for deep bass in a moderate cabinet
- Good excursion for the price
- 4-ohm nominal impedance allows series wiring to 8 Ω (suitable for most amplifiers)
- Fits the cabinet geometry and mounting requirements

**Weaknesses / open items:**

- Verify exact cutout and frame dimensions before cabinet construction
- Verify push-push wiring phase: the rear-mounted woofer must be wired in reversed polarity to maintain acoustic push-push cancellation of cabinet reaction forces

### GRS 12SW-4HE (selected — v8)

The GRS 12SW-4HE is a 12-inch high-excursion woofer selected for the v8 bass
upgrade, replacing the 8SW. The push-push configuration and sealed alignment are
retained.

**Key T/S parameters (manufacturer data, Klippel-verified Xmax):**

| Parameter | Value |
|---|---|
| Fs | 22 Hz |
| Vas | 80.4 L |
| Qts | 0.43 |
| Sd | 504 cm² |
| Xmax | 12.5 mm (Klippel verified) |
| Bl | 16.2 Tm |
| Sensitivity | 84.5 dB |
| Power | 250 W |
| Impedance | 4 Ω |
| Cutout diameter | 284 mm |

**Two drivers in series:**
- Total impedance: ~8 Ω nominal
- Combined Vas: 2 × 80.4 = 160.8 L equivalent
- Combined Sd: 2 × 504 = 1008 cm²

**Sealed alignment — two drivers in ~75 L net (under divider plate):**

```
Qtc = Qts × sqrt(1 + Vas_total / Vb) = 0.43 × sqrt(1 + 160.8/75) ≈ 0.76
Fc  = Fs  × sqrt(1 + Vas_total / Vb) = 22.0 × sqrt(1 + 160.8/75) ≈ 39.0 Hz
```

So for two GRS 12SW-4HE in a sealed cabinet (v8 target):

- Net bass volume: ~75 L (under the divider plate)
- Sealed Fc: ~39 Hz, Qtc: ~0.76
- Linkwitz Transform target: Fc 39.0 → 28 Hz, Qtc 0.76 → 0.707

**Displacement and max SPL:**
- Peak displacement (2 drivers): 2 × Sd × Xmax = 2 × 504 cm² × 12.5 mm = 12.6 cm³
- vs 8SW pair: 2.0 cm³ — a 6.3× increase
- Max SPL @ 30 Hz: **+16 dB** over the previous 8SW design

**Strengths:**

- Very low Fs (22 Hz) — deep bass extension in a moderate sealed cabinet
- High excursion (12.5 mm Xmax, Klippel verified) for low-distortion SPL
- Large Sd (504 cm²) for efficient air displacement
- Good cost/performance ratio (~€75 per driver)
- Qts 0.43 works well with a Linkwitz Transform to a 0.707 target

**Weaknesses / open items:**

- Large frame (~332 mm overall) and 284 mm cutout — verify fit on 370 mm deep
  side panels
- Basket depth ~136 mm — opposed magnets have only ~4 mm clearance in the
  276 mm internal width (vs ~22 mm for the old 8SW). Coupling block must be sized
  accordingly.
- Lower sensitivity (84.5 dB) than the 8SW — more amplifier power needed, but the
  6.3× displacement advantage dominates at low frequencies
- Verify push-push wiring phase and coupling block fit before finalizing CAD

---

## Configuration: push-push

Two woofers, one front-mounted and one rear-mounted (or both side-mounted facing outward), wired so that as one cone moves outward the other cone also moves outward into free air. This means the reaction forces on the cabinet are equal and opposite, cancelling rather than summing.

See Chapter 8 (Push-push bass) for full detail.

---

## Wiring

Two 4-ohm woofers wired in series: nominal 8 Ω total load.

Parallel wiring (2 Ω total) is possible if the amplifier channel is rated for 2-ohm loads, but series wiring is safer for most DSP/amplifier hardware.

**Confirm impedance before wiring.** The GRS 12SW-4HE is a 4 Ω driver; two in
series gives the intended 8 Ω load. Verify the actual DCR of the delivered drivers
before committing the wiring.

---

## Current status

GRS 12SW-4HE selected (v8). The previous GRS 8SW-4HE-8 is retained as a historical
comparison. Exact mechanical dimensions (cutout 284 mm, frame ~332 mm, mounting
depth ~136 mm, opposed magnet clearance ~4 mm) must be verified before cabinet CAD
is finalized.

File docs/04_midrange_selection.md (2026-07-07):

# Chapter 4 - Midrange Investigations

> **v9 update:** the midrange driver is now the **ScanSpeak 18W/4424G00**
> (Discovery, 18 cm) — see DD-016 and CHANGELOG v9. It replaces the
> 15W/4434G00 selected below; the 15W analysis is kept as the selection
> history. Datasheet: `assets/datasheets/18W-4424G00.md`; parametric model:
> `cad/midrange.scad`.

---

## Requirements

The midrange driver must:

- Cover the range from approximately 200 Hz to 1100 Hz
- Be a 15 cm (6-inch class) driver with good off-axis response in the midrange
- Have low distortion at normal listening levels in the 200-1000 Hz range
- Fit within a 320 mm wide baffle with the waveguide above it at 140 mm c-c
- Operate in a dedicated sealed chamber of approximately 5.7 L net

A 15 cm driver size is preferred over smaller drivers for this range because:
- It can reach down to 200 Hz without excessive excursion or rolloff
- It remains small enough that its directivity begins narrowing (in free-field) above approximately 1200-1500 Hz, which matches the target crossover frequency
- The radiating diameter is compatible with achieving the 140 mm c-c spacing to the waveguide

---

## Investigated driver

### ScanSpeak 15W/4434G00 (selected)

The ScanSpeak Illuminator 15W/4434G00 is the midrange driver selected for this project.

**Key characteristics:**

| Parameter | Value |
|---|---|
| Nominal diameter | 15 cm (6 inch) |
| Re | ~5.6 Ω |
| Fs | ~55 Hz |
| Sensitivity | ~89.7 dB / 2.83V / 1m |
| Xmax | ~7 mm |
| Sd | ~107 cm² |

**Why the ScanSpeak 15W:**

- The Illuminator series is known for low distortion and smooth frequency response
- The 15W cone area provides sufficient output from 200 Hz without requiring excessive amplifier power
- The upper frequency limit in a baffle is well-suited to a 1100 Hz crossover with LR4 slopes
- ScanSpeak has detailed datasheet and measured data available, supporting simulation work
- Good availability through European suppliers

**Sealed mid chamber:**

The 15W operates in a dedicated sealed chamber of approximately 5.7 L net. The chamber isolates the midrange from the bass chamber acoustically and provides a controlled rear loading.

The chamber must be:
- Lined with absorptive material (not overstuffed)
- Sealed from the bass chamber
- Designed so the midrange mounting depth fits within the cabinet internal dimensions

---

## Crossover integration

The midrange is crossed:

- High-pass at 200 Hz (BW4) from the bass system
- Low-pass at 1100 Hz (LR4) to the tweeter/waveguide

The 200 Hz crossover point is low enough that the 15W does not need to produce significant bass output. The 1100 Hz crossover point is within the normal operating range of this driver with the cabinet geometry.

**Vertical lobing:** The 140 mm c-c spacing between the 15W midrange and the waveguide tweeter determines the vertical lobing pattern at the mid/tweeter crossover. See Chapter 11 (Crossovers) and Chapter 12 (Directivity) for detail.

---

## Open items

- Verify exact mounting depth to confirm fit with mid chamber dimensions
- Verify off-axis response at 1100 Hz from measurements in finished cabinet
- Confirm that 1100 Hz LR4 does not require excessive excursion from the 15W below the crossover

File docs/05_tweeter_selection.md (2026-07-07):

# Chapter 5 - Tweeter Investigations

---

## Requirements

The tweeter must:

- Cover the range from 1100 Hz to beyond 20 kHz
- Be suitable for mounting in a custom waveguide
- Have sufficient power handling and headroom at 1100 Hz
- Have low distortion at 1100 Hz and above
- Have a dome/surround geometry compatible with the waveguide throat design
- Fit within the 320 mm baffle at 140 mm c-c from the midrange

---

## Selected driver

### SB Acoustics SB26STAC-C000-4

A 26mm soft dome tweeter with cast aluminium faceplate, copper-capped pole piece, and a non-reflective rear chamber with optimized damping.

**Key specifications:**

| Parameter | Value |
|---|---|
| Series | SB26 |
| Type | Conventional soft dome (no built-in horn) |
| Dome diameter | 26 mm / 1" |
| Dome material | Fine weave fabric |
| Impedance | 4 Ω |
| Re | 3.2 Ω |
| **Fs** | **750 Hz** |
| **Sensitivity** | **91.5 dB / 2.83V / 1m** |
| Le | 0.04 mH |
| Qms | 3.0 |
| Qes | 1.78 |
| Qts | 1.12 |
| BL | 1.6 Tm |
| Mms | 0.3 g |
| **Xmax (one-way)** | **0.6 mm** |
| **Linear travel (p-p)** | **1.2 mm** |
| Sd | 6.2 cm² |
| Power (RMS) | 120 W |
| Power test | IEC 268-5, HP Butterworth 2600 Hz 12 dB/oct |
| Faceplate Ø | 100.0 ±0.35 mm |
| BCD | 88.5 ±0.10 mm |
| Mounting holes | 4-Ø4.0 + 4-Ø8.0 counterbore |
| Recess Ø | 53.0 mm |
| Total depth | 39.7 mm |
| Net weight | 0.53 kg |
| Price | ~€37 |
| STEP file | **Not available** (manual caliper measurement required) |

Datasheet: `assets/datasheets/SB26STAC-C000-4.pdf`

---

## Why the SB26STAC was selected

The SB26STAC was chosen through a systematic selection analysis (see
`docs/SB26STAC-C000-4_analysis.md` for the full analysis and simulation
results). Its key advantages:

- **Fs 750 Hz gives 350 Hz margin at the 1100 Hz crossover** — a comfortable
  margin that requires no distortion-test gate before committing to the
  crossover frequency.
- **0.6 mm Xmax gives +8.1 dB excursion headroom** at 1100 Hz — 3× the linear
  travel of a typical 1" dome tweeter, substantially more maximum SPL capability
  near the crossover.
- **91.5 dB sensitivity is a better match to the 15W/4434G00's 89.7 dB** — only
  -1.8 dB of DSP pad is needed. This reduces wasted amplifier power and the
  thermal/level mismatch.
- **No ferrofluid** — vented pole piece instead, eliminating the long-term
  ferrofluid aging concern.

---

## Driver character

The SB26STAC is a conventional dome tweeter — no built-in horn. The dome radiates directly into the waveguide throat, which provides the acoustic loading and directivity control.

The fine weave fabric dome produces a smooth, non-aggressive character. The copper-capped pole piece reduces voice coil inductance and phase shift, improving transient response. The non-reflective rear chamber with vented pole piece provides damping without ferrofluid, eliminating the long-term aging concern.

The 0.6mm one-way Xmax is exceptional for a 1" dome tweeter. This directly translates to higher maximum SPL at the crossover frequency before distortion rises.

---

## Sensitivity matching

At 91.5 dB / 2.83V / 1m, the SB26STAC is 1.8 dB more sensitive than the 15W midrange (~89.7 dB). This requires only ~2 dB of DSP attenuation on the tweeter channel — a natural match.

In the waveguide, the SB26STAC will gain 2-3 dB of acoustic loading, bringing effective sensitivity to ~94 dB. The exact pad is finalized from measurement.

---

## Waveguide integration

The SB26STAC has no built-in horn — the 26mm dome radiates directly. The custom waveguide (`cad/waveguide.scad`) starts its OS bore at Ø28mm (dome + ~1mm surround per side) and provides the full directivity control.

Key waveguide dimensions:

| Parameter | Value |
|---|---|
| Throat diameter | 28 mm (dome + surround) |
| Coverage angles | 100° H × 64° V |
| Mouth size | 293 × 173 mm |
| Total depth | 98 mm |
| Rear plate | Ø115 mm |
| Faceplate pocket | Ø101 × 4mm deep |
| Baffle mounting | Flange recessed into baffle |

**Open item:** The throat diameter (28mm) is estimated from the 26mm dome + surround. The faceplate has a Ø53mm recess around the dome. Physical caliper measurement is needed to confirm the exact throat transition before the final print.

---

## Crossover integration

The tweeter is:
- **High-pass at 1100 Hz LR4**
- Approximately -2 dB gain adjustment in DSP to match midrange sensitivity
- DSP delay applied to align acoustic center with midrange

The 1100 Hz crossover is selected because:
1. **Fs margin:** 350 Hz above the 750 Hz resonance — comfortable, no distortion test gate
2. **Directivity:** Better DI match with the 15W at 1100 Hz (4.6 dB mismatch)
3. **Lobing:** The broadside null for 150mm c-c is at 1147 Hz — just above the 1100 Hz crossover, where LR4 suppression is strongest. ±15° ripple is under 0.7 dB.

See Chapter 11 (Crossovers) and Chapter 14 (DSP) for detail.

---

## Open items

- [ ] Purchase SB26STAC-C000-4 physical unit
- [ ] Caliper measurement: faceplate OD, BCD (88.5 from drawing — confirm), dome surround Ø, total depth, recess Ø, counterbore depth
- [ ] Confirm throat diameter (estimated 28mm — dome + surround)
- [ ] Print waveguide
- [ ] Test fit SB26STAC in waveguide
- [ ] Measure on-axis and off-axis response in waveguide
- [ ] Measure distortion at 1100 Hz (expected to pass comfortably)
- [ ] Confirm c-c spacing to 15W midrange is achievable at 140 mm

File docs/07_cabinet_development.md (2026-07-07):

# Chapter 7 - Cabinet Development

---

## Design history

The cabinet geometry was developed iteratively across the early concept versions.

| Width | Roundover | Notes |
|---|---|---|
| Initial concept | - | Active 3-way with push-push woofers |
| 280 mm | R20-R40 | Narrower baffle explored, R40 promising |
| 300 mm | R50 | 300/R50 selected as best compromise (DD-007) |
| 320 mm | R19 | Current v9 cabinet — width increased for 12SW magnet clearance |

---

## Current dimensions

| Parameter | Value |
|---|---|
| External width | 320 mm |
| External depth | 380 mm |
| External height | 1180 mm |
| Material | 22 mm birch plywood |
| Front edge roundovers | R19 (vertical edges) |
| Rear/other edges | R20-R30 or chamfers (TBD) |

---

## Cabinet width: 320 mm

The 320 mm wide front baffle is the current v9 cabinet width. Originally 300 mm
was selected (DD-007) as the best compromise, but the width was increased to
320 mm to provide adequate clearance for the opposed GRS 12SW-4HE magnets (only
~4 mm gap at 276 mm internal width with 300 mm external). The 320 mm width gives
276 mm + 2×9 mm = improved internal clearance.

The 320 mm width is the best compromise between:

- **Directivity:** A narrower baffle reduces baffle diffraction effects at high frequencies. 280 mm was investigated but showed only small additional benefits over 300 mm (the original DD-007 width).
- **Diffraction:** The R19 roundovers on the 320 mm baffle smooth diffraction more than was achievable on the narrower 280 mm version with practical roundover radii.
- **Mechanical fit:** 320 mm provides enough width for the waveguide and the woofer cutouts while leaving adequate material for the box sides and bracing.
- **Cabinet volume:** 320 mm provides more internal volume than 280 mm, easing the ~65 L bass chamber requirement (volume under the divider plate).
- **Visual proportion:** 320 mm is a reasonable proportion for a tall reference loudspeaker.

---

## R50 front edge roundovers

The R19 vertical front roundovers (revised from R50 in v9 — see DD-016 and
CHANGELOG) were selected from a comparison of R20, R30, R40, R50, and R70 radii in simplified diffraction simulation.

Larger roundovers produce smoother diffraction, reducing the diffraction ripple in the off-axis response and the predicted in-room response. R19 is a practical radius for the 320 mm wide cabinet using typical woodworking methods (router jig or router table).

The roundover applies to the vertical front edges only. The horizontal top and bottom edges may use smaller roundovers or chamfers depending on the mechanical construction.

---

## Driver placement

### Tweeter / waveguide

The waveguide is mounted at the top of the driver array on the front baffle. The tweeter dome center is approximately 140 mm above the midrange center.

Exact height from the cabinet top is to be determined from the final front baffle layout, with the waveguide centered as close to the top as practical while leaving adequate material above the cutout.

### Midrange

The ScanSpeak 18W/4424G00 is mounted directly below the waveguide. The center-to-center spacing to the tweeter is 165 mm (DD-016, physical minimum with these flanges).

The midrange operates in a dedicated sealed chamber (see Chapter 9: Volume calculations).

### Woofers

Two GRS 12SW-4HE woofers (12" high excursion) are side-mounted in a push-push
configuration, opposed at the same height on the two side panels (directly across
from each other — see Chapter 8). The current placement targets:

- Both woofer centers: approximately 520 mm from the cabinet bottom (nominal;
  same height on both sides)

This height is subject to revision based on:
- Internal bracing layout
- Mid chamber boundaries
- The coupling block between the opposed magnets (push-push symmetry)

---

## Material: 22 mm birch plywood

22 mm Baltic birch plywood is the primary structural material. It offers:

- Consistent density and stiffness compared with MDF
- Good screw retention for threaded inserts
- Manageable weight
- Better moisture resistance than MDF
- Suitability for CNC or hand cutting

The front baffle may use a double layer (44 mm) around the driver cutouts for driver mounting depth and rigidity, depending on the final design.

---

## Front baffle layout

The front baffle must accommodate:

- Waveguide cutout
- ScanSpeak 18W/4424G00 midrange cutout
- R19 vertical front edge roundovers
- 165 mm c-c spacing between waveguide and 18W centers (DD-016)
- Adequate wood remaining between cutouts and edges for structural integrity

The mechanical tightness of this layout is a known constraint (DD-011). The waveguide flange and midrange recess must be designed together.

---

## Internal layout

| Region | Contents |
|---|---|
| Upper section | Mid chamber (~11 L sealed, 18W/4424G00) |
| Main bass chamber | Bass volume (~65 L net, under divider plate) |
| Woofer positions | Side walls, push-push |
| Bracing | Shelf, window, vertical (see Chapter 10) |

---

## Open items

- Finalize exact external dimensions and tolerances
- Develop full 2D front baffle layout drawing
- Verify woofer frame dimensions fit side walls
- Determine front baffle thickness (single vs. double layer)
- Confirm waveguide flange dimensions once CAD is complete
- Generate OpenSCAD or STEP cabinet model

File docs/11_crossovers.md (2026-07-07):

# Chapter 11 - Crossovers

---

## Approach

The Mk3 Reference Loudspeaker uses an active DSP crossover. There is no passive crossover. Each driver has its own amplifier channel.

See Chapter 14 (DSP) for the full DSP implementation. This chapter covers the crossover topology and the acoustic targets.

---

## Crossover frequencies

| Crossover | Frequency | Slope | Drivers |
|---|---|---|---|
| Bass / midrange | 200 Hz | BW4 (24 dB/oct) | GRS woofers → ScanSpeak 18W/4424G00 |
| Midrange / tweeter | **1100 Hz** | LR4 (24 dB/oct) | ScanSpeak 18W/4424G00 → SB26STAC-C000-4 / waveguide |

---

## Linkwitz-Riley 4th-order (LR4) crossover

The LR4 crossover is the standard choice for active multi-way loudspeakers. Its properties:

- **-6 dB at the crossover frequency** for each driver
- **Summed acoustic response is flat** at all frequencies when drivers are in phase and perfectly aligned
- **4th order (24 dB/octave) slopes** provide fast rolloff, reducing out-of-band driver stress and lobing
- **In phase at the crossover frequency** - the two acoustic outputs are in phase (0°) at Fc, each at -6 dB, and sum flat **without** any polarity inversion. (This is the defining LR4 property. LR2, by contrast, is 180° out of phase at Fc and needs a polarity flip on one driver.)

DSP delay is used separately to align the drivers' physical **acoustic-centre
offsets** so the summation holds off-axis as well as on-axis — it is not
correcting a 180° crossover phase.

LR4 crossovers can be implemented as a cascade of two 2nd-order Butterworth filters, or directly as a 4th-order IIR filter in the DSP.

---

## Butterworth 4th-order (BW4) bass/mid crossover

The bass/mid crossover uses a 4th-order Butterworth (BW4) topology rather than
LR4. BW4 has a -3 dB point at the crossover frequency (vs -6 dB for LR4), which
fills the response dip that appeared at the woofer rolloff with LR4 slopes. The
asymmetric pairing (BW4 low-pass on woofer, BW4 high-pass on mid) was chosen
after simulation showed it produced a flatter summed response than LR4 at the
woofer/mid handoff (see `simulations/crossover_woofer_mid.py`).

---

## Bass / midrange: 200 Hz

The 200 Hz BW4 crossover was selected to:
- Relieve the ScanSpeak 18W/4424G00 of bass reproduction (below 200 Hz is handled by the woofers)
- Keep the GRS woofers within their optimal operating range
- Allow the 18W to reproduce the lower midrange (200-500 Hz) without excessive excursion
- Fill the response dip at the woofer rolloff that occurred with the previous 150 Hz LR4 crossover

**Woofer low-pass:** 200 Hz BW4
The woofers are rolled off at 200 Hz. Below 200 Hz the full bass SPL is produced by the GRS push-push system. The bass system also receives a high-pass filter at approximately 20 Hz to protect the woofers from infrasonic content.

**Midrange high-pass:** 200 Hz BW4
The 18W/4424G00 midrange is high-passed at 200 Hz. This removes bass loading from the midrange driver and the mid chamber.

**Phase alignment:** The acoustic centers of the woofers and the midrange are at different physical positions. DSP delay must be applied to align them at the crossover frequency.

---

## Midrange / tweeter: 1100 Hz

The 1100 Hz crossover was selected based on a systematic optimization sweep
(see `simulations/mk3_crossover_optimization.py`) that scored crossover
frequencies from 800 to 1600 Hz against five criteria: Fs margin, excursion
headroom, directivity match, vertical lobing, and system sum flatness.

### Optimization results

| Fc [Hz] | Fs margin | Excursion | DI mismatch | ±15° ripple | Score | Broadside |
|---|---|---|---|---|---|---|
| 1000 | 250 Hz | +6.4 dB | 4.3 dB | -0.6 dB | 6.9 | below |
| 1050 | 300 Hz | +7.2 dB | 4.5 dB | -0.6 dB | 7.7 | below |
| **1100** | **350 Hz** | **+8.1 dB** | **4.6 dB** | **-0.7 dB** | **8.1** | **below** |
| 1150 | 400 Hz | +8.8 dB | 4.9 dB | -0.7 dB | 8.2 | above |
| 1200 | 450 Hz | +9.6 dB | 5.1 dB | -0.8 dB | 8.2 | above |
| 1100 | 350 Hz | +10.3 dB | 5.3 dB | -0.9 dB | 8.1 | above |
| 1300 | 550 Hz | +11.0 dB | 5.5 dB | -1.0 dB | 8.1 | above |

**Optimal band: 1100-1200 Hz** (scores 8.1-8.2, statistically tied).

**Why 1100 Hz is chosen over 1200 Hz despite identical scores:**
- Below broadside null (1147 Hz for 150mm c-c) — the null is fully outside
  the active crossover band, not partially inside it
- Better DI match (4.6 vs 5.1 dB) — closer to 18W's near-omni region
- Fs margin of 350 Hz is already comfortable — additional margin has
  diminishing returns (the sigmoid scoring reflects this)

The crossover could be raised to 1150-1200 Hz with negligible penalty if
measurement shows the 18W has cone breakup or directivity issues at 1100 Hz.

### Selection rationale

- **Fs margin:** 350 Hz above the 750 Hz resonance — comfortable, no distortion test gate required.
- **Directivity match:** At 1100 Hz the 18W midrange is closer to omni, giving a smaller DI step (4.6 dB mismatch).
- **Vertical lobing:** The broadside null for 150mm c-c is at 1147 Hz — just above the 1100 Hz crossover. The LR4 rolloff suppresses the null almost entirely. At ±15° the ripple is under 0.7 dB.
- **Excursion headroom:** The SB26STAC's 0.6mm Xmax gives +8.1 dB more max SPL at 1100 Hz.

**Midrange low-pass:** 1100 Hz LR4
The 18W is rolled off above 1100 Hz.

**Tweeter high-pass:** 1100 Hz LR4
The SB26STAC in the waveguide is high-passed at 1100 Hz.

**Phase alignment:** The acoustic centers of the midrange and the tweeter/waveguide are at different positions. DSP delay will be used to align them. The waveguide also adds physical depth to the tweeter's acoustic center.

---

## Vertical lobing at the mid/tweeter crossover

The two-driver interference pattern at the mid/tweeter crossover creates lobing in the vertical plane. The lobing frequency and severity depend on:

- The center-to-center (c-c) spacing between the midrange and tweeter
- The crossover frequency
- The crossover slope

For two drivers with a c-c spacing of d, the first lobe null occurs at approximately:

```
f_null = c / (2 × d × sin(θ))
```

where c is the speed of sound (~344 m/s), d is the c-c spacing in meters, and θ is the off-axis angle.

For d = 140 mm and θ = 90° (broadside null):
```
f_null = 344 / (2 × 0.14) ≈ 1229 Hz
```

For d = 150 mm (practical minimum before 18W frames touch):
```
f_null = 344 / (2 × 0.15) ≈ 1147 Hz
```

At the 1100 Hz crossover, the broadside null (1147 Hz for 150mm c-c) sits **just above** the crossover frequency. The LR4 rolloff means the tweeter is already -6 dB at 1100 Hz and dropping fast, so the null at 1147 Hz is strongly suppressed. At ±15° the ripple is under 0.7 dB.

Shorter c-c spacing reduces lobing severity and pushes the null higher. Increasing the crossover frequency with the same c-c spacing worsens the lobing.

---

## DSP implementation

See Chapter 14 (DSP) for the filter coefficients, delay values, and EQ.

---

## Open items

- Measure SB26STAC in waveguide response/distortion at 1100 Hz (expected to pass comfortably — no Fs-margin gate)
- Measure acoustic centers of all three driver systems in the final cabinet
- Calculate and apply DSP delay values
- Verify crossover summation in measurement (flat on-axis, smooth off-axis)
- Adjust crossover frequency if distortion measurement requires it

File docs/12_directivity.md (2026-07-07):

# Chapter 12 - Directivity

---

## What is directivity?

Directivity describes how a loudspeaker radiates sound in different directions. A loudspeaker with ideal directivity control radiates smoothly controlled patterns at all frequencies, with the pattern narrowing gradually with frequency as expected from the geometry.

Poor directivity produces:
- Sudden changes in the off-axis pattern at crossover frequencies ("directivity step")
- Narrow vertical lobes from c-c spacing at crossover
- Diffraction artifacts from cabinet edges
- Irregular reflections in the listening room

---

## Directivity Index (DI)

The Directivity Index is the difference in dB between the on-axis response and the sound power response (the integrated energy radiated in all directions).

A smooth, monotonically rising DI is a sign of well-controlled directivity. It indicates:
- The loudspeaker becomes gradually more directional at higher frequencies (as expected from increasing source size relative to wavelength)
- There are no abrupt directivity transitions

Irregularities in the DI (dips, steps, irregularities) indicate directivity problems at those frequencies.

---

## Sources of directivity problems

### Crossover directivity mismatch

At the crossover frequency, two drivers of different sizes transition between each other. If their off-axis responses do not match at the crossover frequency, the combined off-axis response will show a step or dip.

For the mid/tweeter crossover at 1100 Hz:
- The ScanSpeak 18W/4424G00 midrange at 1100 Hz radiates over a moderate angle (the ~144 mm cone diameter is beginning to narrow the pattern)
- The SB Acoustics SB26STAC-C000-4 is a conventional dome with no built-in horn, so the custom waveguide provides all of the directivity control
- Without the waveguide, a directivity step would be present at the crossover frequency

The custom SB26STAC waveguide (`cad/waveguide.scad`) is designed to provide directivity control matching the 18W/4424G00 midrange at the crossover frequency. Because the SB26STAC is a conventional dome (no built-in horn), this is a non-horn-loaded waveguide.

### Vertical lobing

Two vertically separated drivers produce an interference pattern in the vertical plane at frequencies where their separation is comparable to the wavelength. This appears as a lobe structure in the vertical polar plot.

The 140 mm c-c spacing and 1100 Hz crossover were selected together to minimize the lobing impact within the ±15° listening window. See Chapter 11 for quantitative analysis.

### Cabinet diffraction

The edges of the cabinet cause sound waves to diffract, adding a second source of radiation at the edge. This produces ripple in both the on-axis and off-axis responses, particularly in the 500-5000 Hz range depending on cabinet dimensions.

The R50 front edge roundovers minimize diffraction by presenting a smooth curve rather than a sharp edge to the propagating wavefront. Larger roundovers produce smoother diffraction.

### Driver beaming

At high frequencies, individual drivers become increasingly directional because their radiating diameter becomes large relative to the wavelength. This is called beaming.

The ScanSpeak 18W/4424G00 begins to beam above approximately 1500-2000 Hz in free-field. The 1100 Hz crossover is designed to transition to the tweeter/waveguide before significant beaming occurs.

---

## Design response

| Problem | Solution | Status |
|---|---|---|
| Mid/tweeter directivity mismatch | Custom SB26STAC waveguide | In development |
| Vertical lobing | 140 mm c-c + 1100 Hz crossover | Simulated |
| Cabinet diffraction | R50 front roundovers | Selected |
| Midrange beaming | Cross at 1100 Hz | Simulated |

---

## Simulation results summary

The simplified simulations explored multiple combinations of:
- Waveguide size (~212 to ~240 mm mouth)
- Crossover frequency (1100 to 1600 Hz)
- C-c spacing (140 to 157 mm)

Key finding: **lower crossover frequency and shorter c-c spacing produced more consistent benefit than larger waveguide mouth diameter.**

The SB26STAC waveguide with 1100 Hz and 140 mm c-c is the current best candidate. This must be verified with real measurements of the physical prototype.

---

## Target directivity behavior

| Frequency range | Expected pattern |
|---|---|
| Below 200 Hz | Omnidirectional (woofers, long wavelengths) |
| 200 Hz - 1 kHz | Gradually narrowing (midrange, baffle loading) |
| 1 kHz - 3 kHz | Controlled by custom waveguide |
| 3 kHz - 20 kHz | Gradually narrowing (tweeter in waveguide) |

The horizontal polar pattern should be smooth and symmetrical. The vertical polar pattern should be usable over at least ±15° without major lobing artifacts in the crossover region.

---

## Measurement requirements

To fully characterize the directivity:

- Horizontal: 0°, 10°, 20°, 30°, 40°, 50°, 60° minimum (70°, 80°, 90° extended)
- Vertical: ±10°, ±15°, ±20°, ±30°

These measurements feed into VituixCAD to compute the full spinorama and DI curve.

See Chapter 15 (Measurements) for the full measurement plan.

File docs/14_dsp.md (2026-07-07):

# Chapter 14 - DSP

---

## Overview

The Mk3 Reference Loudspeaker is an active design. All crossovers, delay alignment, and EQ are implemented in digital signal processing. There is no passive crossover.

Each driver has its own amplifier channel:
- 2 × woofer channels (or 1 if wired in series)
- 1 × midrange channel
- 1 × tweeter channel

Minimum: 3 channels of amplification and DSP. Maximum (with separate woofer channels): 4 channels.

---

## DSP platform options

The DSP platform has not been finalized. Candidate approaches:

| Platform | Notes |
|---|---|
| MiniDSP 2×4 HD | Common, affordable, good ecosystem, limited channels |
| MiniDSP 4×10 HD | More channels, Dirac Live capable |
| Hypex FusionAmp FA123 | Integrated 3-channel amp + DSP in one module |
| Hypex FusionAmp FA253 | Higher power 3-channel |
| ADAU1452-based custom | Most flexible, requires firmware development |
| Separate DAC + external DSP | Maximum flexibility, most complex |

For the prototype phase, a MiniDSP or Hypex FusionAmp is the likely first implementation. The ADAU1452 custom platform is a longer-term option for a more integrated final version (see Chapter 17).

---

## Signal chain

```
Source → DSP input → [Bass LP filter] → Bass amplifier → Woofers (series)
                   → [Mid HP filter]  → [Mid LP filter] → Mid amplifier → Midrange
                   → [Tweeter HP filter] → [Tweeter EQ] → Tweeter amplifier → SB26STAC / waveguide
```

---

## Crossover filters

### Bass low-pass

| Filter | Value |
|---|---|
| Type | Butterworth 4th order (BW4) |
| Frequency | 200 Hz |
| Slope | 24 dB/oct |
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

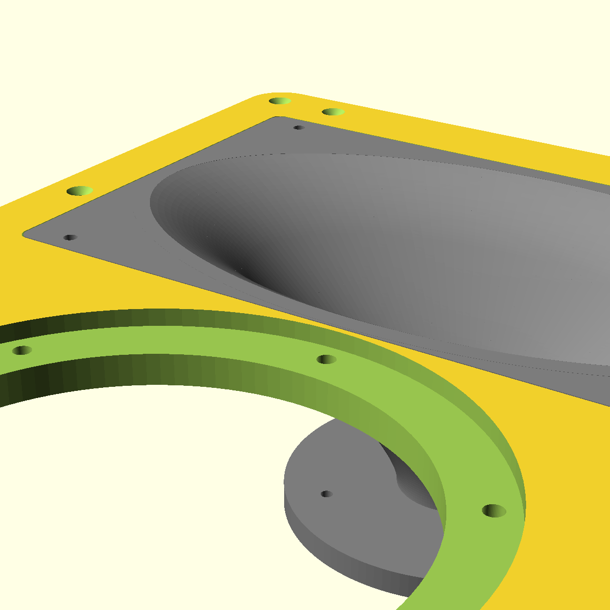
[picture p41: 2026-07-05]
assets/renders/baffel_insert_fit.png

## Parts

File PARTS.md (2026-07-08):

# Parts — Mk3 Reference Loudspeaker

All quantities and prices are **per pair** unless noted otherwise.
Prices are indicative (sourced June 2026); verify before ordering.

---

## Drivers

| Part | Qty/pair | Unit price | Supplier | Notes |
|---|---|---|---|---|
| GRS 12SW-4HE (12" woofer) | 4 | ~€75 | Parts-Express | 2 per enclosure, push-push. Fs 22 Hz, Qts 0.43, Vas 80.4 L, Xmax 12.5 mm (Klippel), Sd 504 cm², 250 W |
| ScanSpeak 18W/4424G00 (midrange) | 2 | ~€95 | Scan-Speak / Hifi-Skabet | v9: replaces 15W/4434G00 (DD-016). Fs 49 Hz, Qts 0.38, Vas 24.1 L, Sd 137 cm², 91 dB, 4 Ω. Parametric model `cad/midrange.scad` |
| SB Acoustics SB26STAC-C000-4 (tweeter) | 2 | ~€35 | SB Acoustics / Parts-Express | Custom waveguide, no horn loading |

## Waveguide

| Part | Qty/pair | Notes |
|---|---|---|
| SB26STAC custom waveguide | 2 | 3D print from `cad/waveguide.scad`. BCD 88.5 mm, throat 28 mm. No STEP file from SB Acoustics — caliper-verify all dimensions. |

## Cabinet

| Part | Notes |
|---|---|
| 22 mm birch plywood | ~3 sheets per cabinet (verify cut list from CAD). Standard 1220 × 2440 mm sheet. |
| PVA woodworking glue | Titebond III or equivalent |
| Wood screws + threaded inserts | For driver mounting |
| Gasket tape (closed-cell foam, 5 mm) | All driver openings |
| Damping felt/foam | Mid chamber: fully lined. Bass chamber: 50 mm rear/top/sides. |
| Terminal cup or amplifier plate cutout | Depends on DSP/amp selection |

Approximate external dimensions (v9): **300 × 420 × 1180 mm**, 22 mm walls, R19 front roundovers (see CHANGELOG v9 for why 300 mm / R50 were revised).

### Alternative material: massiv fyr bordplade (25 mm)

Jem & Fix sælger massive fyrrebordplader i 25 × 620 × 2420 mm som en potentiel kabinetalternativ.
Produkt: [Massiv bordplade i fyr — 25 mm × 62 × 242 cm](https://www.jemogfix.dk/massiv-bordplade-i-fyr-25-mm-x-62-x-242-cm/4137/9048870/)

**Implikationer ved 25 mm vs. 22 mm:**
- Indvendige mål: 250 × 370 × 1130 mm (vs. 256 × 376 × 1136 mm med 22 mm ply) — ca. 5% mindre volumen
- `cabinet.scad` skal opdateres: `wall = 25;`
- Massiv fyr er tungere og densere end krydsfinér — potentielt bedre kabinetttræ masse, men blødere overflade (dents lettere)
- Kræver grundning/oliering på alle sider inden samling (som med ply)

**Skæreliste — 5 stk. 620 × 2420 mm bordplader — ET PAR (venstre + højre):**

| Plade | Snit (bredde) | Stykke | Mål (mm) | Position på plade |
|---|---|---|---|---|
| Plade 1 | 420 mm rip | Side L (V) | 420 × 1180 | 0–1180 mm |
| Plade 1 | 420 mm rip | Side L (H) | 420 × 1180 | 1180–2360 mm |
| Plade 1 | 200 mm rip | Reserve | — | hele længden |
| Plade 2 | 420 mm rip | Side R (V) | 420 × 1180 | 0–1180 mm |
| Plade 2 | 420 mm rip | Side R (H) | 420 × 1180 | 1180–2360 mm |
| Plade 2 | 200 mm rip | Reserve | — | hele længden |
| Plade 3 | 300 mm rip | Front (V) | 300 × 1180 | 0–1180 mm |
| Plade 3 | 300 mm rip | Front (H) | 300 × 1180 | 1180–2360 mm |
| Plade 3 | 320 mm rip | Divider (V) | 250 × 370 | 0–370 mm |
| Plade 3 | 320 mm rip | Hylde 1–3 (V) | 250 × 370 | 370–1480 mm |
| Plade 4 | 300 mm rip | Bagplade (V) | 300 × 1180 | 0–1180 mm |
| Plade 4 | 300 mm rip | Bagplade (H) | 300 × 1180 | 1180–2360 mm |
| Plade 4 | 320 mm rip | Divider (H) | 250 × 370 | 0–370 mm |
| Plade 4 | 320 mm rip | Hylde 1–3 (H) | 250 × 370 | 370–1480 mm |
| Plade 5 | 300 mm rip | Toplåg (V) | 300 × 420 | 0–420 mm |
| Plade 5 | 300 mm rip | Bundplade (V) | 300 × 420 | 420–840 mm |
| Plade 5 | 300 mm rip | Toplåg (H) | 300 × 420 | 840–1260 mm |
| Plade 5 | 300 mm rip | Bundplade (H) | 300 × 420 | 1260–1680 mm |
| Plade 5 | 320 mm rip | Reserve | — | hele længden |

*Divider og hylde braces skæres til 270 mm fra de 300 mm strips (30 mm trim). Plade 5 efterlader ca. 0.9 m² reservetræ på strip A + hele strip B — velegnet til højttalerstativ, rondeller til portkanaler, mv.*

## Electronics / DSP

**MiniDSP 4×10 HD** selected as DSP platform for initial prototyping. USB/optical in, 10 outputs, well-documented with REW export. Pre-built XML config available (see DSP Filter Plan below).

## DSP Filter Plan (v9)

| Driver path | Filters |
|---|---|
| Woofer (×2) | Subsonic HP ~18 Hz LR2, Linkwitz Transform (39.0→28 Hz, Q 0.76→0.707), LP 200 Hz BW4, gain 0 dB |
| Midrange | HP 200 Hz BW4, LP 1100 Hz LR4, gain -4.0 dB |
| Tweeter | HP 1100 Hz LR4, gain -9.0 dB |

**Note:** 1100 Hz crossover frequency is **unconfirmed** — depends on SB26STAC distortion measurement in the waveguide. If distortion is too high, raise to 1300-1500 Hz. Pre-built MiniDSP XML config: `dsp-configs/mk3-v9-200-1100-bw4-lr4.xml`.

## Open Items

- [ ] Caliper-verify SB26STAC-C000-4 dimensions → update `cad/waveguide.scad`
- [ ] Caliper-verify 18W/4424G00 flange/cutout/depth → update `cad/midrange.scad`
- [ ] Print SB26STAC waveguide prototype → fit-check against SB26STAC and 18W/4424G00
- [ ] Measure SB26STAC distortion at 1100 Hz → confirm or adjust crossover
- [ ] Re-validate 1100 Hz LR4 for the 18 cm midrange cone (directivity) and 165 mm c-c (vertical lobing)
- [ ] Confirm actual c-c spacing (165 mm computed minimum; `cad/cabinet.scad` echoes it from part dimensions)
- [ ] Confirm woofer cutout diameter (284 mm per GRS 12SW-4HE datasheet) and basket depth clearance (~136 mm total) before cutting side panels
- [ ] Verify opposed 12SW magnet gap (~48 mm computed from datasheet depth at 320 mm width) and coupling block length before cutting panels
- [ ] Finalize cut list from CAD model before ordering sheet material

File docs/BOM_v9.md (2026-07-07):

# mk3 v9 — Bill of Materials (per speaker, qty 2 total)

Approximate prices in EUR (incl. VAT). Updated July 7, 2026.

## Drivers

| Driver | Qty | Unit Price | Total | Source |
|---|:---:|:---:|:-----:|---|
| GRS 12SW-4HE 12" high-excursion woofer | 2 | ~€30 | €60 | [Parts Express 292-824](https://www.parts-express.com/GRS-12SW-4HE-12-Paper-Cone-Rubber-Surround-High-Excursion-Subwoofer-4-Ohm-292-824) |
| ScanSpeak 18W/4424G00 7" midwoofer | 1 | ~€68 | €68 | [SoundImports](https://www.soundimports.eu/en/scan-speak-18w-4424g00.html) / [Willys-Hifi £58.41](https://willys-hifi.com/products/scanspeak-18w-4424g00-bass-midrange) |
| SB Acoustics SB26STAC-C000-4 1" tweeter | 1 | ~€48 | €48 | [hifisound.de €47.45](https://www.hifisound.de/Do-it-yourself-Products/SB-Acoustics-SB26STAC-C000-4-Tweeter.html) / [Madisound ~$52](https://www.madisoundspeakerstore.com/soft-dome-tweeters-sb-acoustics/sb-acoustics-sb26stac-c000-4-tweeter-4-ohm/) |
| **Drivers total** | **4** | | **€176** | |

## Cabinet Materials

| Item | Qty | Unit Price | Total | Notes |
|---|:---:|:---:|:-----:|---|
| 25mm MDF (1.22×2.44m sheet) | 1 | ~€35 | €35 | HDF or BB ply preferred if available |
| 18mm MDF (bracing) | 0.5 sheet | ~€20 | €10 | Internal braces and driver mounting rings |
| T-nuts M6 (driver mounting) | 20 | ~€0.20 | €4 | 8 per woofer + 4 per mid + 4 per tweeter |
| Bolts M6×25mm (driver mounting) | 20 | ~€0.15 | €3 | |
| Wood screws (various) | 1 box | ~€5 | €5 | For bracing and assembly |
| Wood glue (e.g. Titebond II) | 1L | ~€12 | €12 | |
| **Cabinet total** | | | **€69** | |

## Damping & Acoustics

| Item | Qty | Unit Price | Total | Notes |
|---|:---:|:---:|:-----:|---|
| Acoustic foam / polyester damping | 1 roll | ~€15 | €15 | Internal cabinet lining, ~30mm thick |
| Acoustic damping putty | 2 sheets | ~€5 | €10 | For panel constrained-layer damping |
| Self-adhesive bitumen pads | 1 pack | ~€10 | €10 | Panel damping on large surfaces |
| Port tube (if ported) | 2 | ~€3 | €6 | 2x flared ports for each woofer chamber |
| **Damping total** | | | **€41** | |

## Crossover / DSP (active, MiniDSP-based)

| Item | Qty | Unit Price | Total | Notes |
|---|:---:|:---:|:-----:|---|
| MiniDSP 4×10 HD (already in system) | 0 | €0 | €0 | Existing, no incremental cost |
| Speaker wire, 2.5mm² (internal wiring) | 5m | ~€3/m | €15 | Per speaker |
| Binding posts (gold-plated, 4 pairs) | 4 pairs | ~€5 | €20 | Woofer pair, mid, tweeter, sub |
| Speakon connectors (if active) | 0 | €0 | €0 | Only if using pro audio connectors |
| **Active crossover total** | | | **€35** | |

Passive crossover (if building passive version as backup):

| Item | Qty | Unit Price | Total | Notes |
|---|:---:|:---:|:-----:|---|
| Air-core inductor (woofer path, 3-5 mH) | 1 | ~€15 | €15 | |
| Air-core inductor (mid path, 1-2 mH) | 1 | ~€10 | €10 | |
| Air-core inductor (tweeter path, 0.5 mH) | 1 | ~€8 | €8 | |
| MKP poly caps (woofer path, 150-220 µF) | 1 | ~€12 | €12 | |
| MKP poly caps (mid path, 47-68 µF) | 2 | ~€10 | €20 | |
| MKP poly caps (tweeter path, 10-15 µF) | 1 | ~€8 | €8 | |
| Wirewound resistors (L-pad) | 4 | ~€3 | €12 | |
| PCB / perfboard + solder + binding | 1 | ~€10 | €10 | |
| **Passive crossover total (optional)** | | | **€95** | |

## Waveguide (3D printed)

| Item | Qty | Unit Price | Total | Notes |
|---|:---:|:---:|:-----:|---|
| PLA/PETG filament (1kg spool) | 1 | ~€25 | €25 | Enough for both waveguides + test prints |
| Fine sandpaper + finishing | 1 set | ~€10 | €10 | Post-print surface smoothing |
| **Waveguide total** | | | **€35** | |

## Finishing

| Item | Qty | Unit Price | Total | Notes |
|---|:---:|:---:|:-----:|---|
| Primer + paint / veneer | 1 kit | ~€40 | €40 | Per speaker |
| **Finishing total** | | | **€40** | |

---

## Summary

| Category | Cost (EUR, per speaker) | Cost (EUR, for pair) |
|---|:---:|:---:|
| Drivers | €176 | €352 |
| Cabinet materials | €69 | €138 |
| Damping & acoustics | €41 | €82 |
| Active wiring + connectors | €35 | €70 |
| Waveguide (3D printed) | €35 | €70 |
| Finishing | €40 | €80 |
| **Active subtotal** | **€396** | **€792** |
| Optional passive crossover | €95 | €190 |
| **Total with passive backup** | **€491** | **€982** |

## Notes

- **Active system recommended.** All v9 simulation work assumes MiniDSP 4×10 HD with DSP crossovers, PEQ, gain, and delay. Passive crossovers add complexity, cost, and insertion loss for no benefit when the MiniDSP is already in the signal chain.
- **GRS 12SW-4HE** is the budget champion — $28-32 per driver, dual push-push gives +6 dB sensitivity over single, yielding ~93 dB/2.83V effective. Two per cabinet (four per pair).
- **18W/4424G00 replacement of 15W/4434G00** was cost-neutral: the 18W is ~€68 vs the 15W at ~€55, but the 18W offers 91 dB sensitivity vs 89 dB for the 15W — a significant system-level improvement that needed less tweeter padding.
- **SB26STAC-C000-4** replaced H2606 at a fraction of the cost: €48 vs ~€120+ for the H2606, with comparable or better performance above 1100 Hz.
- **Total driver savings vs Mk2:** ~€150+ per pair by switching from H2606 to SB26STAC.
- Prices are approximate and vary by distributor, region, and current exchange rates. Danish prices (incl. 25% VAT) will be higher than the EU-ex-VAT or US prices shown here — add ~20-25% for Danish purchase.

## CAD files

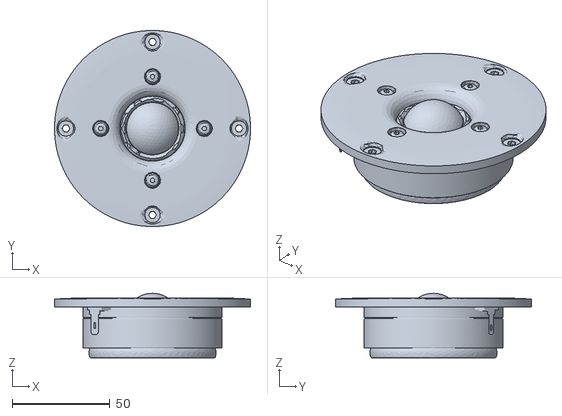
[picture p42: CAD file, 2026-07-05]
assets/cad/SB26STAC-C000-4_ref.stl
100.2 x 100.2 x 33.0

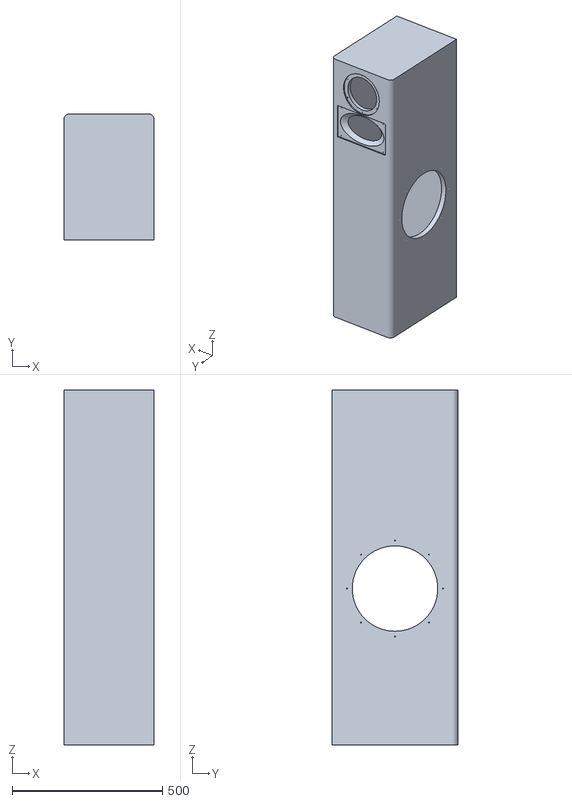
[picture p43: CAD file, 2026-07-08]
cad/exports/cabinet.stl
300.0 x 420.0 x 1180.0

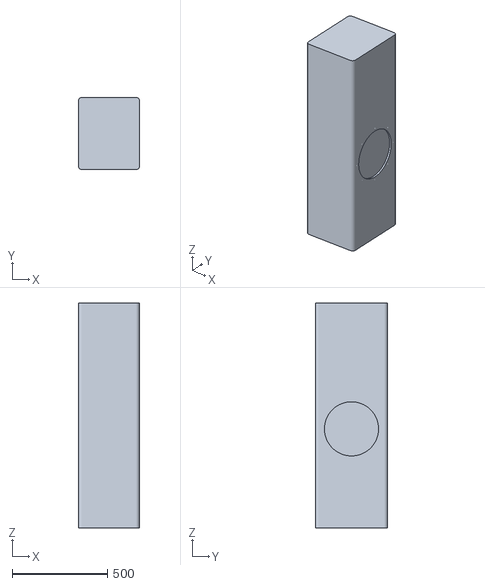
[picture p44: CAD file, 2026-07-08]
cad/exports/cabinet_v2.stl
320.0 x 380.0 x 1180.0

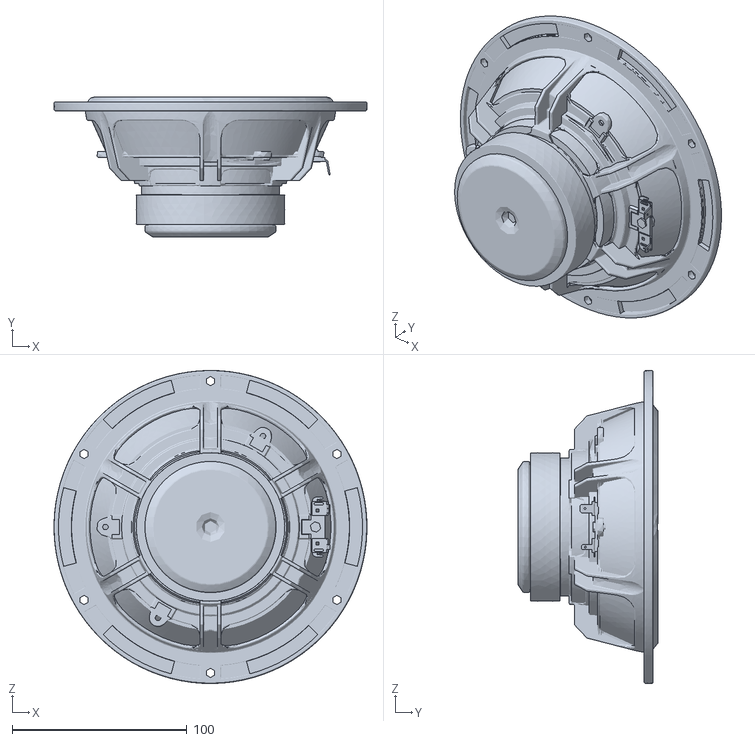
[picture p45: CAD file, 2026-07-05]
assets/cad/18W-4424G00_ref.stl
179.1 x 80.1 x 179.2

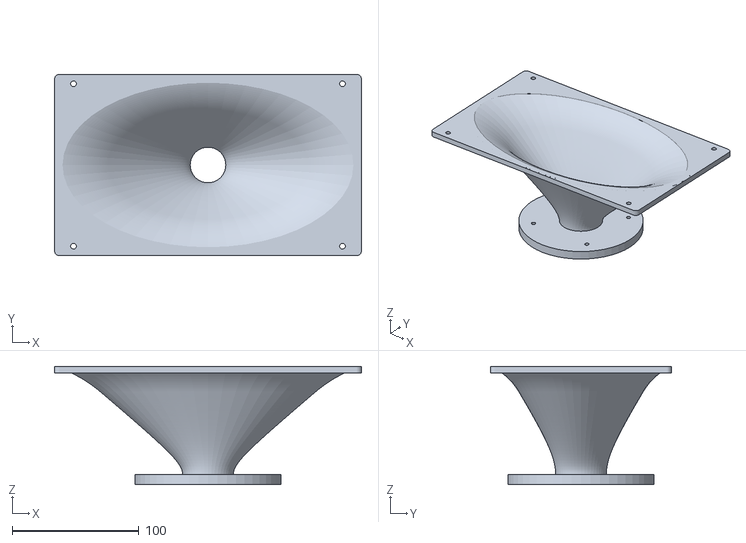
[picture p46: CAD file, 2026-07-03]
cad/exports/waveguide.stl
242.0 x 143.0 x 93.0

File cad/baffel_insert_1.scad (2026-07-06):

// ============================================================
//  MODULAER BAFFEL-INSERT v2  (3D-print)
//  - 18W/4424G00 mellemtone, PLANFRAESET (flush rebate)
//  - WG212 waveguide (SB26STAC) i FLUSH RUM + elliptisk kropshul
//  - Diskanten sidder BAG waveguiden (paa dens bagplade)
//
//  KOBLER TIL waveguide.scad via 'use' - alle WG-maal hentes fra
//  dens egne funktioner (flange, krop, skruemoenster). Hold begge
//  filer i samme mappe.
//
//  Front = +Z, bagside = 0.  PRINT: bagside paa pladen, front opad.
// ============================================================

use <waveguide.scad>
use <midrange.scad>
use <SB26STAC-C000-4.scad>

/* [Visning] */
vis = "baffel"; // [baffel:Printklar insert, fit:Med rigtige enheder (GUI-preview), snit:Lodret halvsnit]

/* [Plade] */
baffel_b   = 285;   // Bredde (rummer WG-flangens 242 mm)
baffel_h   = 380;   // Hoejde
baffel_tyk = 15;    // Pladetykkelse
hjoerne_r  = 14;    // Hjoerneradius

/* [Placering] */
enhed_cc      = 164; // Center-center mellemtone <-> waveguide
gruppe_offset = 9;   // Loft gruppen for lige marginer

/* [Mellemtone 18W/4424G00 - KOTEDE maal] */
mid_udskaering   = 144.30;
mid_flange_dia   = 179.20;
mid_flange_tyk   = 5.20;
mid_bolt_cirkel  = 167.0;
mid_bolt_antal   = 6;
mid_bolt_offset  = 30;
mid_bolt_hul     = 5.50;
mid_udsk_clear   = 0.6;
mid_flange_clear = 0.6;
mid_rebate_ekstra= 0.2;

/* [Waveguide WG212 - hentet fra waveguide.scad, kun spillerum her] */
wg_flange_clear = 0.4;   // Sidespillerum paa fals (pr. side)
wg_pocket_ekstra= 0.3;   // Ekstra falsdybde
wg_body_clear   = 1.5;   // Spillerum paa kropshul (radius)
wg_baf_hul      = 5.6;   // Baflens skruehul til WG (M4 heat-set insert)

/* [Kabinet-montering - undersaenkede skruer i kanten] */
kant_inset   = 12;
kant_v_antal = 4;
kant_h_antal = 2;
ks_hul       = 4.50;
ks_hoved     = 9.0;
ks_dybde     = 2.5;

/* [Afstivning bagside] */
ribber       = true;
rib_tyk      = 4;
rib_hoejde   = 8;
rib_ramme_inset = 8;

/* [Render] */
$fn = 120;
eps = 0.05;

// --- afledte positioner ---
mid_cy = -enhed_cc/2 + gruppe_offset;
wg_cy  =  enhed_cc/2 + gruppe_offset;

// --- WG-maal hentet fra waveguide.scad ---
WG_FLW = wg_flange_w_fn();
WG_FLH = wg_flange_h_fn();
WG_FLR = wg_flange_r_fn();
WG_FLT = wg_flange_t_fn();
WG_FLOOR_Z = wg_front_z() - WG_FLT;
WG_BRX = wg_outer_rx(WG_FLOOR_Z);
WG_BRY = wg_outer_ry(WG_FLOOR_Z);
WG_SX  = wg_baf_bcd_x_fn()/2;
WG_SY  = wg_baf_bcd_y_fn()/2;

// ------------------------------------------------------------
module rrect(w,h,r) { offset(r=r) offset(delta=-r) square([w,h], center=true); }
module plade() { linear_extrude(baffel_tyk) rrect(baffel_b, baffel_h, hjoerne_r); }

module ribber_bagside() {
    linear_extrude(rib_hoejde) {
        difference() {
            rrect(baffel_b-2*rib_ramme_inset, baffel_h-2*rib_ramme_inset, max(1,hjoerne_r-rib_ramme_inset));
            rrect(baffel_b-2*rib_ramme_inset-2*rib_tyk, baffel_h-2*rib_ramme_inset-2*rib_tyk, max(1,hjoerne_r-rib_ramme_inset));
        }
        translate([-rib_tyk/2, -baffel_h/2+rib_ramme_inset]) square([rib_tyk, baffel_h-2*rib_ramme_inset]);
        translate([-baffel_b/2+rib_ramme_inset, gruppe_offset-rib_tyk/2]) square([baffel_b-2*rib_ramme_inset, rib_tyk]);
    }
}

// ------------------------------------------------------------
module boltring(cirkel, antal, off_a) {
    for (i=[0:antal-1]) rotate([0,0,off_a+i*360/antal]) translate([cirkel/2,0,0]) children();
}

module mid_neg() {
    translate([0, mid_cy, 0]) {
        translate([0,0,-eps]) cylinder(d=mid_udskaering+2*mid_udsk_clear, h=baffel_tyk+2*eps);
        translate([0,0, baffel_tyk-(mid_flange_tyk+mid_rebate_ekstra)])
            cylinder(d=mid_flange_dia+2*mid_flange_clear, h=mid_flange_tyk+mid_rebate_ekstra+eps);
        boltring(mid_bolt_cirkel, mid_bolt_antal, mid_bolt_offset)
            translate([0,0,-eps]) cylinder(d=mid_bolt_hul, h=baffel_tyk+2*eps);
    }
}

module wg_neg() {
    translate([0, wg_cy, 0]) {
        translate([0,0, baffel_tyk-(WG_FLT+wg_pocket_ekstra)])
            linear_extrude(WG_FLT+wg_pocket_ekstra+eps)
                rrect(WG_FLW+2*wg_flange_clear, WG_FLH+2*wg_flange_clear, WG_FLR);
        translate([0,0,-eps])
            linear_extrude(baffel_tyk+2*eps)
                scale([WG_BRX+wg_body_clear, WG_BRY+wg_body_clear]) circle(r=1);
        for (sx=[-1,1], sy=[-1,1])
            translate([sx*WG_SX, sy*WG_SY, -eps]) cylinder(d=wg_baf_hul, h=baffel_tyk+2*eps);
    }
}

module kant_skrue(x,y) {
    translate([x,y,-eps]) cylinder(d=ks_hul, h=baffel_tyk+2*eps);
    translate([x,y,baffel_tyk-ks_dybde]) cylinder(d1=ks_hul, d2=ks_hoved, h=ks_dybde+eps);
}
module kant_neg() {
    xv=baffel_b/2-kant_inset; yh=baffel_h/2-kant_inset;
    for (s=[-1,1], i=[0:kant_v_antal-1]) kant_skrue(s*xv, -yh + i*(2*yh)/(kant_v_antal-1));
    for (s=[-1,1], i=[0:kant_h_antal-1]) {
        x = (kant_h_antal==1)?0:-(xv-25)+i*2*(xv-25)/(kant_h_antal-1);
        kant_skrue(x, s*yh);
    }
}

// ------------------------------------------------------------
module baffel() {
    difference() {
        union() { plade(); if (ribber) ribber_bagside(); }
        mid_neg();
        wg_neg();
        kant_neg();
    }
}

// ------------------------------------------------------------
mid_ref_front = 80.1;
module fit() {
    baffel();
    // 18W/4424G00 midrange — real parametric model, flange front at z=0, body toward -z
    // No rotation needed: insert front is +Z, driver z-axis aligns directly
    color("dimgray")
        translate([0, mid_cy, baffel_tyk])
            midrange_driver();
    // WG212 waveguide — already imported via use <waveguide.scad>
    color("gray")
        translate([0, wg_cy, baffel_tyk - wg_front_z()]) waveguide();
    // SB26STAC-C000-4 tweeter — real parametric model, seated behind waveguide
    color("silver")
        translate([0, wg_cy, baffel_tyk - wg_front_z() + wg_back_z() + 4])
            diskant();
}

// ------------------------------------------------------------
if (vis=="baffel") baffel();
else if (vis=="fit") fit();
else if (vis=="snit")
    difference(){ baffel(); translate([-baffel_b,0,-baffel_tyk]) cube([2*baffel_b, baffel_b, 3*baffel_tyk]); }

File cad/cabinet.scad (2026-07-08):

// =====================================================================
// Mk3 Reference Loudspeaker - cabinet (parametric, simulation-stage)
// =====================================================================
//
// v9 layout: 300 x 420 x 1180 mm, 22 mm birch ply, rounded front vertical
// edges, side-mounted push-push GRS 12SW-4HE woofers opposed at the same
// height. MIDRANGE (ScanSpeak 18W/4424G00) sits at the TOP of the front
// baffle with the sealed mid chamber behind it; the WAVEGUIDE sits BELOW
// the midrange, and the full-width tilted divider plate runs between them
// (mid chamber above, bass volume below — the waveguide body hangs in the
// bass volume; its bore is sealed by the tweeter and flange gasket).
//
// All driver dimensions come from official datasheets:
//   - GRS 12SW-4HE:        assets/datasheets/GRS-12SW-4HE.md
//   - ScanSpeak 18W/4424G00: cad/midrange.scad exports (18W-4424G00.pdf)
//   - SB26STAC + waveguide:  cad/waveguide.scad exports
// Anything that is an estimate rather than a datasheet value is marked
// ESTIMATE and must be caliper-verified before any panel is cut.
//
// The model computes its own volumes and mechanical clearances: open the
// console (or run openscad on the file) and read the ECHO block — bass and
// mid chamber volume in litres, predicted sealed Qtc/Fc, magnet gap,
// divider clearances, screw lands. Change any parameter and the numbers
// update automatically. WARNINGs are printed when something collides or
// misses its target.
//
// This is a DESIGN-CANDIDATE model for visualisation and dimension
// checking, NOT a cut list. See docs/07_cabinet_development.md and
// docs/09_volume_calculations.md.
//
// Axes: X = width, Y = depth (front baffle at +Y), Z = height (0 at floor).
// Units: millimetres.   Render: `openscad -o cabinet.stl cabinet.scad`
// ---------------------------------------------------------------------

// Pull in the waveguide and midrange models + their exported dimension
// functions (only modules/functions are imported; nothing renders unless
// the show_* flags are set).
use <waveguide.scad>
use <midrange.scad>
use <GRS-12SW-4HE.scad>
use <SB26STAC-C000-4.scad>

// ---- External shell -------------------------------------------------
W       = 300;   // external width  [mm] (250 internal pine / 256 internal ply)
D       = 420;   // external depth  [mm] (Qtc=0.70 with 25mm pine walls)
H       = 1180;  // external height [mm]
wall    = 22;    // panel thickness [mm] (22 mm birch plywood)
round_r = 19;    // front vertical roundover radius [mm] (R50 leaves no
                 //   flat for the 242 mm waveguide flange — checked below)

// ---- GRS 12SW-4HE woofer (assets/datasheets/GRS-12SW-4HE.md) ---------
woofer_frame_d  = 332;   // overall frame diameter        [datasheet]
woofer_cut_d    = 284;   // baffle cutout diameter        [datasheet]
woofer_bcd      = 319;   // mounting BCD, 8 holes         [datasheet]
woofer_hole_d   = 5.5;   // mounting hole diameter        [datasheet]
woofer_n_holes  = 8;     //                               [datasheet]
woofer_depth    = 136;   // total depth below mounting flange [datasheet]
woofer_displ_L  = 4.5;   // ESTIMATE: basket+magnet volume inside the box [L]
                         //   (GRS-12SW-4HE.md budgets 8-10 L per pair)
woofer_Fs       = 22;    // free-air resonance [Hz]       [datasheet]
woofer_Qts      = 0.43;  // total Q                       [datasheet]
woofer_Vas_L    = 80.4;  // equivalent volume [L]         [datasheet]

woofer_z        = 520;   // woofer centre height [mm] (docs ch.7: ~520 nominal)

// ---- ScanSpeak 18W/4424G00 midrange (all from cad/midrange.scad) -----
// Do NOT hardcode midrange numbers here — they track cad/midrange.scad,
// which carries the official drawing dimensions (18W-4424G00.pdf).
mid_face_d      = mid_flange_od_fn();   // Ø179.2 faceplate
mid_flange_t    = mid_flange_t_fn();    // 5.2 mm flange (rebate depth)
mid_depth       = mid_depth_fn();       // 72.2 mm total depth
mid_bcd         = mid_bcd_fn();         // Ø167 pitch circle
mid_hole_d      = mid_hole_d_fn();      // Ø5.3, x6 at 60 deg
mid_n_holes     = mid_n_holes_fn();
mid_bolt_offset = mid_bolt_offset_fn(); // 30 deg pattern offset
mid_cutout_clear = 0.5;                 // radial cutout clearance [mm]
mid_cut_d       = mid_cut_d_fn() + 2*mid_cutout_clear;  // Ø144.3 -> cut Ø145.3
mid_displ_L     = mid_displ_L_fn();     // 0.28 L displacement [datasheet]
mid_Fs          = mid_Fs_fn();          // 49 Hz
mid_Qts         = mid_Qts_fn();         // 0.38
mid_Vas_L       = mid_Vas_fn();         // 24.1 L
mid_flush       = true;   // rebate the faceplate flush into the front baffle
mid_fit_clear   = 0.7;    // rebate diametral clearance (faceplate tol +-0.3)

// ---- Driver placement (v9: midrange on TOP, waveguide below) ---------
mid_z  = 1065;          // midrange centre height [mm] — near the top; the
                       //   Ø145.3 cutout upper edge must stay clear of the
                       //   inner top face (checked below)
cc     = 164;          // mid/tweeter centre-to-centre [mm]. Physical minimum
                       //   with the Ø179.2 mid faceplate + 143 mm waveguide
                       //   flange both flush-recessed is ~164 mm (echoed
                       //   below as cc_min). DD-011's 140 mm is not reachable
                       //   with these parts.
tw_z   = mid_z - cc;   // waveguide/tweeter centre height [mm]

// ---- Waveguide (all values imported from cad/waveguide.scad) ---------
wg_flange_w = wg_flange_w_fn();   // flange width  242 [mm]
wg_flange_h = wg_flange_h_fn();   // flange height 143 [mm]
wg_flange_r = wg_flange_r_fn();   // flange corner radius [mm]
wg_flange_t = wg_flange_t_fn();   // flange thickness / recess depth [mm]
wg_front    = wg_front_z();       // z of flange FRONT face in the wg frame
wg_back     = wg_back_z();        // z of back-plate rear face in the wg frame
wg_fit_clear  = 0.5;   // flange recess w/h clearance [mm]
wg_body_clear = 1.5;   // radial clearance around the wg body in the baffle [mm]
// The waveguide is FRONT-mounted: the flange sits in a recess milled into
// the FRONT face of the baffle (flange front flush with the baffle front),
// and the body passes through a TAPERED clearance hole in the remaining
// thickness (following the body profile — this keeps the hole as small as
// possible at the inner face, which is what limits how close the divider
// plate above can come). Gasket the flange: the clearance gap opens into
// the bass volume behind it.
wg_clear_rx_o = wg_outer_rx(wg_front - wg_flange_t) + wg_body_clear; // at recess
wg_clear_ry_o = wg_outer_ry(wg_front - wg_flange_t) + wg_body_clear;
wg_clear_rx_i = wg_outer_rx(wg_front - wall) + wg_body_clear;        // at inner face
wg_clear_ry_i = wg_outer_ry(wg_front - wall) + wg_body_clear;
tw_body_displ_L = 0.25; // ESTIMATE: SB26STAC body behind the back plate [L]

// ---- Divider plate (mid chamber above / bass volume below) -----------
// Full-width tilted plate between the midrange and the waveguide: LOW at
// the front (squeezing under the mid basket), rising toward the rear. The
// tilt breaks the parallel ceiling/divider pair of the mid chamber and
// shrinks the chamber toward the datasheet's 13 L closed-box target.
// The plate height is DERIVED from the midrange basket envelope
// (mid_basket_r_at() from cad/midrange.scad): the basket cone falls away
// faster (~30 deg) than the divider rises (12 deg), so the binding point
// is at the inner baffle face.
divider_tilt      = 19;  // [deg] front edge low, rear edge high
divider_mid_clear = 18;   // clearance divider top -> mid basket underside [mm]
divider_front_z   = mid_z - mid_basket_r_at(wall) - divider_mid_clear;

// ---- Bracing ---------------------------------------------------------
shelf_zs  = [160, 330, 730]; // ring-shelf brace heights in the bass volume [mm]
shelf_rim = 45;         // ring-shelf rim width [mm] (open centre = airflow)
coupling_r = 55;        // coupling block radius [mm] — block length is
                        //   derived from the actual magnet gap (echoed)

// ---- Targets ----------------------------------------------------------
bass_target_L = 75;    // net bass volume target (docs/09) [L]
mid_target_L  = 13;    // 18W/4424G00 datasheet closed-box recommendation [L]

// ---- View flags (CI overrides these per render) ----------------------
show_internals      = false; // cutaway with divider + braces
show_waveguide      = false; // seat the waveguide model into the baffle
show_drivers        = false; // show real driver models for scale
show_pilot_holes    = true;  // Ø3 pilot holes on the datasheet BCDs
show_coupling_block = true;  // block between the opposed woofer magnets

eps = 0.1;             // generic cut overshoot for clean booleans [mm]
fn  = 64;
pilot_d = 3;           // pilot hole diameter [mm]
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

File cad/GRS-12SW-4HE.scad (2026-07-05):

// ============================================================
//  GRS 12SW-4HE - 12" High Excursion Subwoofer (sidefyret bas)
//  Parametrisk OpenSCAD-model ud fra datablad-tegning
//  Alle maal i mm.  Front af flange = z=0, enheden gaar i -z.
// ============================================================

/* [Visning] */
vis = "driver"; // [driver:Komplet enhed, cutout:Baffel-udskaering (2D), skabelon:Boreskabelon (3D), snit:Halvsnit]

/* [Kotede maal - fra datablad] */
flange_od      = 308;    // Udvendig flangediameter (Ø308)
flange_tyk     = 8.5;    // Flange-/pakningstykkelse
udskaering_dia = 280;    // Kurv-/udskaeringsdiameter (Ø280)
total_dybde    = 160;    // Samlet dybde inkl. bump (max)
magnet_bagside = 148;    // Dybde til magnetens (flade) bagside
bolt_cirkel    = 295;    // Hulcirkel (Ø295)
bolt_hul_dia   = 5.5;    // Monteringshuller (Ø5,5)
antal_huller   = 8;      // Antal huller (45 grader indbyrdes)
bolt_offset    = 0;      // Vinkelforskydning [grader]

/* [Estimerede maal - IKKE kotet, juster efter behov] */
vc_dia        = 50.8;  // Svingspolediameter (fra datablad)
kegle_top_dia = 245;   // Keglens diameter oppe (ved surround)
surround_od   = 272;   // Surround yderdiameter
kegle_bund_dia= 58;    // Keglens diameter nede
kegle_hoejde  = 78;    // Keglens dybde
stoevhat_dia  = 95;    // Stoevhaettens diameter
stoevhat_z    = -18;   // Stoevhaettens centrum-dybde (0 = flangefront)
magnet_dia    = 140;   // Magnetdiameter (Ø140)
magnet_hoejde = 40;    // Magnethoejde

/* [Baffel] */
baffel_tyk       = 21;
cutout_clearance = 1.0;  // Ekstra paa udskaering (radius pr. side)

/* [Render] */
$fn = 140;
eps = 0.05;

magnet_start_z = -(magnet_bagside - magnet_hoejde); // magnetens front

// ------------------------------------------------------------
module bolt_hoved() {
    for (i=[0:antal_huller-1]) {
        a = bolt_offset + i*360/antal_huller;
        rotate([0,0,a]) translate([bolt_cirkel/2,0,0]) children();
    }
}
module bolt_huller(h,z0) { bolt_hoved() translate([0,0,z0]) cylinder(d=bolt_hul_dia,h=h); }

// Flange / frontplade - KOTET
module flange() {
    color("dimgray")
    difference() {
        translate([0,0,-flange_tyk]) cylinder(d=flange_od,h=flange_tyk);
        translate([0,0,-flange_tyk-eps]) cylinder(d=surround_od,h=flange_tyk+2*eps);
        bolt_huller(flange_tyk+2*eps,-flange_tyk-eps);
    }
}

// Kurv (tynd konisk skal) - ESTIMAT
module kurv() {
    v=4;
    color("gray")
    difference() {
        hull() {
            translate([0,0,-flange_tyk]) cylinder(d=udskaering_dia,h=eps);
            translate([0,0,magnet_start_z]) cylinder(d=magnet_dia,h=eps);
        }
        hull() {
            translate([0,0,-flange_tyk-eps]) cylinder(d=udskaering_dia-2*v,h=eps);
            translate([0,0,magnet_start_z+v]) cylinder(d=magnet_dia-2*v,h=eps);
        }
        translate([0,0,-flange_tyk-eps]) cylinder(d=udskaering_dia-2*v,h=eps+v);
    }
}

// Surround - ESTIMAT
module surround() {
    r=(surround_od-kegle_top_dia)/4; c=kegle_top_dia/2+r;
    color("black") translate([0,0,-flange_tyk])
        rotate_extrude() translate([c,0]) circle(r=r);
}

// Kegle - ESTIMAT
module kegle() {
    v=2; top=-flange_tyk-3;
    color("peru") translate([0,0,top-kegle_hoejde])
    difference() {
        cylinder(d1=kegle_bund_dia,d2=kegle_top_dia,h=kegle_hoejde);
        translate([0,0,v]) cylinder(d1=kegle_bund_dia-2*v,d2=kegle_top_dia-2*v,h=kegle_hoejde);
    }
}

// Stoevhat - ESTIMAT
module stoevhat() {
    color("saddlebrown") translate([0,0,stoevhat_z]) scale([1,1,0.4]) sphere(d=stoevhat_dia);
}

// Magnetsystem - ESTIMAT (Ø140 x 40, bumpet bagplade til dybde 160)
module magnet() {
    color("dimgray") union() {
        translate([0,0,-magnet_bagside]) cylinder(d=magnet_dia,h=magnet_hoejde);
        translate([0,0,magnet_start_z-eps]) cylinder(d1=magnet_dia,d2=vc_dia+18,h=14);
        // bumpet bagplade (fra 148 til 160)
        translate([0,0,-total_dybde]) cylinder(d=magnet_dia*0.5,h=total_dybde-magnet_bagside);
    }
}

module driver() { flange(); kurv(); surround(); kegle(); stoevhat(); magnet(); }

// ------------------------------------------------------------
module baffel_cutout_2d() {
    circle(d=udskaering_dia+2*cutout_clearance);
    bolt_hoved() circle(d=bolt_hul_dia);
}
module boreskabelon() {
    od=flange_od+8; t=4;
    difference() {
        cylinder(d=od,h=t);
        translate([0,0,-eps]) cylinder(d=udskaering_dia,h=t+2*eps);
        bolt_huller(t+2*eps,-eps);
    }
    difference() { cylinder(d=flange_od,h=0.6); translate([0,0,-eps]) cylinder(d=flange_od-1.5,h=0.6+2*eps); }
}

// ------------------------------------------------------------
if (vis=="driver") driver();
else if (vis=="cutout") baffel_cutout_2d();
else if (vis=="skabelon") boreskabelon();
else if (vis=="snit") difference(){ driver(); translate([0,-250,-250]) cube([250,500,500]); }

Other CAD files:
assets/cad/SB26STAC-C000-4.stp
cad/midrange.scad
cad/SB26STAC-C000-4.scad
cad/cabinet_v2.scad
cad/waveguide.scad

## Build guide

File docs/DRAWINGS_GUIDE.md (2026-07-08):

# SVG Drawing Generation Guide

## Overview

The `scripts/generate_drawings.py` script generates dimensioned technical drawings in SVG format from the OpenSCAD CAD models. These drawings are used for:

- Cabinet panel cut lists and assembly dimensions
- Driver cutout and hole-position layouts
- Build documentation and CNC routing templates

All drawings are parametric — they parse dimensions directly from the SCAD source files, so they stay in sync with the CAD model automatically.

## Generated Drawings

| Drawing | Purpose | Source |
|---|---|---|
| `front_baffle.svg` | Front baffle with midrange + tweeter cutouts, rebate, pilot holes | `cabinet.scad`, `midrange.scad`, `waveguide.scad` |
| `side_panel.svg` | Side panel with woofer cutout + pilot holes | `cabinet.scad` |
| `cut_list.svg` | Panel cut list with dimensions + quantities | `cabinet.scad` |
| `assembly_dims.svg` | Assembly measurement drawing (heights, spacing, edges) | `cabinet.scad` |
| `panel_*.svg` (7 files) | Individual panel cut drawings (front baffle, sides, top, bottom, back, divider, shelf brace) | `cabinet.scad` |

All SVGs are written to `assets/drawings/`.

## Running the Script

```bash
python3 scripts/generate_drawings.py                    # write SVGs to assets/drawings/
python3 scripts/generate_drawings.py --outdir /tmp/     # custom output directory
```

## How It Works

### 1. SCAD Parameter Parsing

The script reads OpenSCAD files and extracts numeric variables using regex:

```python
_parse_var(text, "W")      # Extract: W = 300;
_parse_list(text, "shelf_zs")  # Extract: shelf_zs = [200, 400, 600];
```

This keeps drawings synchronized with the CAD model — if you change `W = 300` to `W = 320` in `cabinet.scad`, the next run regenerates all drawings with the new width.

### 2. SVG Class

A lightweight SVG builder with primitives for technical drawings:

```python
svg = SVG(width, height, title)
svg.rect(x, y, w, h, cls="panel")           # Rectangle
svg.circle(cx, cy, r, cls="cutout")         # Circle
svg.line(x1, y1, x2, y2, cls="dim-line")    # Line
svg.text(x, y, text, cls="label")           # Text
svg.text_wrap(x, y, text, cls="title-text") # Left-aligned text with word-wrap
svg.dim_h(x1, x2, y, label="100")           # Horizontal dimension line
svg.dim_v(x, y1, y2, label="50")            # Vertical dimension line
```

### 3. Text Wrapping

Titles and subtitles wrap automatically if they exceed the canvas width:

```python
svg.text_wrap(15, 25, "Mk3 Front Baffle — Cutout & Hole Layout", "title-text")
```

The method:
1. Estimates text width using `_est_text_width(text, font_size)`
2. Splits on word boundaries if text exceeds `max_width`
3. Renders each line at `x, y + i*line_height`
4. Returns the y position of the last line (for layout chaining)

Width estimation uses a simple model: `len(text) * font_size * 0.55`. This is a rough average for sans-serif fonts; it works well for most text but may underestimate very wide characters (W, M) or overestimate narrow ones (i, l).

### 4. Canvas Sizing

Canvas dimensions are determined purely by content:

```python
dw = W * scale + 2 * margin  # Width = scaled panel + margins
dh = H * scale + 2 * margin  # Height = scaled panel + margins
```

This replaced the old `_min_width()` logic, which tried to fit text by expanding the canvas. Now text wraps instead, keeping canvas size predictable.

## Styling

All drawings use a consistent CSS stylesheet embedded in the SVG:

```css
.panel { fill: #f5f0e0; stroke: #333; stroke-width: 1.5; }      /* Cabinet panels */
.cutout { fill: none; stroke: #c0392b; stroke-width: 1.2; }     /* Driver cutouts */
.rebate { fill: #faebe0; stroke: #e67e22; stroke-width: 1.0; }  /* Rebates/recesses */
.pilot { fill: #333; }                                           /* Pilot holes */
.dim-line { stroke: #2980b9; stroke-width: 0.8; fill: none; }   /* Dimension lines */
.dim-text { fill: #2980b9; font-family: sans-serif; font-size: 11px; } /* Dimension labels */
.title-text { fill: #222; font-family: sans-serif; font-size: 16px; font-weight: bold; }
.subtitle { fill: #555; font-family: sans-serif; font-size: 10px; }
```

Modify these in the `SVG.__init__()` method to change the appearance of all drawings at once.

## Viewing and Exporting

SVGs can be:

- **Opened in any browser** — right-click → Save As to download
- **Converted to PDF** — `rsvg-convert -f pdf drawing.svg -o drawing.pdf`
- **Converted to PNG** — `rsvg-convert -f png drawing.svg -o drawing.png`
- **Imported into CAM software** — most CNC routing software accepts SVG directly
- **Printed** — set scale to 1:1 (100%) in your PDF viewer

## Extending the Script

To add a new drawing:

1. Create a generator function:
   ```python
   def gen_my_drawing(p, outdir):
       """Generate my custom drawing."""
       svg = SVG(width, height, "My Drawing Title")
       # ... add elements ...
       svg.write(os.path.join(outdir, "my_drawing.svg"))
   ```

2. Call it from `main()`:
   ```python
   gen_my_drawing(p, outdir)
   ```

3. Run the script to generate the SVG.

## Troubleshooting

**Text is clipped or overlapping:**
- Check `_est_text_width()` — it may be underestimating width for your text
- Increase `max_width` in `text_wrap()` call
- Reduce font size in the CSS

**Dimensions are wrong:**
- Verify the SCAD variable names match what the script is parsing
- Check `load_params()` for the correct variable names
- Run with `--debug` to print parsed parameters (if implemented)

**SVG doesn't render correctly:**
- Validate the SVG: `xmllint --noout drawing.svg`
- Check that all text is properly escaped (& → &amp;, < → &lt;, > → &gt;)
- Ensure all coordinates are numeric (no NaN or Infinity)

## Future Improvements

- [ ] Character-width lookup table for more accurate text estimation
- [ ] Automatic scale calculation based on content
- [ ] Layer support (for CAM software)
- [ ] Tolerance/clearance annotations
- [ ] 3D isometric projections (for assembly drawings)

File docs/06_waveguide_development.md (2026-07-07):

# Chapter 6 - Waveguide Development

---

## Purpose

A waveguide serves several functions in a 3-way loudspeaker:

1. **Directivity control** - shapes the radiation pattern of the tweeter so it matches the narrowing directivity of the midrange below the crossover frequency
2. **Loading** - provides acoustic load that reduces tweeter excursion near the crossover
3. **Sensitivity increase** - concentrates forward energy, increasing on-axis sensitivity
4. **Lower crossover frequency** - a well-loaded tweeter can cross lower than a bare dome, reducing lobing

Without a waveguide, a bare 26 mm dome tweeter radiates almost omnidirectionally up to approximately 4-6 kHz. The midrange driver narrows significantly above about 1500 Hz. This mismatch in directivity causes a visible step in the DI curve and a response hole in the off-axis measurements at the crossover frequency.

---

## Design strategy

The waveguide is a custom 3D-printed design, intended to be printed in PLA or PETG and sanded/painted for the prototype. The final version may be machined or CNC-routed in a harder material.

Key design parameters:

| Parameter | Description |
|---|---|
| Mouth diameter | Defines directivity at the crossover frequency |
| Throat diameter | Must fit the SB26STAC dome and surround |
| Profile | Determines the waveguide's directivity behavior |
| Depth | Affects directivity and baffle integration |
| Flange shape | Determines how the waveguide integrates with the baffle |

---

## Variants compared

The simplified directivity simulations compared four waveguide mouth diameters:

| Variant | Mouth | Notes |
|---|---|---|
| ~212 mm | ~212 mm | Current candidate |
| ~220 mm | ~220 mm | Marginal improvement in directivity |
| ~230 mm | ~230 mm | More directional, larger baffle impact |
| ~240 mm | ~240 mm | Most directional but mechanically challenging in 320 mm cabinet |

---

## Selection: ~212 mm mouth

The ~212 mm mouth was selected as the current design direction (DD-009). The key finding from the simplified simulations was:

> The strongest improvement in spinorama quality comes from lowering the mid/tweeter crossover frequency and reducing the c-c spacing, not from increasing the waveguide mouth size.

A larger waveguide (~230 or ~240 mm) did increase horizontal directivity at the crossover frequency, but it:
- Demanded more baffle width to integrate cleanly
- Left less room for the midrange below the waveguide
- Made the 140 mm c-c spacing harder to achieve
- Required a larger cabinet front, increasing diffraction

The improvement from ~220 to ~240 mm was significantly smaller than the improvement from reducing the crossover frequency by 50-100 Hz.

---

## Waveguide geometry (design candidate)

A parametric OpenSCAD model now exists:
[`../cad/waveguide.scad`](../cad/waveguide.scad) (see
[`../cad/README.md`](../cad/README.md)). It realises the waveguide as an
**asymmetric oblate-spheroid (OS)** profile — wide horizontally to match the
still-broad midrange at the crossover, narrower vertically to limit vertical
lobing. The SB26STAC-C000-4 is a conventional dome tweeter (no built-in horn),
so the waveguide is a pure directivity device rather than a horn extension.

| Parameter | Value (estimate) |
|---|---|
| Throat diameter | 28 mm (SB26STAC dome + surround) |
| Baffle cutout diameter (BCD) | 88.5 mm |
| Profile | Oblate-spheroid bore + tangent rolled mouth (flush with baffle) |
| Nominal coverage | ~100° horizontal / ~64° vertical |
| Mouth | ~293 × 173 mm |
| Total depth | ~98 mm |
| Horizontal pattern-control limit | ~1620 Hz |
| Flange | recessed into the baffle |

Because horizontal control only reaches down to ~1620 Hz, the waveguide best
supports a crossover **near that limit**. The current target is 1100 Hz LR4
(DD-014), which sits below the control band — the trade-off is favourable because
the SB26STAC's 350 Hz Fs margin removes the distortion risk of crossing low, and
the lower crossover improves the directivity match and vertical lobing (see
Chapter 11).

| Task | Status |
|---|---|
| Define throat diameter (SB26STAC specific) | 28 mm — caliper-verify on physical unit |
| Define profile (OS/Tractrix/custom) | Done — asymmetric OS |
| Define mouth and termination | Done — ~293 × 173, rolled flush mouth |
| Define depth | Done — ~98 mm |
| Define flange shape for baffle integration | Done — recessed into baffle |
| Generate OpenSCAD or CAD model | Done — `cad/waveguide.scad` |
| Export STL for printing | Done (manifold) |
| Print prototype | Pending |
| Test fit SB26STAC | Pending |
| Measure in finished cabinet | Pending |

---

## Profile guidance

The waveguide profile determines how directivity transitions from the throat to the mouth. Common approaches:

**Oblate spheroidal (OS) profile** - mathematically derived profile that produces a constant directivity pattern with a smooth mouth termination. Used in professional studio monitors. Preferred when constant directivity across a wide range is important.

**Tractrix profile** - older profile, still widely used. Generally produces good results but may not achieve true constant directivity.

**Custom/optimized profiles** - can be designed using FEM simulation tools (e.g. Akabak, Comsol) but requires more expertise.

For this project, an OS-inspired profile is the starting point. The final profile will be verified by measuring the printed waveguide in the cabinet.

---

## Integration with the baffle

The waveguide flange must integrate cleanly with the front baffle:

- The flange should sit flush or slightly recessed into the baffle
- The baffle around the waveguide should be as smooth as possible (no sharp edges near the waveguide mouth)

**Mouth termination (avoid a sharp edge).** The waveguide must reach the baffle
*flush and tangent* — any forward lip or 90° step at the mouth diffracts and
shows up as off-axis / spinorama ripple, defeating the waveguide's purpose. The
model seats the flange *behind* the flush mouth plane (see
[`../simulations/waveguide_profile.py`](../simulations/waveguide_profile.py) and
`../simulations/plots/waveguide_termination.png`). For an even smoother transition
the mouth roundover can be enlarged (parameter `Lr`) so it rolls into the baffle
with continuous curvature, and the baffle opening itself should carry a matching
roundover.
- The midrange cutout is immediately below the waveguide; the gap between them sets the c-c distance
- The nominal c-c target is 140 mm, but the realistic buildable value is ~150 mm
  (DD-011 caveat); the narrow vertical mouth (~173 mm) of the asymmetric waveguide
  helps keep this tight without lobing. The `cabinet.scad` model uses 150 mm.

---

## Open items

- Caliper-verify the SB26STAC dome, surround, and faceplate cutout diameter
  against `cad/waveguide.scad` before printing
- Export STL, print, and test-fit the SB26STAC in the waveguide
- Measure SB26STAC in-waveguide response and directivity at 1100 Hz to confirm
  the crossover (expected to pass comfortably given the 350 Hz Fs margin — no
  distortion-test gate required)

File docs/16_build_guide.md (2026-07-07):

# Chapter 16 - Build Guide

---

## Status

The physical build has not yet started. This chapter documents the planned build sequence. It will be updated with actual notes, problems, and fixes as the prototype is built.

See also: [BUILD_LOG.md](../BUILD_LOG.md) for the running construction log.

---

## Prerequisites

Before starting the build:

- [ ] Finalize cabinet CAD drawings
- [ ] Verify all driver dimensions (cutout, frame, mounting depth)
- [ ] Verify waveguide CAD and print prototype
- [ ] Confirm mid chamber dimensions
- [ ] Order all materials and drivers
- [ ] Confirm DSP/amplifier platform

---

## Materials list

### Cabinet

| Item | Specification | Quantity |
|---|---|---|
| Birch plywood | 22 mm, grade BB or better | ~3-4 sheets (1220×2440 mm) |
| Wood glue | PVA or similar | 1 bottle |
| Clamps | Various sizes | As needed |
| Sandpaper | 80/120/180/240 grit | Assorted |
| Primer and paint | Or veneer finish | TBD |

### Damping

| Item | Quantity |
|---|---|
| Bitumen damping pads | For inside panel faces |
| Acoustic foam or mineral wool (bass chamber) | ~2-3 L |
| Acoustic foam or long-fiber wool (mid chamber) | ~0.5-1 L |

### Hardware

| Item | Specification | Quantity |
|---|---|
| Threaded inserts | M4 or M5 for driver mounting | ~20 |
| Driver mounting screws | M4 or M5 | ~20 |
| Gasket tape | 3-5 mm foam, self-adhesive | ~2 m |
| Terminal plate or amplifier cutout plate | TBD | 1 per speaker |
| Internal speaker cable | TBD | ~2 m per speaker |

### Drivers (per speaker)

| Driver | Quantity |
|---|---|
| GRS 12SW-4HE | 2 |
| ScanSpeak 18W/4424G00 | 1 |
| SB Acoustics SB26STAC-C000-4 | 1 |
| Printed waveguide | 1 |

---

## Build sequence

### Phase 1: Panel cutting

1. Cut all cabinet panels to final dimensions from plywood sheet
2. Cut mid chamber panels
3. Cut shelf/window brace panels
4. Label all panels
5. Check fit (dry assembly without glue)

### Phase 2: Driver cutouts

1. Cut woofer cutouts on side panels (284 mm diameter per GRS 12SW-4HE datasheet — verify on physical driver first)
2. Cut midrange cutout on front baffle
3. Cut waveguide cutout on front baffle
4. Cut terminal/amplifier cutout on rear panel
5. Deburr and sand all cutouts smooth

### Phase 3: Mid chamber assembly

1. Assemble mid chamber sub-enclosure (panels + glue)
2. Seal all mid chamber joints with glue
3. Test fit into main cabinet
4. Line mid chamber interior with damping material
5. Install midrange threaded inserts in front baffle

### Phase 4: Main cabinet assembly

1. Glue bottom panel to front and rear panels
2. Add side panels
3. Install window brace(s) in bass chamber
4. Install shelf brace at mid chamber location
5. Glue top panel
6. Clamp and let cure fully (24 h minimum)
7. Check all joints for gaps, fill if needed

### Phase 5: Internal damping

1. Apply bitumen pads to inside faces of all bass chamber panels
2. Apply acoustic fill (moderate amount) to bass chamber
3. Do not fill near woofer ports or in woofer path
4. Seal any remaining gaps around brace edges

### Phase 6: Woofer installation

1. Install threaded inserts in side panels at woofer positions
2. Apply gasket tape around woofer cutouts (284 mm)
3. Install lower woofer (GRS 12SW-4HE)
4. Install upper woofer (GRS 12SW-4HE)
5. Check push-push wiring polarity (battery test) — both cones must move in the same direction
6. Verify the coupling block (h=20 mm, r=55 mm) bridges the ~4 mm magnet gap without obstructing air flow
7. Run wiring to terminal area

### Phase 7: Mid chamber installation

1. Install mid chamber into cabinet
2. Seal mid chamber to front baffle and side walls
3. Install midrange (ScanSpeak 18W/4424G00) with gasket tape
4. Run midrange wiring to terminal area

### Phase 8: Waveguide and tweeter

1. Test fit printed waveguide in front baffle cutout
2. Confirm c-c spacing to midrange (target: 165 mm, DD-016)
3. Mount SB26STAC tweeter into waveguide
4. Install waveguide + tweeter assembly in front baffle
5. Run tweeter wiring to terminal area

### Phase 9: Finishing

1. Sand cabinet exterior (start with 80, finish with 180 or 240)
2. Apply primer coat
3. Fill any surface defects
4. Apply final paint or veneer

### Phase 10: Electronics

1. Install terminal plate or amplifier module in rear cutout
2. Terminate and route all internal wiring
3. Connect DSP/amplifier per signal chain
4. Set initial crossover settings in DSP
5. Connect source

---

## Commissioning and first checks

1. Apply signal and verify all three driver systems produce sound
2. Run polarity test on woofers (battery test on each, verify push-push)
3. Run initial frequency sweep - check for gross problems
4. Run distortion measurement on tweeter at 1100 Hz
5. Proceed to full measurement campaign (Chapter 15)

---

## Known risks and watch points

| Risk | Mitigation |
|---|---|
| Mid chamber not fully sealed | Check all joints with smoke test or listen for leaks |
| Push-push wiring reversed | Battery polarity test before full assembly |
| SB26STAC distortion too high at 1100 Hz | Measure before committing to crossover frequency (expected comfortable — 350 Hz Fs margin) |
| Woofer mounting depth too deep for 22 mm wall | Verify GRS 12SW-4HE spec (~136 mm total depth); opposed magnet gap is only ~4 mm — check basket profile |
| R50 roundovers - router tear-out | Sharp bit, slow passes, backing board |
| Waveguide print warping | Use PETG, print flat, allow to cool slowly |

---

## Issue log

Document all problems found during the build here. This becomes part of the permanent record for future versions.

(No issues yet - build not started.)

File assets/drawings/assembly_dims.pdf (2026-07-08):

## Mk3 Cabinet — Assembly Measurement Drawing

### FRONT

### SIDE

12SW

divider 19°

D=420

H=1180 520

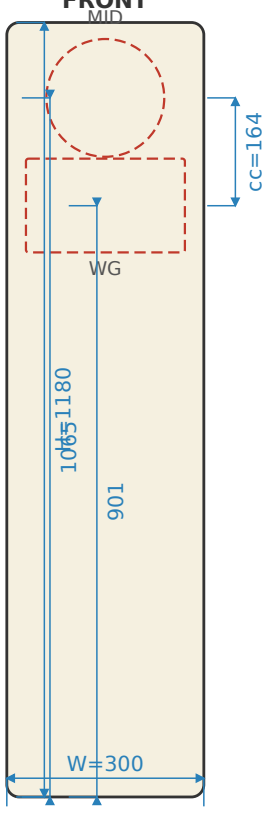
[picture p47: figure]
MID; W=300 H=¹¹⁸⁰ 1065

Internal: 256 × 376 × 1136 mm | Wall: 22 mm | Roundover: R19
Driver heights: MID z=1065 WG/TW z=901 Woofer z=520 | C-C mid/tw:
164 mm Shelf braces at z=[160, 330, 730] | Divider tilt: 19°

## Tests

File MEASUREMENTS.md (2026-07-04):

# Measurements

This file contains the measurement plan for the Mk3 Reference Loudspeaker.

---

# Goal

Validate the simulated design with real acoustic measurements and use the data to create the final DSP tuning.

---

# Required Tools

- Measurement microphone, e.g. UMIK-1 or calibrated XLR microphone
- REW
- VituixCAD
- Turntable or angle jig
- Tape measure / laser distance meter
- Quiet measurement environment
- Optional: ground-plane outdoor measurement area

---

# Driver Measurements

## Woofer (GRS 12SW-4HE)

- Nearfield measurement of each woofer (12" high excursion, Fs 22 Hz, Xmax 12.5 mm)
- Combined nearfield response
- Check polarity and push-push wiring (battery test — both cones move same direction)
- Distortion measurement at relevant levels — verify Klippel Xmax holds in cabinet
- Verify Linkwitz Transform target (39→28 Hz, Q 0.76→0.707) against measured sealed response
- Measure max SPL @ 30 Hz — target +16 dB over the previous 8SW design

## Midrange

- On-axis response in cabinet
- Horizontal off-axis response
- Vertical off-axis response
- Distortion around 150-2000 Hz

## Tweeter / Waveguide

- On-axis response in the waveguide
- Horizontal off-axis response
- Vertical off-axis response
- Distortion around 1000-5000 Hz
- Confirm whether 1100 Hz LR4 is practical for the SB26STAC-C000-4

---

# Horizontal Measurement Angles

Minimum set:

- 0 deg
- 10 deg
- 20 deg
- 30 deg
- 40 deg
- 50 deg
- 60 deg

Extended set:

- 70 deg
- 80 deg
- 90 deg

---

# Vertical Measurement Angles

Minimum set:

- -30 deg
- -20 deg
- -15 deg
- -10 deg
- 0 deg
- +10 deg
- +15 deg
- +20 deg
- +30 deg

Focus area:

- 800 Hz to 3000 Hz
- Mid/tweeter crossover region
- Listening window around +/-15 deg

---

# Nearfield / Farfield Merge

Tasks:

- Measure bass nearfield
- Measure farfield response
- Merge low-frequency and farfield data
- Apply baffle diffraction/room-window handling carefully

---

# VituixCAD Workflow

- Import all driver measurements
- Add acoustic offsets
- Build active crossover model
- Optimize LR4 acoustic slopes
- Verify directivity
- Export DSP targets

---

# Validation Targets

## On-axis

Target: approx. +/-1.5 dB after DSP in the main listening range.

## Listening window

Target: smooth and close to on-axis without sudden dips.

## Predicted in-room

Target: smooth downward slope from bass to treble.

## Directivity Index

Target: smooth and generally rising with frequency.

## Vertical response

Target: useful listening window around +/-15 deg.

---

# Open Questions

- Can SB26STAC-C000-4 safely cross at 1100 Hz?
- Is 140 mm c-c mechanically achievable?
- Does the measured waveguide response match the simplified simulation?
- How much EQ is needed around the baffle/waveguide transition?
- Does the push-push bass reduce cabinet vibration as expected?

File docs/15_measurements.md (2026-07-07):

# Chapter 15 - Measurements

---

## Purpose

Measurements validate the simulated design and provide the data needed to finalize the DSP crossover, delay alignment, and EQ. No crossover or DSP settings are finalized until real measurements are taken on the physical prototype.

---

## Required tools

| Tool | Purpose |
|---|---|
| Measurement microphone | Calibrated (e.g. UMIK-1 or calibrated XLR mic + preamp) |
| REW (Room EQ Wizard) | Measurement software, free |
| VituixCAD | Crossover and spinorama analysis |
| Turntable or angle jig | Rotating the loudspeaker for polar measurements |
| Tape measure / laser distance meter | Microphone placement |
| Quiet measurement environment | Minimum background noise |
| Outdoor ground-plane area (optional) | Extended time window for high-quality bass measurements |

---

## Measurement environment

For the initial prototype measurements, a large room or garden outdoor ground-plane measurement is preferred. The longer reflection-free time window allows lower-frequency measurements without gating artifacts.

Indoor measurements can be used for the upper frequency range (above approximately 300-500 Hz) where the measurement window is short enough to gate out room reflections.

For full spinorama measurements, a quiet room with a turntable setup is needed. An anechoic chamber is ideal but not required - gated measurements in a large room can produce adequate results for DIY purposes.

---

## Driver measurements

### Woofer (GRS 12SW-4HE)

- Nearfield measurement of each woofer individually (microphone very close to cone, ~1 cm)
- Combined nearfield response (both woofers driven together)
- Polarity check: verify push-push wiring (both cones moving in same direction)
- Impedance measurement
- Distortion measurement at rated SPL levels (THD vs frequency) — verify Klippel Xmax (12.5 mm) holds in cabinet
- Verify Linkwitz Transform target (39→28 Hz, Q 0.76→0.707) against measured sealed response

### Midrange (ScanSpeak 18W/4424G00)

- On-axis response in the cabinet
- Horizontal off-axis: 0° to 60° in 10° steps
- Vertical off-axis: -30° to +30° in 10° steps
- Distortion in the 150-1500 Hz range
- Impedance in cabinet

### Tweeter / Waveguide (SB Acoustics SB26STAC-C000-4 in waveguide)

- On-axis response in the waveguide mounted in cabinet
- Horizontal off-axis: 0° to 60° in 10° steps
- Vertical off-axis: -30° to +30° in 10° steps
- **Distortion at 1100 Hz** - confirms crossover viability (expected to pass comfortably given the 350 Hz Fs margin)
- Impedance in waveguide

---

## System measurements (assembled prototype)

After driver measurements and initial DSP setup:

- On-axis full system response
- Horizontal polar: 0° to 60° minimum (0° to 90° extended)
- Vertical polar: -30° to +30°
- Listening window (CEA-2034 average)
- Full spinorama set in VituixCAD

---

## Horizontal measurement angles

**Minimum set:**

| Angle |
|---|
| 0° |
| 10° |
| 20° |
| 30° |
| 40° |
| 50° |
| 60° |

**Extended set:**

| Angle |
|---|
| 70° |
| 80° |
| 90° |

---

## Vertical measurement angles

**Minimum set:**

| Angle |
|---|
| -30° |
| -20° |
| -15° |
| -10° |
| 0° |
| +10° |
| +15° |
| +20° |
| +30° |

**Focus area:** 800 Hz to 3000 Hz, particularly the mid/tweeter crossover region.

---

## Nearfield / farfield merge

At low frequencies the measurement window is too short for accurate farfield measurement indoors. The procedure:

1. Measure bass nearfield (microphone very close to the woofer cone)
2. Measure the farfield response gated at the reflection-free time window
3. Merge the two curves in VituixCAD or REW at the appropriate frequency (typically 300-600 Hz)
4. Apply baffle diffraction correction to the nearfield data

---

## VituixCAD workflow

1. Import all driver measurements (on-axis and off-axis)
2. Enter acoustic offsets (driver center positions relative to a reference point)
3. Build active crossover model (BW4 at 200 Hz, LR4 at 1100 Hz)
4. Add delay compensation values
5. Optimize crossover frequency and slopes
6. Compute CEA-2034 spinorama curves
7. Evaluate DI, listening window, sound power, PIR
8. Export DSP targets for implementation

---

## Open questions to resolve through measurement

| Question | How to answer |
|---|---|
| Can SB26STAC in waveguide cross at 1100 Hz? | Measure distortion in waveguide |
| Is 140 mm c-c achievable mechanically? | Verify in cabinet construction |
| Does waveguide response match simulation? | Measure waveguide on/off-axis |
| How much EQ is needed at baffle/waveguide transition? | Measure on-axis and compare to target |
| Does push-push reduce cabinet vibration? | Measure cabinet acceleration (optional) |
| What is the optimal bass shelf amount? | Measure excursion at maximum SPL |

---

## Open items

- Build prototype cabinet
- Set up measurement rig (microphone stand, turntable or angle jig)
- Calibrate measurement microphone
- Follow VituixCAD import workflow
- Document all measurement results in this file

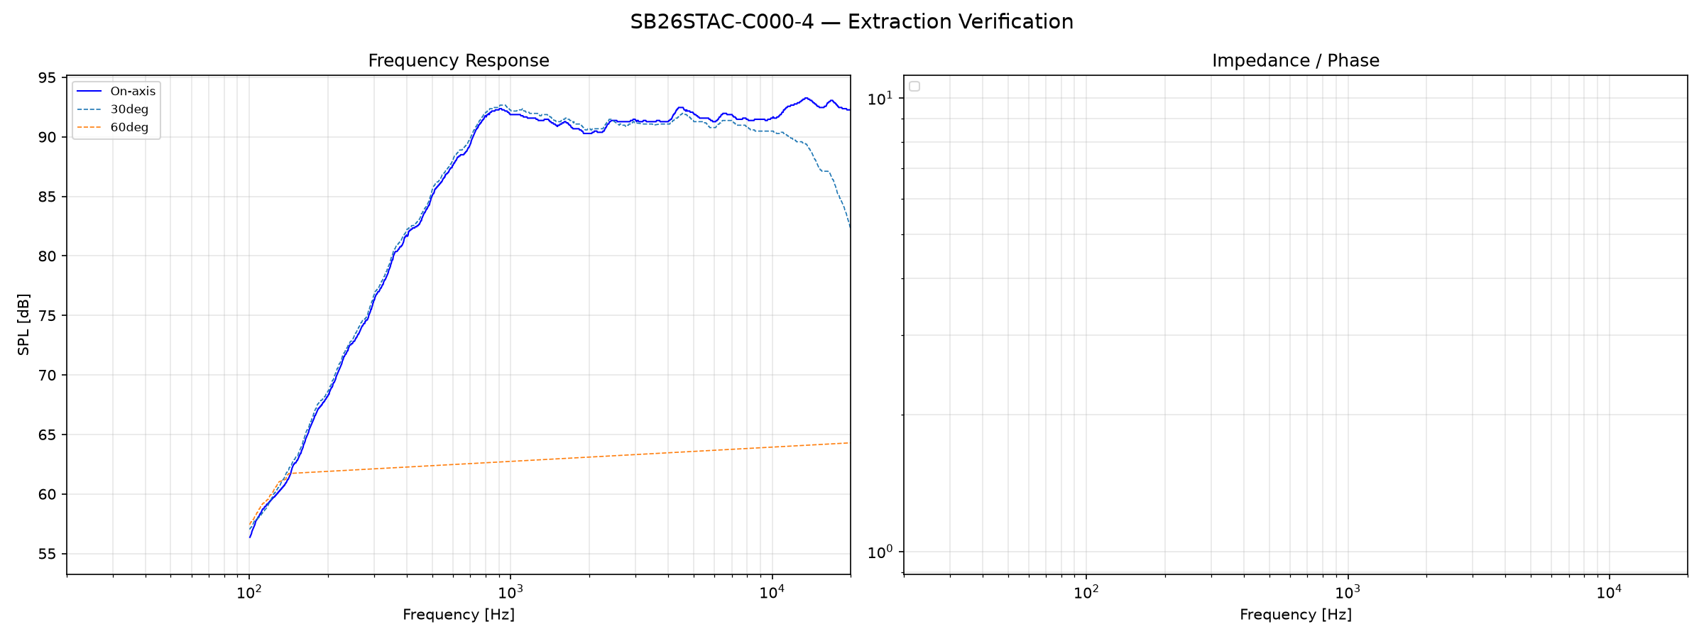
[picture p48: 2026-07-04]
assets/datasheets/SB26STAC-C000-4_extraction_verify.png

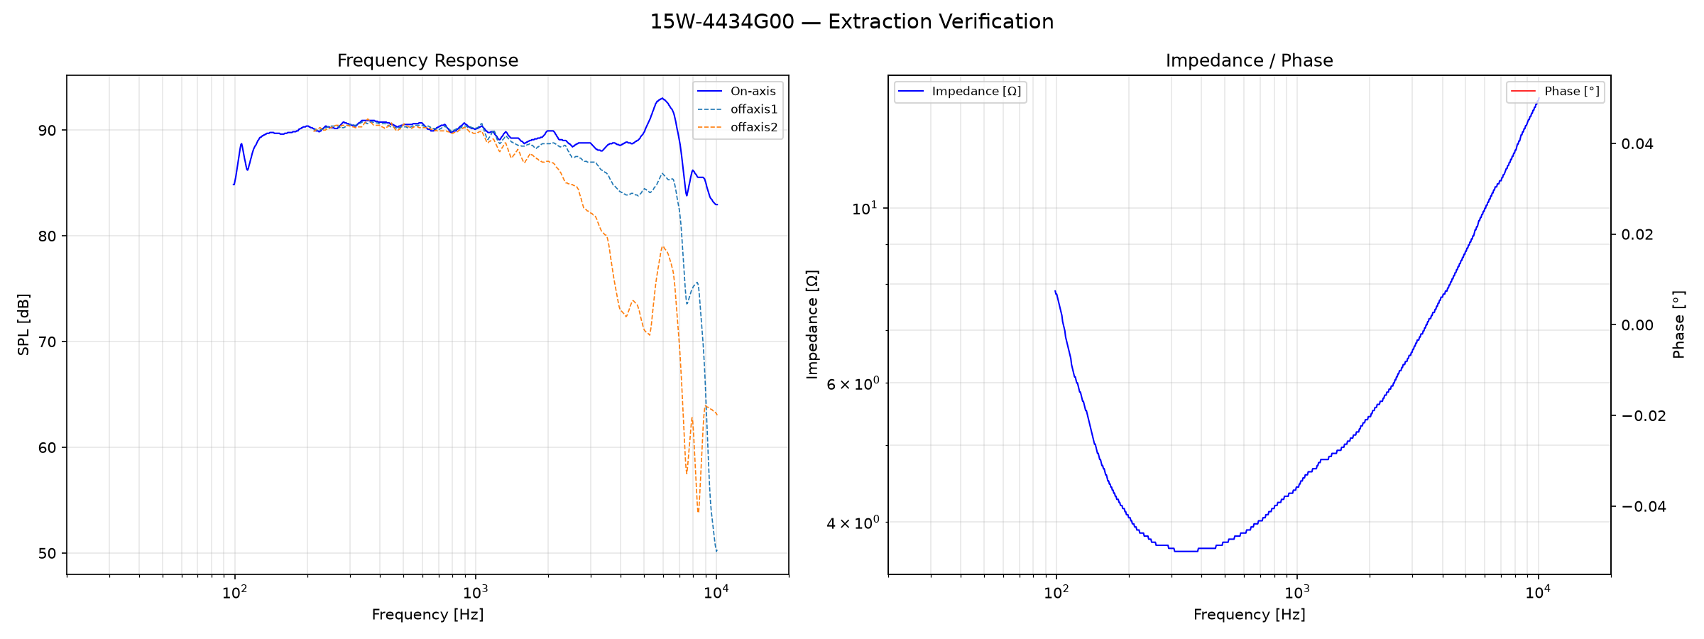
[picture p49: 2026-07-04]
assets/datasheets/15W-4434G00_extraction_verify.png

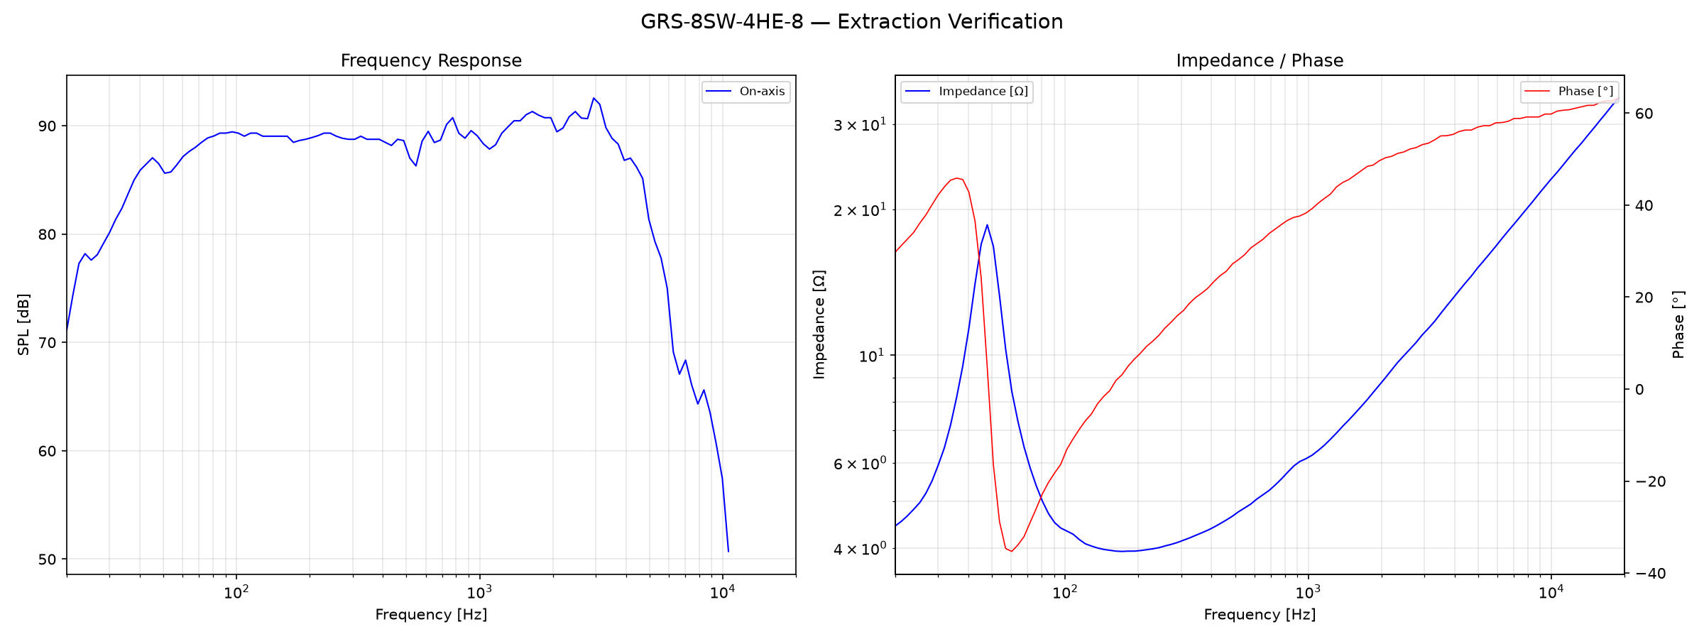
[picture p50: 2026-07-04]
assets/datasheets/GRS-8SW-4HE-8_extraction_verify.png

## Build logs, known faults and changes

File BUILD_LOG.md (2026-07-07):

# Build Log

This file will track the physical build of the Mk3 Reference Loudspeaker.

---

# Prototype 1

## Status

Not started.

## Goals

- Validate cabinet geometry
- Validate woofer fit
- Validate waveguide and 18W spacing
- Validate mid chamber volume
- Validate bracing layout
- Prepare for acoustic measurements

---

# Cabinet Build Notes

## External dimensions

- Width: 320 mm
- Depth: 380 mm
- Height: 1180 mm
- Material: 22 mm birch plywood
- Front vertical roundovers: R19

## Bass placement

- Woofer centers: approx. 520 mm from bottom (both sides, opposed at the same height)
- Configuration: side-mounted push-push, opposed + coupling block (see Chapter 8)

## Mid/tweeter layout

- ScanSpeak 18W/4424G00 midrange at TOP of baffle
- Waveguide/tweeter BELOW midrange
- Target c-c spacing: 165 mm (DD-016)

---

# Assembly Checklist

- [ ] Cut panels
- [ ] Cut braces
- [ ] Build mid chamber
- [ ] Test fit waveguide
- [ ] Test fit midrange
- [ ] Test fit woofers
- [ ] Install threaded inserts
- [ ] Glue cabinet
- [ ] Add internal damping
- [ ] Install drivers
- [ ] Wire drivers
- [ ] Install DSP/amplifier
- [ ] Run polarity test
- [ ] Run first measurements

---

# Measurement Log

Use this section for real measurement notes.

## Date

TBD

## Setup

TBD

## Results

TBD

---

# Issues Found

Document all mechanical/acoustic problems here.

---

# Fixes

Document all fixes and revisions here.

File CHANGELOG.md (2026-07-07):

# Changelog

All notable design changes for the Mk3 Reference Loudspeaker are documented here.

## v9 (in progress) — 18W/4424G00 midrange, mid-over-waveguide layout

### Changed

- **Midrange driver changed** from ScanSpeak 15W/4434G00 to **ScanSpeak
  18W/4424G00** (Discovery, 18 cm, 4 Ω): Fs 49 Hz, Qts 0.38, Vas 24.1 L,
  Sd 137 cm², 91 dB — sensitivity now within 0.5 dB of the SB26STAC.
  Drawing dims: Ø179.2 faceplate, Ø144.3 cutout, Ø167 BCD (6×Ø5.3),
  72.2 mm depth. Parametric model: `cad/midrange.scad`; datasheet:
  `assets/datasheets/18W-4424G00.pdf` + `.md`. See DD-016.
- **Front layout flipped**: the midrange now sits at the TOP of the baffle
  with the waveguide BELOW it, and the full-width tilted divider plate runs
  between them. The mid chamber is the top section of the cabinet (~11 L
  net — near the 18W's 13 L closed-box recommendation, predicted Qtc ~0.68,
  Fc ~88 Hz), and the bass volume below grows to **~65 L net** (predicted
  Qtc ~0.80, Fc ~41 Hz before Linkwitz Transform).
- **Mid/tweeter c-c increased to 165 mm** — the physical minimum with the
  Ø179.2 mid faceplate and the 143 mm waveguide flange both flush-recessed
  (DD-011's 140 mm target is not reachable with these parts).
- **Cabinet external width documented as 320 mm** (spec tables previously
  said 300 mm; 256 mm internal cannot fit two opposed 136 mm-deep
  12SW-4HE). Front roundovers documented as R19 (R50 leaves only 220 mm
  flat baffle — narrower than the 242 mm waveguide flange).

### Added

- **`cad/cabinet.scad` rewritten** around real datasheet dimensions with
  automatic volume calculation and mechanical self-checks (echoed in litres /
  mm on every render, updating with any parameter change):
  - Bass and mid chamber volume in litres + predicted sealed Qtc/Fc from
    datasheet T-S values; WARNINGs on collisions or missed targets.
  - **Waveguide front-mounted**: flange recessed flush into the front baffle
    face (matching its countersunk front screws), with a tapered body
    clearance hole derived from the waveguide profile exports.
  - **Divider plate height derived** from the midrange basket envelope
    (tilt 12°, front low); braces are ring shelves with open centres
    (single connected bass air volume), notched for the woofer baskets.
  - **Push-push magnet gap computed** from datasheet depths: ~48 mm at
    276 mm internal width (not ~4 mm as previously noted); the coupling
    block length derives from the gap.
  - Flush-mount rebates, pilot holes on all datasheet bolt circles, and the
    real `cad/midrange.scad` driver model in assembly renders.
- `assets/datasheets/15W-4434G00.md` corrected: the earlier mechanical
  table (104 / 95 / 45.1 / Ø72) did not match the official drawing
  (Ø149.3 faceplate, Ø136.5 BCD, 61.9 mm depth) — the Ø72 figure had
  produced an impossible midrange cutout in earlier cabinet models.

### Notes

- Net bass volume ~75 L with the updated 320×380×1180 mm cabinet — Qtc ~0.80 / Fc ~41 Hz with Linkwitz Transform to 28 Hz Q0.707.
- 1100 Hz LR4 mid/tweeter crossover is unchanged. Re-validate for the larger 18 cm cone (directivity at the top of the mid band) and the 164 mm c-c (vertical lobing) once parts are measured.
- **Bass/mid crossover updated from 150 Hz LR4 to 200 Hz BW4**: BW4's +3 dB sum at crossover fills the dip that LR4 created where the woofer's sealed rolloff left a hole before the mid was fully online. 18W/4424G00 has 27.9 dB excursion headroom at 200 Hz (Xmax 4.5 mm @ 90 dB). 12SW ka=0.46 at 200 Hz (no directivity issues).
- **DSP gains updated**: Woofer 0 dB (unity, avoids DAC headroom waste), Mid -4.0 dB, Tweeter -9.0 dB. Optimized against Harman in-room target at 0.1 dB resolution. Spreads: W-M=4.0, M-T=5.0. Post-DSP residual ±0.3 dB.
- **Baffle step modeled from cabinet.scad**: side woofers D/2=190 mm (f_bs=287 Hz), front mid/tweeter W/2=160 mm (f_bs=341 Hz). All v9 simulation scripts import from `simulations/cabinet_params.py` which parses `cad/cabinet.scad` at runtime.
- **DSP config**: `dsp-configs/mk3-v9-200-1100-bw4-lr4.xml` (renamed from mk3-v9-150-1100-lr4.xml).

## v8 — GRS 12SW-4HE woofer upgrade

### Changed

- **Woofer upgraded** from GRS 8SW-4HE-8 (8") to **GRS 12SW-4HE (12" high
  excursion)**. Push-push configuration retained (2 per enclosure, side-mounted).
  The 8SW remains in the repo as a historical comparison driver.
- **Bass volume** increased from ~69 L (total) to **~75 L under the divider plate**.
- **Sealed alignment** changed: Fc ~39 Hz, Qtc ~0.76 (was Fc ~34.5 Hz, Qtc ~0.62).
- **Linkwitz Transform** updated: Fc 39.0→28 Hz, Qtc 0.76→0.707 (was 47.2→28 Hz,
  0.63→0.707).
- **Woofer cutout** increased from 185 mm to **284 mm**.
- **Cabinet CAD** (`cad/cabinet.scad`) updated for 12SW frame (~332 mm overall,
  ~136 mm mounting depth, 284 mm cutout, coupling block h=20/r=55 mm).

### Added

- New key 12SW T/S parameters: Fs 22 Hz, Qts 0.43, Vas 80.4 L, Sd 504 cm²,
  Xmax 12.5 mm (Klippel verified), Bl 16.2 Tm, sensitivity 84.5 dB, 250 W,
  ~€75 per driver.
- **Max SPL @ 30 Hz: +16 dB** over the previous 8SW design.
- **Displacement: 12.6 cm³** (was 2.0 cm³) — 6.3× more, from the larger Sd and
  much higher Xmax.

### Notes

- Opposed magnet clearance is tight (~4 mm gap at 276 mm internal width vs ~22 mm
  for the old 8SW). The coupling block and basket depth must be verified before
  cutting panels.
- Design decisions recorded as DD-015.

## v7 — SB26STAC tweeter, 1100 Hz crossover

### Added

- **SB Acoustics SB26STAC-C000-4** conventional dome tweeter selected as the
  tweeter. Fs 750 Hz, 0.6 mm Xmax, 91.5 dB, 4 Ω.
- **1100 Hz LR4** mid/tweeter crossover selected.
- **Custom non-horn-loaded waveguide** (`cad/waveguide.scad`) — the SB26STAC is a
  conventional dome and is not horn-loaded, so it uses a waveguide geometry that
  provides directivity control without relying on a built-in horn.
- **+8.1 dB excursion headroom** at the crossover frequency — the lower Fs
  (750 Hz) and 1100 Hz crossover place the operating point at ~1.47 × Fs,
  reducing distortion/excursion risk.
- New simulation scripts: `system_response_realistic.py`,
  `spinorama_estimate.py`, `crossover_optimization.py`,
  `tweeter_comparison.py` (see `simulations/`).

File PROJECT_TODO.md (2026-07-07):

# Mk3 Reference Loudspeaker — Project TODO

**Design version:** v9 | **Updated:** July 7, 2026

The design uses the SB Acoustics SB26STAC-C000-4 tweeter with a 1100 Hz LR4 crossover.

Grouped by area. The critical path to prototype is marked 🔴.

---

## 🔴 Critical path — must complete before prototype build

### SB26STAC waveguide

- [ ] **Caliper-verify SB26STAC-C000-4 dimensions** — throat/dome diameter, faceplate OD, mounting screw BCD, recess depth. The SCAD model (`cad/waveguide.scad`) uses datasheet values but none have been physically verified yet.
- [ ] **Print SB26STAC waveguide prototype** (PETG recommended, print flat, slow cool). STL at `cad/exports/waveguide.stl`.
- [ ] **Test-fit SB26STAC in printed waveguide** — verify faceplate seating, throat alignment, screw positions.
- [ ] **Measure SB26STAC distortion at 1100 Hz in waveguide** — this is the gate. Target: ≤2% THD at 1100 Hz / 96 dB SPL. If >3%, raise crossover to 1300-1400 Hz and update all simulation scripts. See `MEASUREMENTS.md` for the distortion test protocol.
- [ ] **Confirm realistic c-c spacing** from printed waveguide flange + 18W frame. Expected 165 mm (DD-016). Update `cc_mid_tw_mm` in simulation scripts and DESIGN_DECISIONS.md.

### Cabinet CAD

- [ ] **Verify mid chamber net volume** from `cabinet.scad` solid model — target 5.7 L.
- [ ] **Verify woofer mounting depth** fits 22 mm wall — check GRS 12SW-4HE spec (~136 mm total depth, opposed magnets have only ~4 mm gap in 276 mm internal width).
- [ ] **Confirm driver cutout diameters** — woofer 284 mm (GRS 12SW-4HE datasheet) and midrange 124 mm are estimates. Get exact values from datasheets / physical measurement.
- [x] **Verify divider plate position** in `cabinet.scad` — angled 12° divider plate separates mid chamber from bass volume. Net volume verification pending physical build.
- [x] **Add vertical braces** to `cabinet.scad` — two vertical shelf braces in bass volume at ±120 mm from woofer center, with woofer basket clearance cutouts.
- [ ] **Export STEP file** from cabinet + waveguide models.

### DSP platform

- [x] **MiniDSP 4×10 HD selected** as DSP platform.
- [x] **MiniDSP XML config generated** — `dsp-configs/mk3-v9-200-1100-bw4-lr4.xml` (import via File → Import in MiniDSP plugin).
- [ ] **Verify DSP config with measurement** — import XML, measure, adjust delays and EQ.

---

## Simulation status

### Completed scripts

| Script | What it does | Status |
|---|---|---|
| `system_response_realistic.py` | Real datasheet curves + baffle step + WG loading. **Fixed July 4:** wg_loading transition formula corrected (parenthesization bug caused smeared gain). 15W datasheet extraction artifact at 400 Hz identified and fixed. | ✅ Verified |
| `spinorama_estimate.py` | Spinorama estimate (on-axis, listening window, early reflections, sound power, DI) using simplified driver models. | ✅ |
| `crossover_optimization.py` | Systematic crossover frequency sweep for SB26STAC (800-1600 Hz). Confirms 1100 Hz as optimal. | ✅ |
| `tweeter_comparison.py` | Tweeter selection analysis (excursion, sensitivity, directivity, Fs margin). | ✅ |
| `directivity_estimate.py` | DI mismatch across crossover. Updated for SB26STAC. | ✅ |
| `vertical_polar_map.py` | Vertical lobing heat-map. Updated for 1100 Hz crossover. | ✅ |

### Simulation issues found and fixed (July 4, 2026)

- [x] **wg_loading_db() parenthesization bug** — `np.log10(f_low) * 0.3` should have been `(np.log10(f_high) - np.log10(f_low)) * 0.3`. This caused the waveguide loading gain to smear across 500-5000 Hz instead of transitioning sharply at the control frequency. Fixed in `system_response_realistic.py`.
- [x] **15W datasheet extraction artifact** — The npz data file had a 27 dB V-shaped dip at 400 Hz (62.5 dB floor) caused by PDF grid-line misread. The clean CSV source (`assets/datasheets/15W-4434G00_freq_response.csv`) shows flat 90.8 dB at 400 Hz. Fixed by regenerating npz from CSV.

### Simulation results (pre-DSP, anechoic)

| Metric | Value |
|---|---|
| ±3 dB bandwidth | 623-9710 Hz |
| Midband ripple (500-10k) | 4.2 dB |
| Passband ripple (200-15k) | 7.5 dB |
| Sum @ 1100 Hz (crossover) | 89.9 dB |
| Sum @ 100 Hz | 83.0 dB |
| Sum @ 10 kHz | 92.3 dB |
| DSP correction needed (midband) | ±4.0 dB |

### Open simulation tasks

- [ ] **Import measured data** once prototype is built — spinorama.csv, polar data will become comparison targets.
- [ ] **Regenerate all plots** after any crossover frequency change — the plots in `simulations/plots/` are committed but can go stale if scripts are edited without re-running.

---

## CAD — open tasks

- [x] **SB26STAC waveguide CAD** — `cad/waveguide.scad` created. BCD 88.5 mm, throat 28 mm (dome + surround, no horn). STL rendered, manifold.
- [ ] **Waveguide: STEP export** — for external machining.
- [x] **Waveguide: add baffle roundover blend** — `Lr` parameter (25 mm) controls mouth roundover, documented in `cad/README.md`.
- [ ] **Cabinet: 2D cut drawings** — for workshop use.
- [ ] **Cabinet: mid chamber dimensioned drawing** — volume verification.
- [ ] **Verify `wg_through` parameter** in `cabinet.scad` once waveguide is printed.

---

## CI/CD

- [x] **simulations.yml** — pins numpy + matplotlib + scipy versions.
- [x] **cad-render.yml** — auto-renders STL + views on CAD changes.
- [x] **simulations.yml runs all 12 scripts** — verified, all scripts listed and passing.
- [ ] **cad-render.yml: STEP export** — once OpenSCAD→STEP pipeline confirmed.

---

## Build — ordered sequence

*(Not started. Full sequence in `docs/16_build_guide.md`.)*

- [ ] Order all drivers (2× GRS 12SW-4HE, 1× ScanSpeak 18W/4424G00, 1× SB26STAC-C000-4 per speaker)
- [ ] Order MiniDSP 4×10 HD
- [ ] Order 22 mm birch plywood (~4 sheets per pair)
- [ ] Order hardware (threaded inserts, gasket tape, terminal plate, cable)
- [ ] Cut panels (Phase 1)
- [ ] Cut driver cutouts — confirm diameters from physical drivers first (Phase 2)
- [ ] Assemble mid chamber (Phase 3)
- [ ] Assemble main cabinet (Phase 4)
- [ ] Internal damping (Phase 5)
- [ ] Install woofers — verify push-push polarity with battery test (Phase 6)
- [ ] Install mid chamber + midrange (Phase 7)
- [ ] Install waveguide + SB26STAC tweeter — confirm c-c from built cabinet (Phase 8)
- [ ] Sand + finish (Phase 9)
- [ ] Install electronics (Phase 10)

---

## Measurements (post-build)

*(Full plan in `docs/15_measurements.md` and `MEASUREMENTS.md`.)*

- [ ] Measure SB26STAC distortion at 1100 Hz **before** finalizing crossover — this is the design gate
- [ ] Nearfield woofer measurement
- [ ] Nearfield midrange measurement
- [ ] Nearfield tweeter/waveguide measurement
- [ ] Far-field on-axis (gated or outdoor ground-plane)
- [ ] Polar sweep horizontal: 0° → 180° in 10° steps
- [ ] Polar sweep vertical: ±30° in 10° steps
- [ ] Import to VituixCAD — extract acoustic centers, set delays
- [ ] Finalize DSP: delays + baffle step EQ + waveguide EQ + Linkwitz Transform
- [ ] REW preset file backup

---

## Summary — what's blocking what

```
SB26STAC purchased + caliper verified
    └─► waveguide printed + test-fit
            └─► distortion measurement at 1100 Hz
                    ├─► crossover frequency confirmed (or adjusted to 1300-1400 Hz)
                    │       └─► DSP config imported + verified
                    │               └─► build starts
                    └─► c-c confirmed from real parts
                            └─► DESIGN_REQUIREMENTS + DD updated
```

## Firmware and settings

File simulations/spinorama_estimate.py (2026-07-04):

"""
Spinorama & system frequency response estimate (mk3 — SB26STAC @ 1100 Hz)
=========================================================================

Estimated spinorama curves and system on-axis frequency response for the
mk3 design:

  mk3 (v7):  SB26STAC-C000-4, crossover 1100 Hz, Fs=750, Xmax=0.6mm, sens 91.5 dB

Uses the same cabinet, woofers, midrange, and WG212 coverage angles as the
rest of the design.

ASSUMPTIONS (simplified, NOT measured data — same as polar_response.py)
  - 2x GRS 8SW-4HE: circular pistons (d=200mm), omni below 150 Hz, sealed HP Fc=34.5 Q=0.62
  - 15W/4434G00: flat piston a=58.3mm, sens 89.7 dB
  - SB26STAC in WG212: dome r=13mm → CD horn (100°H × 64°V) transition ~1100-1800 Hz, sens 91.5 dB
  - Baffle/edge effects IGNORED. Room gain not included.
  - Spinorama is 2D horizontal-plane approximation, NOT full CEA-2034.

Output: simulations/plots/spinorama_estimate.png
        simulations/csv/spinorama_estimate.csv
"""
import os
import numpy as np
import matplotlib
matplotlib.use("Agg")
import matplotlib.pyplot as plt

c_speed = 344.0

# ============================================================
#  Shared math
# ============================================================
def j1(x):
    x = np.asarray(x, dtype=float)
    ax = np.abs(x)
    out = np.empty_like(ax)
    s = ax <= 3.0
    y = (x[s] / 3.0)**2
    out[s] = x[s] * (0.5 - 0.56249985*y + 0.21093573*y**2 - 0.03954289*y**3
                     + 0.00443319*y**4 - 0.00031761*y**5 + 0.00001109*y**6)
    b = ~s
    z = 3.0 / ax[b]
    f1 = (0.79788456 + 0.00000156*z + 0.01659667*z**2 + 0.00017105*z**3
          - 0.00249511*z**4 + 0.00113653*z**5 - 0.00020033*z**6)
    t1 = (ax[b] - 2.35619449 + 0.12499612*z + 0.00005650*z**2 - 0.00637879*z**3
          + 0.00074348*z**4 + 0.00079824*z**5 - 0.00029166*z**6)
    out[b] = f1 * np.cos(t1) / np.sqrt(ax[b])
    out[b] = np.sign(x[b]) * out[b]
    return out

def piston_d(theta, a, f):
    ka = 2*np.pi*f/c_speed * a
    st = np.sin(np.radians(theta))
    arg = ka * st
    D = np.ones_like(theta)
    nz = arg != 0
    D[nz] = np.abs(2*j1(arg[nz]) / arg[nz])
    return D

def cd_d(theta, cov_deg):
    half = cov_deg / 2.0
    if half >= 90:
        return np.ones_like(theta)
    n = -6.0 / (20.0 * np.log10(np.cos(np.radians(half))))
    ct = np.cos(np.radians(theta))
    ct = np.maximum(ct, 0.0)
    return ct**n

def smoothstep(x, x0, x1):
    t = np.clip((x - x0) / (x1 - x0 + 1e-12), 0, 1)
    return t * t * (3 - 2*t)

def lr4_lp(f, fc):
    s = 1j * f / fc
    return np.abs((1.0 / (s**2 + np.sqrt(2)*s + 1))**2)

def lr4_hp(f, fc):
    s = 1j * f / fc
    return np.abs((s**2 / (s**2 + np.sqrt(2)*s + 1))**2)

def lr4_lp_db(f, fc):
    s = 1j * f / fc
    H1 = 1.0 / (s**2 + np.sqrt(2)*s + 1)
    H2 = 1.0 / (s**2 + np.sqrt(2)*s + 1)
    return 20*np.log10(np.abs(H1 * H2))

def lr4_hp_db(f, fc):
    s = 1j * f / fc
    H1 = s**2 / (s**2 + np.sqrt(2)*s + 1)
    H2 = s**2 / (s**2 + np.sqrt(2)*s + 1)
    return 20*np.log10(np.abs(H1 * H2))

# ============================================================
#  Configuration (mk3 only)
# ============================================================
cfg = {
    "xover_tw": 1100.0,
    "tw_sens": 91.5,
    "tw_fs": 750.0,
    "tw_roll_start": 700.0,
    "wg_transition": (1100.0, 1800.0),
    "color": "tab:blue",
    "label": "SB26STAC @ 1100 Hz",
}

# Shared parameters
a_w = 0.100      # woofer piston radius (200mm diameter)
a_m = 0.0583     # midrange piston radius
a_t_dome = 0.013 # tweeter dome radius
a_t_wg = 0.106   # waveguide effective mouth radius
F_ctrl = 1620.0  # WG212 control limit

theta = np.linspace(0, 180, 181)

# ============================================================
#  Compute spinorama
# ============================================================
f_spin = np.logspace(np.log10(200), np.log10(20000), 500)
idx_map = {deg: np.argmin(np.abs(theta - deg)) for deg in
           [0, 10, 20, 30, 60, 90, 120, 150, 180]}

fc_tw = cfg["xover_tw"]
wg_t0, wg_t1 = cfg["wg_transition"]

# Woofer directivity
H_w_lp = lr4_lp(f_spin, 150.0)[:, None]
D_w = np.ones((len(f_spin), len(theta)))
for i, fi in enumerate(f_spin):
    D_w[i, :] = piston_d(theta, a_w, fi)
for i, fi in enumerate(f_spin):
    if fi < 150:
        D_w[i, :] = 1.0
D_w *= H_w_lp

# Midrange directivity
H_m_hp = lr4_hp(f_spin, 150.0)[:, None]
H_m_lp = lr4_lp(f_spin, fc_tw)[:, None]
D_m = np.ones((len(f_spin), len(theta)))
for i, fi in enumerate(f_spin):
    D_m[i, :] = piston_d(theta, a_m, fi)
D_m *= H_m_hp * H_m_lp
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

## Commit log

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2026-06-20 docs: de-duplicate assets, index the full SB23 study
    The assets/ upload duplicated files already organised under simulations/, cad/
    and /REVIEW.md. Per the chosen layout, keep the type-based folders as the home
    for those and slim assets/ down to the SB23 study only:
    - remove duplicates from assets/ (REVIEW.md, the two sim scripts + plots,
    mk2_waveguide_os.scad, the second identical design bible, and the redundant
    mk2-review-additions.patch)
    - index the genuinely new SB23-study files (sheets 3-4, baffle, PDF,
    parametre.csv, stykliste.csv, DI hand-off, vertical lobing, WG profile)
    - the design bible's inline links now resolve (profile + parametre present)
    - cross-link the rendered WG pr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
    [mk2_waveguide_os.scad]
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2026-06-21 cad(cabinet): waveguide-in-baffle assembly + eps overshoots
    Addresses the OpenSCAD coincident-face problem: a flush waveguide sitting exactly
    in the baffle plane renders as a non-manifold smear, not a visible hole/join.
    - Add an optional assembly view (show_waveguide): use <mk2_waveguide_os.scad> and
    seat the waveguide in the baffle, mouth poking wg_through (0.3 mm) through the
    baffle so the two solids genuinely overlap.
    - Replace ad-hoc cut overshoots with an explicit eps (0.1 mm) on all baffle/side
    cutters so every opening pierces its panel cleanly.
    - Document the coincident-face rule in cad/README; CHANGELOG updated.
    OpenSCAD is unavailable in this environment, so the assembly was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
    [cabinet.scad]
2026-06-21 fix(cad): add tweeter rear mounting plate to waveguide
    The waveguide had two related bugs:
    1. No back plate at the throat end.
    loft_bore(wall) at z=0 is only ø44 mm — far too narrow to seat
    the ø104.3 mm H2606 faceplate or to place the 92 mm BCD screw holes.
    Without a plate the STL started at z=2 (not z=0), leaving the throat
    face completely open.
    2. Tweeter screw holes were in mid-air.
    The four BCD=92 mm holes sat at r=46 mm, but the shell at z=0–16 is
    only r≈22–25 mm — the cylinders never intersected any material.
    Fix:
    - Add a ø130 mm × 8 mm rear mounting plate (z = -tw_ring_thick … 0).
    Plate OD gives ~19 mm land around each BCD hole.
    - Replace the ol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
    [mk2_waveguide_os.scad]
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2026-06-22 cad: fix 3 waveguide/cabinet bugs
    1. Stale header comment: mk2_waveguide_os.scad said 'crossover at ~1600 Hz';
    corrected to 1250 Hz LR4 (unconfirmed, pending distortion test).
    1620 Hz is the pattern-control limit; 1250 Hz is the design target.
    2. Defensive clamp in prof_r: asin(min(1.0, sin(a0)+Lr/Rroll)) prevents
    potential domain error if floating-point accumulation yields 1+ε at
    z=D_tot. Mathematically harmless; guards against FPU edge cases.
    3. cabinet.scad syncs mouth/flange dims from waveguide: was hardcoding
    wg_mouth_w=211.7, wg_mouth_h=121.0, wg_flange_w=252, wg_flange_h=168,
    wg_flange_r=22, wg_flange_t=9. Now uses exported functions
    wg_mouth_rx(), wg_mouth_ry(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
    [cabinet.scad, mk2_waveguide_os.scad]
2026-06-22 cad: correct H2606 mounting dims from official STEP + datasheet
    Official ScanSpeak H2606-920000.STEP + PDF added to assets/datasheets/.
    All four parameters updated from verified sources:
    throat_d 28 -> 33.0 mm STEP: unique r=16.5 circle at front face (Y=44.09)
    The H2606's built-in horn exits at ø33 mm.
    WG212 is an extension waveguide starting there.
    tw_bcd 92 -> 95.0 mm Drawing: Pitch diam. ø95 ±0.1 mm
    CRITICAL: old value placed all 4 screw holes
    1.5 mm too close to centre — tweeter unmountable.
    tw_face_d 104.3 -> 104.0 mm Drawing: ø104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
    [H2606-920000.STEP, H2606-920000.x_t, mk2_waveguide_os.scad]
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2026-06-23 cad: flange 5mm + protrusion=22mm — flush with baffle OUTSIDE
    Joachim's refinement of the protrusion fix:
    - flange_thick: 9 -> 5 mm (5 mm is plenty for wood-screw mounting in the
    cabinet baffle; the back plate is a separate, 8 mm structural element)
    - protrusion default: 5 -> 22 mm so the waveguide tube ends FLUSH with the
    OUTSIDE of the cabinet baffle, not flush with the flange / inside the
    cabinet. Matches cabinet.scad's wall = 22 (panel thickness).
    After these changes:
    - tube extends z=0..97 (97 mm total depth from throat plane)
    - flange is a 5 mm-thick rounded rectangle at z=70..75 (behind the baffle)
    - baffle wall sits at z=75..97 (22 mm cabinet panel)
    - tube exits at z=97 with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
    [mk2_waveguide_os.scad]
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2026-06-27 cad: adopt JT update — bigger mouth roundover, flush-to-baffle-back
    - Lr 10→25 mm: bigger mouth roundover, smoother baffle blend, tube depth 75→90 mm
    - protrusion 22→0 mm: tube ends at baffle back (z=85), baffle hole exposes mouth
    - corner_r 22→4 mm: tighter flange fit in cabinet cutout
    - loft_bore shifted back by flange_thick: tube extends z=-5..85, overlaps back plate
    - flange now at z=80..85 (D_tot-2*flange_thick, was D_tot-flange_thick)
    - $fn 120→128
    Header comment + README tunables updated to match new design intent.
    Renders manifold (54912 faces, Z bounds -8..85.05), matches JT's uploaded STL.
    [mk2_waveguide_os.scad]
2026-06-27 cad: cabinet fully dynamic from waveguide + datasheet source-of-truth
    Cabinet.scad now derives ALL waveguide-related positioning from
    mk2_waveguide_os.scad exports - no hard-coded dimensions to drift:
    - wg_front_z() redefined to return the PHYSICAL front face
    (D_tot_ext - flange_thick = 85 mm), not the acoustic mouth (was 90).
    Old value mismatched the actual tube end by 5 mm because the tube
    is shifted back by flange_thick to overlap the back plate.
    - Added wg_back_z() = -tw_ring_thick for back plate clearances.
    - baffle_wg() flange recess moved from OUTSIDE of baffle (was wrong
    for the new 'waveguide inside cabinet' design) to INSIDE at
    Y = baffle_back - wg_flange_t .. baffle_bac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
    [cabinet.scad, mk2_parametre.csv, mk2_waveguide_os.scad]
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2026-06-27 datasheet: add ScanSpeak 15W/4434G00 reference (TODO: STEP + baffle cutout verify)
    - Downloaded official datasheet PDF (319 KB) from scan-speak.dk/datasheet/pdf/15w-4434g00.pdf
    - Created 15W-4434G00.md with mechanical dims from mounting drawing (faceplate 104, BCD 95, hole 4mm x 4, basket 45.1 mm) + T-S params from official product page (Fs 43 Hz, Re 3 ohm, Qt 0.21, sens 89.5 dB, VAS 12.8 L, Sd 80 cm^2, Bl 5.9 Tm)
    - PDF text extraction failed due to embedded fonts; dimensions verified visually from the drawing Joachim shared
    - Updated datasheets/README.md with 15W row alongside H2606
    - Extended mk2_parametre.csv with 15W mechanical + T-S parameters (kilde column points to new datasheet)
    OPE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
    [mk2_parametre.csv]
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2026-06-28 Update cabinet dimensions and waveguide settings
    Adjusted cabinet dimensions and parameters for improved design.
    Especially the correct placement of the waveguide into the front of the baffel and not the backside. Cutout's and midbass box still needs to be looked at.
    [cabinet.scad]
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2026-07-02 fix(cad): cabinet renders blank - defaults were showing cutaway
    Root cause: cabinet.scad had show_internals=true and show_waveguide=true
    as defaults. The cutaway logic removes the +X half of the cabinet, so
    front/rear/top/bottom views (which didn't override show_internals=false)
    were rendering only half a cabinet - producing near-blank 10KB images.
    - Changed defaults: show_internals=false, show_waveguide=false
    - Each CI view now explicitly sets only what it needs via -D flags
    - Flat views (front/rear/left/right/top/bottom): no cutaway
    - Cutaway views: explicit -D 'show_internals=true'
    - Assembly: explicit -D 'show_waveguide=true' without cutaway
    - STL export also benefits: exports full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
    [cabinet.scad]
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2026-07-03 feat: mk3 — SB26STAC-C000-4 tweeter + 1100 Hz crossover (v7)
    mk3 design iteration: replaces H2606/920000 with SB26STAC-C000-4
    as the primary tweeter, with crossover lowered from 1250 to 1100 Hz.
    Key changes:
    - Tweeter: SB Acoustics SB26STAC-C000-4 (Fs=750, Xmax=0.6mm, 91.5dB)
    replaces ScanSpeak H2606/920000 (Fs=1030, Xmax=0.2mm, 95.2dB)
    - Crossover: 1100 Hz LR4 (was 1250 Hz) — 350 Hz Fs margin, no test gate
    - Waveguide: cad/mk2_waveguide_sb26stac.scad (throat 28mm, BCD 88.5mm)
    - DSP: tweeter pad -2 dB (was -5 to -7 dB) — better sensitivity match
    - Simulations updated: crossover, directivity, vertical polar maps
    Improvements over mk2:
    - +8.1 dB excursion headroom at crossover
    - 0.7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
    [crossover_simulation.csv, vertical_polar_map.csv]
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2026-07-04 datasheet: extract all driver frequency response + impedance curves from PDFs
    - GRS 8SW-4HE-8: on-axis SPL + impedance/phase (vector PDF extraction)
    - ScanSpeak 15W/4434G00: on-axis + 2 off-axis SPL + impedance (raster extraction)
    - ScanSpeak H2606/920000: on-axis + 2 off-axis SPL + impedance (raster extraction)
    - SB Acoustics SB26STAC-C000-4: on-axis + 30° + 60° off-axis SPL (raster extraction)
    - All curves at 1/12 octave resolution, log-spaced 20-20k Hz (or as available)
    - params.csv for each driver with all T-S + mechanical parameters
    - H2606-920000.md and SB26STAC-C000-4.md created (were missing)
    - DATASHEET_EXTRACTION_PLAN.md: methodology and swap-checklist
    - scripts/extract_datasheet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
    [15W-4434G00_freq_response.csv, 15W-4434G00_impedance.csv, 15W-4434G00_params.csv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]
2026-07-04 sim: full mk2/mk3 system response with real datasheet curves
    Replaces simplified driver models (flat piston, tanh roll-in) with actual
    frequency response data extracted from manufacturer PDFs.
    Simulation includes:
    - GRS woofer: raw datasheet SPL + sealed cabinet (Fc=34.5, Qtc=0.62) + pair gain (+3dB) + baffle step (300mm) + LR4 LP@150
    - 15W midrange: raw datasheet SPL + baffle step + LR4 HP@150 + LP@1250 (mk2) or LP@1100 (mk3)
    - H2606 tweeter (mk2): raw SPL + WG212 loading (+3dB) + baffle step + LR4 HP@1250 + level match (-8.8dB)
    - SB26STAC tweeter (mk3): raw SPL + baffle step + LR4 HP@1100 + level match (-0.9dB)
    - Mk2: ±3dB bandwidth 660-9710 Hz, -2.1 dB in 2k-10k band (H2606 ro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
    [15W-4434G00_freq_response.csv, 15W-4434G00_impedance.csv, H2606-920000_freq_response.csv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]
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2026-07-04 fix(sim): wg_loading transition bug + 15W datasheet artifact + new PROJECT_TODO
    Three fixes to mk2_vs_mk3_realistic_response.py:
    1. wg_loading_db() parenthesization bug: the tanh transition denominator
    was 'log10(f_high) - log10(f_low) * 0.3' instead of
    '(log10(f_high) - log10(f_low)) * 0.3'. This caused the waveguide
    loading gain to smear across 500-5000 Hz instead of transitioning
    sharply at the control frequency. On-axis response was artificially
    uneven as a result.
    2. 15W datasheet extraction artifact: the npz data file had a 27 dB
    V-shaped dip at 400 Hz (62.5 dB floor) from PDF grid-line misread.
    Regenerated npz from clean CSV sources. The 400 Hz dip caused a
    2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
    [15W-4434G00_freq_response.csv, GRS-8SW-4HE-8_freq_response.csv, H2606-920000_freq_response.csv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]
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2026-07-04 docs: comprehensive mk3 update — all stale mk2 references corrected
    Updated 20+ files to reflect mk3 design (SB26STAC-C000-4, 1100 Hz):
    - DESIGN_DECISIONS: DD-013 (SB26STAC selection), DD-014 (1100 Hz XO),
    superseded notes on DD-006/010/012
    - CHANGELOG: v7/mk3 entry
    - ROADMAP: v7/mk3 entry
    - REVIEW: mk3 branch note (1250 Hz concerns partially resolved)
    - MEASUREMENTS: distortion test target 1100 Hz, SB26STAC references
    - SIMULATIONS + simulations/README: 4 new mk3 scripts listed
    - CLAUDE: mk3 branch banner + comparison table
    - cad/README: SB26STAC waveguide section
    - docs/00: mk3 branch note
    - docs/04: 1250->1100 Hz
    - docs/06: SB26STAC waveguide section
    - docs/11: distortion test item up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
    [mk2_vs_mk3_spinorama.csv]
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2026-07-04 ci(sims): update simulation outputs [skip ci]
    Triggered by: d6b5b862dd17536ca219b7bdb5929a349ac4e0de
    [system_response_realistic.csv]
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2026-07-05 feat: vertical braces, 12SW datasheet ref, PROJECT_TODO cleanup
    - cabinet.scad: added vertical_brace() module — two shelf braces in
    bass volume at ±120mm from woofer center, with woofer basket clearance
    cutouts. Prevents panel resonance in the large bass volume.
    - assets/datasheets/GRS-12SW-4HE.md: full T/S params, mechanical dims,
    sealed alignment table, push-push installation notes
    - PROJECT_TODO: removed stale system_response.py task (file deleted in
    mk3 purge), marked CI simulations.yml as verified (all 12 scripts pass),
    marked vertical braces and waveguide roundover as done
    [cabinet.scad]
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2026-07-05 ci: unified build-and-deploy workflow + fix cabinet.scad parser error
    Replaces separate simulations.yml + cad-render.yml with a single
    build-and-deploy.yml workflow that:
    1. Runs all 12 simulation scripts (non-blocking on failures)
    2. Exports STLs (waveguide + cabinet)
    3. Renders all 16 CAD views (waveguide 6 + cabinet 10)
    4. Commits all generated outputs back to repo (plots, CSVs, renders, STLs)
    5. Triggers GitHub Pages rebuild after everything is committed
    Also fixes cabinet.scad parser error (extra closing brace in
    shelf_brace module) that was causing CAD render CI to fail.
    [cabinet.scad]
2026-07-05 ci: update simulations + CAD renders [skip ci]
    Triggered by: a726e8f2c53dbd4b9ee56e5c60ddc0c083e4f265
    [cabinet.stl]
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2026-07-05 ci: update simulations + CAD renders [skip ci]
    Triggered by: badc8438fced044b99dc35b052049fd1369b9db2
    [cabinet.stl]
2026-07-05 ci: update simulations + CAD renders [skip ci]
    Triggered by: ce6ce2e68a67c4b78a19439960f0d8239d62a4e3
    [cabinet.stl]
2026-07-05 fix(cad): datasheet-driven cabinet.scad with automatic volume + clearance checks
    - Correct 15W/4434G00 dimensions from the official drawing (Ø149.3
    faceplate, Ø136.5 BCD, 4xØ5.3, 61.9 mm depth, Ø114 basket): midrange
    cutout Ø72 -> ~Ø123 estimate, flush-mount rebate, pilot holes; fix the
    mis-extracted table in assets/datasheets/15W-4434G00.md.
    - Front-mount the waveguide: flange recessed flush into the front baffle
    face, body clearance hole derived from new waveguide.scad profile
    exports (wg_outer_rx/ry, back plate and screw-pattern exports).
    - Derive the divider plate height from the mid basket envelope (12 deg
    tilt, front low) and check it against the woofer cutout; ring-s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
    [cabinet.scad, waveguide.scad]
2026-07-05 feat(v9): 18W/4424G00 midrange + mid-over-waveguide layout
    - Add cad/midrange.scad: parametric ScanSpeak 18W/4424G00 model (driver,
    2D baffle cutout, drill template, half-section) with exported dimension
    and T-S functions; drawing dims verified against the official datasheet
    (added as assets/datasheets/18W-4424G00.pdf + .md reference).
    - cabinet.scad: midrange moves to the TOP of the baffle, waveguide below,
    full-width tilted divider between them. All midrange dimensions are
    imported from midrange.scad; mid/tweeter c-c 165 mm (computed physical
    minimum, echoed); tapered waveguide body clearance hole; the real
    midrange model renders in assembly views.
    - Volumes now close: bass ~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
    [cabinet.scad, midrange.scad]
2026-07-05 ci: update simulations + CAD renders [skip ci]
    Triggered by: b985d988976adc1be88e2913b3c2da9898a44396
    [cabinet.stl]
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2026-07-05 ci: update simulations + CAD renders [skip ci]
    Triggered by: f3618e439d3c13bbdf9134513a85d62d81513940
    [cabinet.stl]
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2026-07-05 ci: update simulations + CAD renders [skip ci]
    Triggered by: e9219f3f2efbdd01a39cb17c8c26d6625ef0de30
    [cabinet.stl]
2026-07-05 ci: update simulations + CAD renders [skip ci]
    Triggered by: eb010f7814e2d49a7a8787bd3ccaa98810c17d3b
    [cabinet.stl]
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2026-07-05 ci: update simulations + CAD renders [skip ci]
    Triggered by: 5e85f6f1fbc6a20916fa794aa44f8eb5cfbe3e60
    [cabinet.stl]
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2026-07-05 ci: update simulations + CAD renders [skip ci]
    Triggered by: 557e535fe68b2150dc8bd390b7cc0b8dc6578a94
    [cabinet.stl]
2026-07-05 feat(cad): add baffel_insert + cabinet v2, replace placeholders with real drivers
    New files:
    - cad/baffel_insert_1.scad: 3D-printed baffle insert with flush rebate
    for 18W/4424G00 midrange, pocket for WG212 waveguide, screw patterns,
    backside ribbing. 285x380x15mm.
    - cad/cabinet_v2.scad: alternative cabinet using baffel insert. Same
    enclosure, bracing, woofer placement as cabinet.scad but front baffle
    has a pocket for the insert instead of individual cutouts.
    cabinet.scad updates:
    - Replaced woofer placeholder (cylinder) with real GRS-12SW-4HE model
    via use <GRS-12SW-4HE.scad> -> driver()
    - Replaced tweeter placeholder (cylinder) with real SB26STAC-C000-4
    model via use <SB26STAC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
    [baffel_insert_1.scad, cabinet.scad, cabinet_v2.scad]
2026-07-05 ci: update simulations + CAD renders [skip ci]
    Triggered by: 873ccda3cfb68ea2887798bf7422f776c495afa2
    [cabinet.stl, cabinet_v2.stl]
2026-07-05 ci: update simulations + CAD renders [skip ci]
    Triggered by: 35e71025cf15626c506673b5c71fa639a01971dd
    [cabinet.stl, cabinet_v2.stl]
2026-07-06 fix(cad): flip woofers 180° + baffel_insert fit uses real SCAD models
    - Woofer drivers were backwards (body pointing out of cabinet). Flipped
    rotate from -sign*90 to sign*90 in both cabinet.scad and cabinet_v2.scad
    - baffel_insert_1.scad fit() now uses midrange_driver() and diskant()
    from the parametric SCAD models instead of missing STL imports
    - Added use <midrange.scad> and use <SB26STAC-C000-4.scad>
    - CI renders baffel_insert fit front/iso/rear (with all drivers) + section
    - README updated with expanded baffel insert image table
    [baffel_insert_1.scad, cabinet.scad, cabinet_v2.scad]
2026-07-06 ci: update simulations + CAD renders [skip ci]
    Triggered by: 6ae0477667492aa48c5a3e899f616fe97655c196
    [cabinet.stl, cabinet_v2.stl]
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2026-07-06 fix(baffel_insert): remove wrong midrange rotation in fit view
    midrange_driver() has flange front at z=0, body toward -z, which
    already aligns with the insert's z-axis (front at +Z, back at 0).
    The rotate([90,0,0]) was left over from the STL import and pointed
    the driver downward instead of forward.
    [baffel_insert_1.scad]
2026-07-06 ci: update simulations + CAD renders [skip ci]
    Triggered by: 93342ef886645bf9b1d3dc71d61247eab72c39b9
    [cabinet.stl, cabinet_v2.stl]
2026-07-06 Add in-room, level-corrected, and post-DSP system response simulation
    Four-stage progression for mk3 v9:
    1. Anechoic (pre-DSP): real datasheet curves + baffle step + WG loading + LR4
    2. In-room: + room gain (avg living room 4.5x4x2.4m, RT60=0.4s, Schroeder 192Hz)
    3. Level-corrected: normalized to 500 Hz reference
    4. Post-DSP: EQ toward Harman in-room target (1/3 octave PEQ simulation)
    Room model: +6dB/oct below Schroeder (cap +9dB), -1.5dB/oct HF absorption above 5kHz.
    Harman target: +3.5dB bass shelf below 100Hz, -1dB/oct HF tilt above 1kHz.
    Post-DSP residual: ±0.2 dB (500Hz-10kHz).
    Uses v9 drivers: 2x GRS 12SW-4HE, ScanSpeak 18W/4424G00, SB26STAC-C000-4.
    [system_response_inroom.csv]
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2026-07-06 ci: update simulations + CAD renders [skip ci]
    Triggered by: aa256a30b5ae16fc9d94cdca237f445b891a2f9b
    [cabinet.stl, cabinet_v2.stl]
2026-07-06 Update DSP gains to level-matched values: woofer 0, mid -4.5, tweeter -7.5 dB
    Per Joachim's analysis: the previous gains (-4/0/-0.5) left woofer 8-9 dB
    below mid/tweeter. New gains match all drivers to ~87 dB acoustic output.
    Anechoic ripple 500-10k: 1.8 dB (was 3.8 dB).
    DSP correction range: ±3.5 dB (was ±6.0 dB).
    Post-DSP residual: ±0.3 dB.
    [system_response_anechoic.csv, system_response_inroom.csv]
2026-07-06 Optimize gains for in-room response + add BBC target comparison
    Gains optimized by sweep to minimize deviation from Harman in-room target:
    Woofer +1.5 dB, Mid -4.0 dB, Tweeter -9.0 dB (spreads: W-M=5.5, M-T=5.0)
    This reduces DSP correction from ±6 dB (original) to ±2.0 dB, and
    anechoic ripple from 3.8 dB to 2.7 dB (500-10k).
    Added BBC-style target comparison:
    Woofer +1.0 dB, Mid -3.5 dB, Tweeter -8.5 dB (spreads: W-M=4.5, M-T=5.0)
    -2 dB presence dip @2 kHz, warmer character, same M-T spread as Harman.
    Both targets achieve ±0.3 dB post-DSP residual.
    Updated DSP XML (mk3-v9-150-1100-lr4.xml) with Harman-optimized gains.
    [system_response_anechoic.csv, system_response_inroom.csv, target_comparison.csv]
2026-07-06 ci: update simulations + CAD renders [skip ci]
    Triggered by: 1aaf58070e0307703bb772f4bf647b1d12ec60b6
    [cabinet.stl, cabinet_v2.stl]
2026-07-06 Optimize woofer-mid crossover: 150 Hz LR4 → 200 Hz BW4 + unity woofer gain
    Crossover optimization sweep (80-200 Hz × LR2/LR4/BW2/BW4) found 200 Hz BW4
    eliminates the -1.3 dB dip at the woofer-mid transition. BW4's +3 dB sum at
    crossover compensates for woofer's natural rolloff.
    Constraints verified:
    - 18W/4424G00: 27.9 dB excursion headroom at 200 Hz (Xmax 4.5mm @ 90 dB)
    - 12SW-4HE: ka=0.46 at 200 Hz, no directivity issues
    Gains re-optimized for 200 Hz BW4, then shifted so woofer is at unity (0 dB):
    Woofer 0.0 dB (unity), Mid -4.0 dB, Tweeter -9.0 dB
    Spreads: W-M=4.0, M-T=5.0
    - Anechoic ripple 500-10k: 2.8 dB (was 3.8 dB with original gains)
    - DSP correction: ±1.3 dB (was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
    [crossover_woofer_mid.csv, system_response_anechoic.csv, system_response_inroom.csv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]
2026-07-06 ci: update simulations + CAD renders [skip ci]
    Triggered by: 316a4347f4ebc982468de33af6a0f67bdadf6312
    [cabinet.stl, cabinet_v2.stl]
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2026-07-06 ci: update simulations + CAD renders [skip ci]
    Triggered by: 7f54a51f7adc3c6b372c8257e17f5859c105b0a0
    [cabinet.stl, cabinet_v2.stl]
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2026-07-06 ci: update simulations + CAD renders [skip ci]
    Triggered by: dde8a8bc04f8a66d4712f3c02dd862935acccc57
    [cabinet.stl, cabinet_v2.stl]
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2026-07-06 ci: update simulations + CAD renders [skip ci]
    Triggered by: ad2a89d59fa244d28776a0865096fdc83ae04021
    [cabinet.stl, cabinet_v2.stl]
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2026-07-06 ci: update simulations + CAD renders [skip ci]
    Triggered by: 749559c420c4c7135831e38571e7a844acf0b16d
    [cabinet.stl, cabinet_v2.stl]
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2026-07-06 ci: update simulations + CAD renders [skip ci]
    Triggered by: 9ce80ec73f4aab8b688a04fabd8e71e57f56fa02
    [cabinet.stl, cabinet_v2.stl]
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2026-07-07 ci: update simulations + CAD renders [skip ci]
    Triggered by: 47f6e3fd4bdd7b98abae859ad765afc4335acf95
    [cabinet.stl, cabinet_v2.stl]
2026-07-07 fix(cad): correct SB26STAC SCAD dimensions from GrabCAD STEP to official datasheet
    The SB26STAC-C000-4.scad used GrabCAD STEP measurements from a *similar*
    SB Acoustics tweeter, not the actual SB26STAC. Three critical discrepancies:
    1. Bolt circle (BCD): 90 → 88.5 mm (datablad: 88.5 ±0.10)
    2. Recess diameter: 44 → 53.0 mm (datablad: 53.0 mm around dome)
    3. Faceplate OD: 100.2 → 100.0 mm (still within ±0.35 tolerance)
    These don't affect the waveguide or cabinet cutouts — they both derive
    mounting geometry from the official SB26STAC-officielle datablad via
    cad/waveguide.scad — but the tweeter SCAD would show wrong screw hole
    positions and dome recess in assembly views.
    Kilde: SB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
    [SB26STAC-C000-4.scad]
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2026-07-07 ci: update simulations + CAD renders [skip ci]
    Triggered by: 79d327a55effe68113a0df7e31894337189dd782
    [cabinet.stl, cabinet_v2.stl]
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2026-07-07 ci: update simulations + CAD renders [skip ci]
    Triggered by: e0e7622841739d3a352050f85d2487da360d62e3
    [cabinet.stl, cabinet_v2.stl]
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2026-07-07 ci: update simulations + CAD renders [skip ci]
    Triggered by: ab61555bbb596fa0707972d87262ce519ca5adad
    [cabinet.stl, cabinet_v2.stl]
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
